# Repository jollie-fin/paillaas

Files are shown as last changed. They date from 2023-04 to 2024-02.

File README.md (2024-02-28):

# paillaas

## Context

I had decided in 2021 to leave my job and start a business, Kaukolab, to develop tools for better remote learning :

I have fond memories of session of lab work during my studies. Unfortunately, they are hard to do with remote learning. The only offers I saw on the market during my research were either based on simulations, with lots of simplification compared to the real world, or based on a few video of real experiments, but with almost no user input. Part of the experience of lab work is to experiment, break things, discover what is true and not simply check what you know is true is true.

My idea was to have real physical experiments users could connect to through Internet

## Lego prototype

A fun demonstration, where a user could control a pendulum hidden under my bed through a web interface.

The stack was the following :

- A pendulum in LEGO was hanged under my bed
- An EV3 brick with a flywheel was running a micro python kernel was communicating through an SSH connection.
  Its main tasks were : - receiving commands : - shorten/lenghten the pendulum - change how the the flywheel was controlled - retrieving and transmitting measurements from sensors - angle to the vertical - executing a simple kernel to control the flywheel
- An RPI was :
  - connected through ssh to the EV3
  - running a nodejs server that would exchange with EV3 and with a puppeteer instance
  - running a puppeteer instance that would transmit through WebRTC telemetry to a peer user, transmit a videofeed, and receive commands for the EV3
  - running a Discord bot that allowed remote management from my phone
- A remote server was :
  - serving an HTML page to the puppeteer instance on the RPI
  - serving an HTML page to end-users.
    The page was : - establishing a WebRTC connection with the RPI - displaying the telemetry to the user - allowing the user to define their own data to display through a DSL

This made for a weird stack, but it was reliable enough for me to make real demo of the concept I had.

I'm sadden that I wasn't able to push this prototype beyond it's MVP status. I had big projects like a Michelson interferometer totally controlled through internet

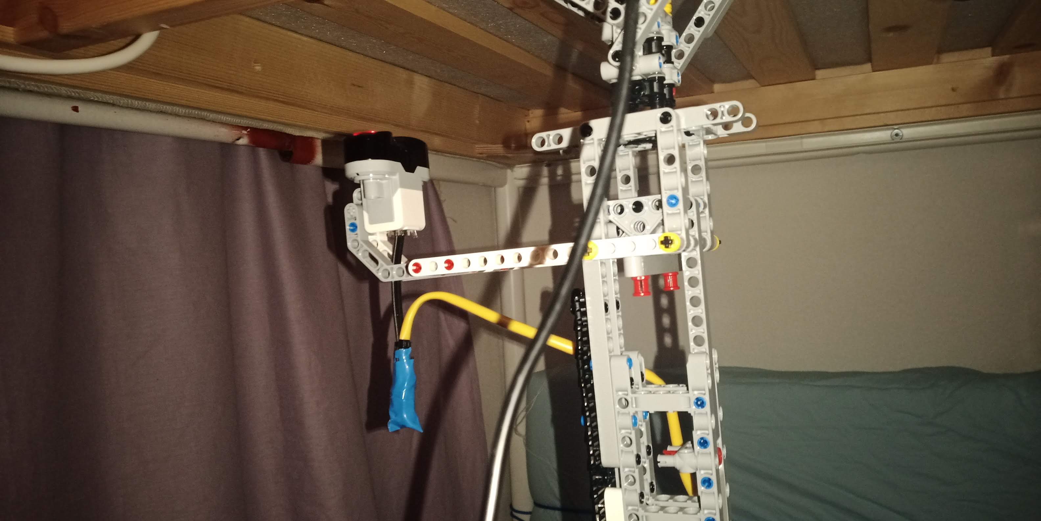
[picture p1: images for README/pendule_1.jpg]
Pendulum Angle measurement

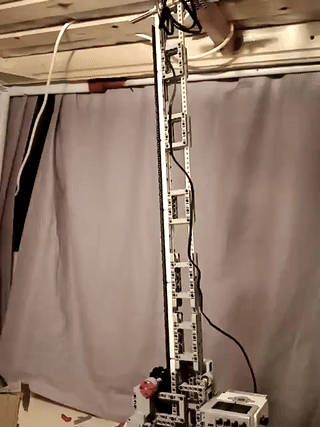
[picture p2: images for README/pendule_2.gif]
Pendulum video

Pendulum video

Some files were unfortunately lost, so I don't have a good showcase of it

## PCB design

A few pcb were designed during this adventure. Since it was in the middle of component crisis, I had to change quite a few the design, depending on component availabilities.

In hindsight, just buying a Duet Board would have been the best, but prices at that time were prohibitive

### Ethernet2serial

This is a simple serial converter, based on an atmega and an ENC28J60

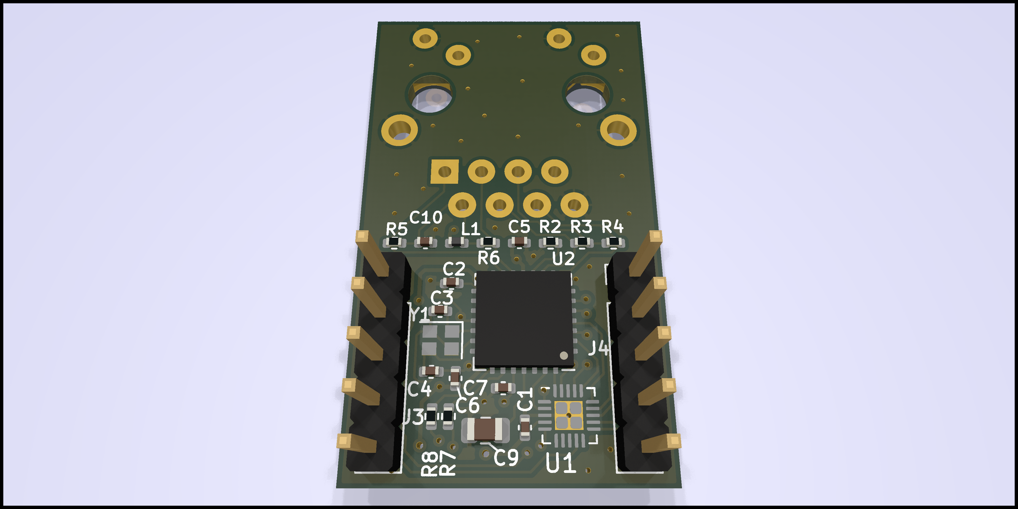
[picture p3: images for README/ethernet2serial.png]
main view Ethernet2Serial


### Motherboard

This aimed at connecting a Compute Module 4 to stepper motor drivers.

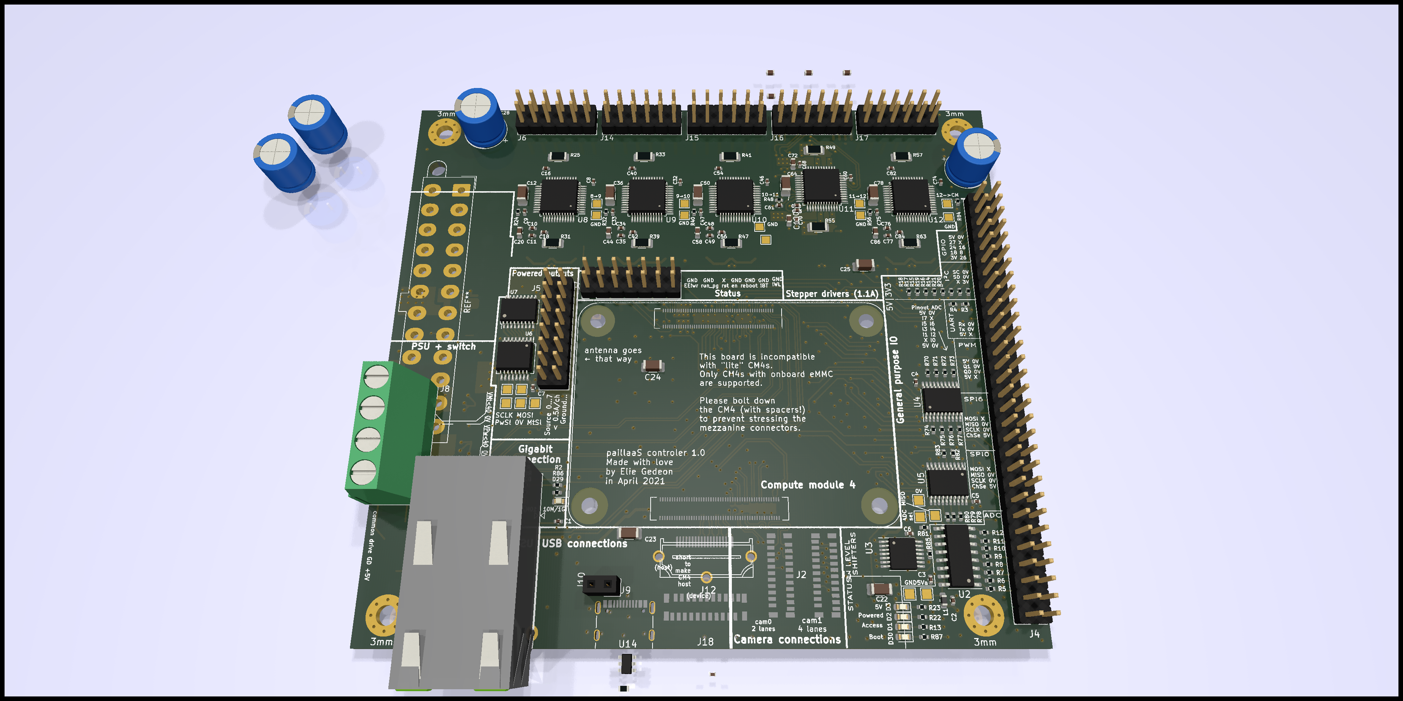
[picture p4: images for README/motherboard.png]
main view Motherboard


### Motherboard ITX-form-factor

This aimed at connecting a Compute Module 4 to stepper motor drivers. It also provides HDMI, DSI and CSI connections.

It also means I had to take care of high speed routing, with controlled impedance and differential pairs

It uses ITX screw holes, the idea being of using ITX cases

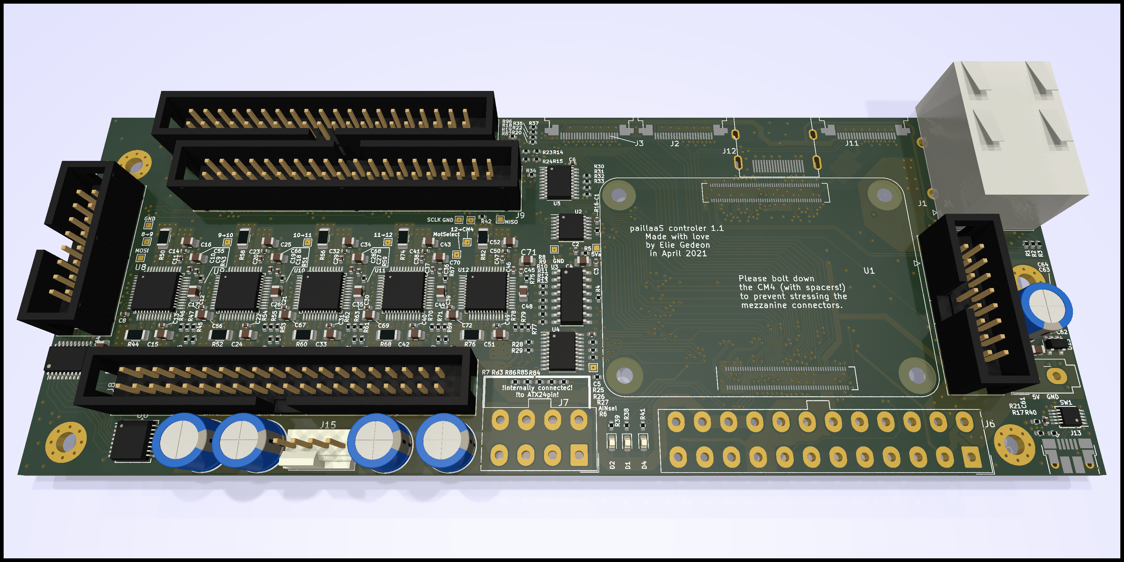
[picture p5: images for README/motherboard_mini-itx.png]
main view Motherboard


### USB2stepper

This was the final board. It is a 4 steppers board controlled by a RPI Pico, using TMC2208

A few interesting facts :

- TMC2208 were used at the limit of what they can handle
  - It means quite a bit of heat dissipation
  - Thermal vias were used to connect to the bottom side
  - A heatsink was bolted to the underside
  - To prevent short-circuit, no via (beside GND) could be used, forcing the design to be fully single layer under the heatsink
- The layer stackup was somewhat none conventional :
  - Top: signal
  - In1: GND
  - In2: GND/Power
  - Bottom: GND/Signal
  - The traces on the bottom layer were routed only over the ground plane part of In2

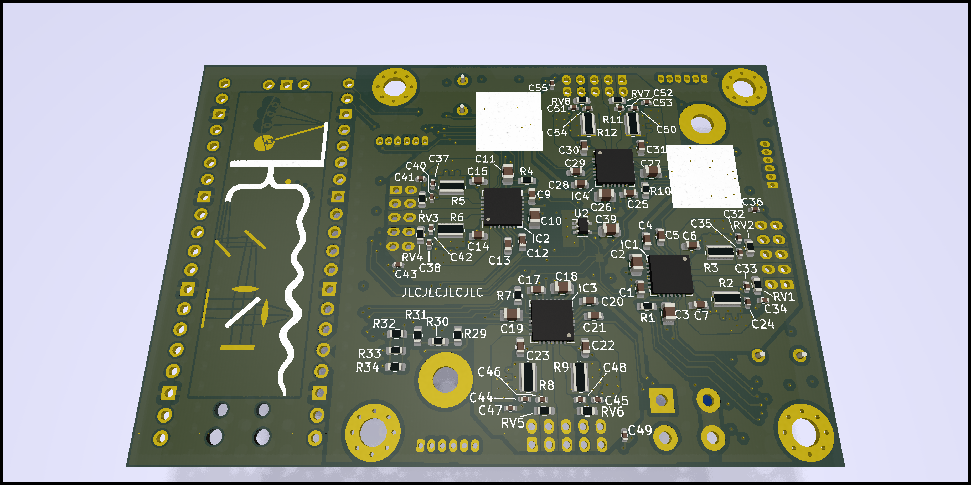
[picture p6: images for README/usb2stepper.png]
main view USB2stepper

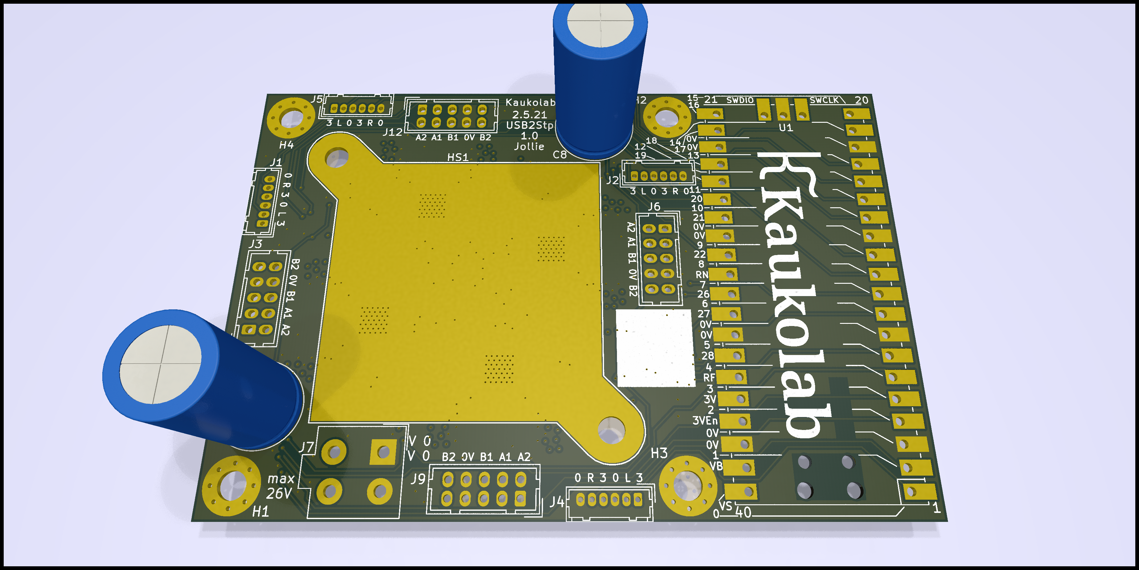
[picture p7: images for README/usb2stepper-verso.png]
underside view USB2stepper

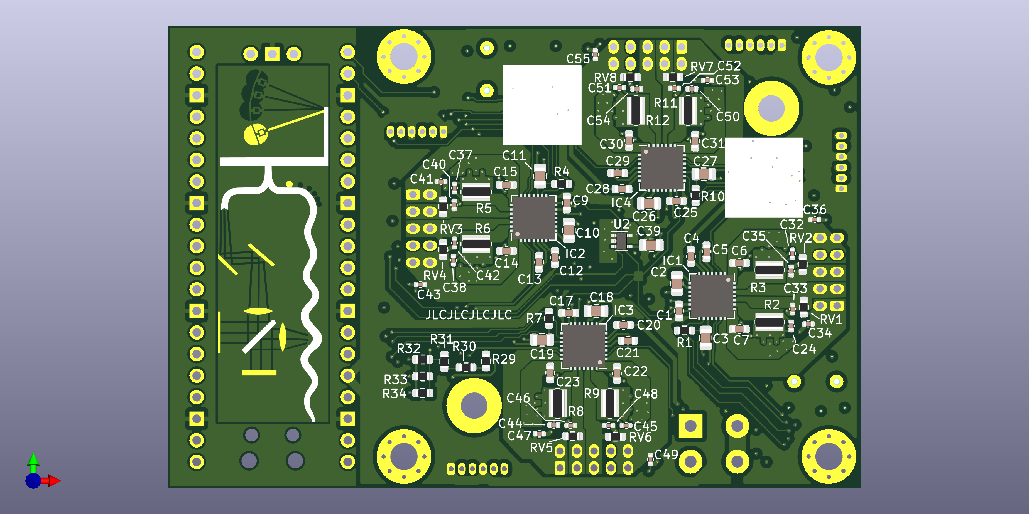
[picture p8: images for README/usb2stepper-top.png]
top view USB2stepper

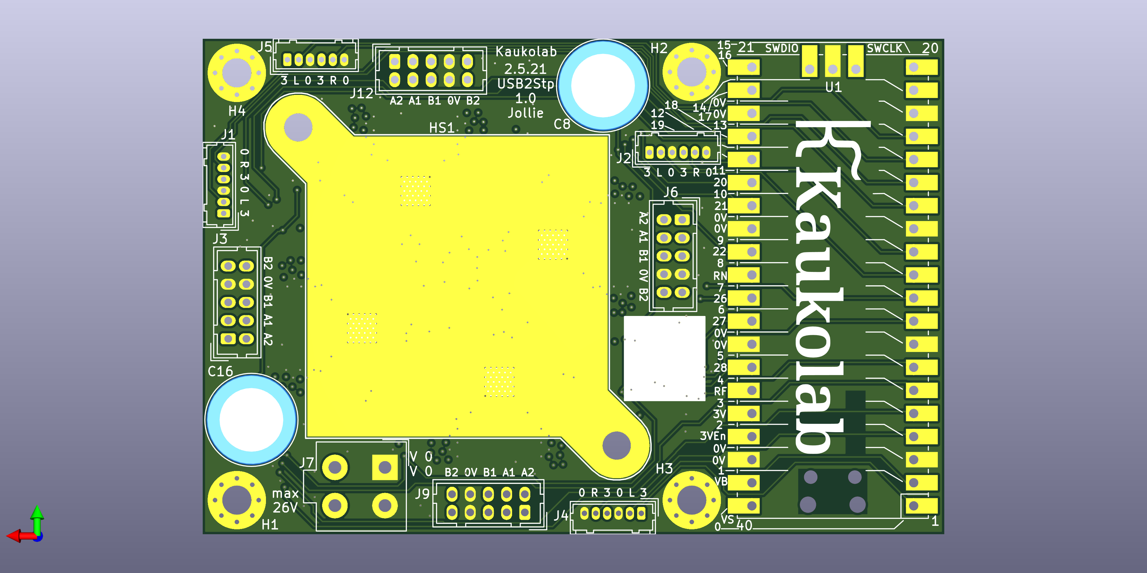
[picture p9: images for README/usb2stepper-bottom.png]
bottom view USB2stepper


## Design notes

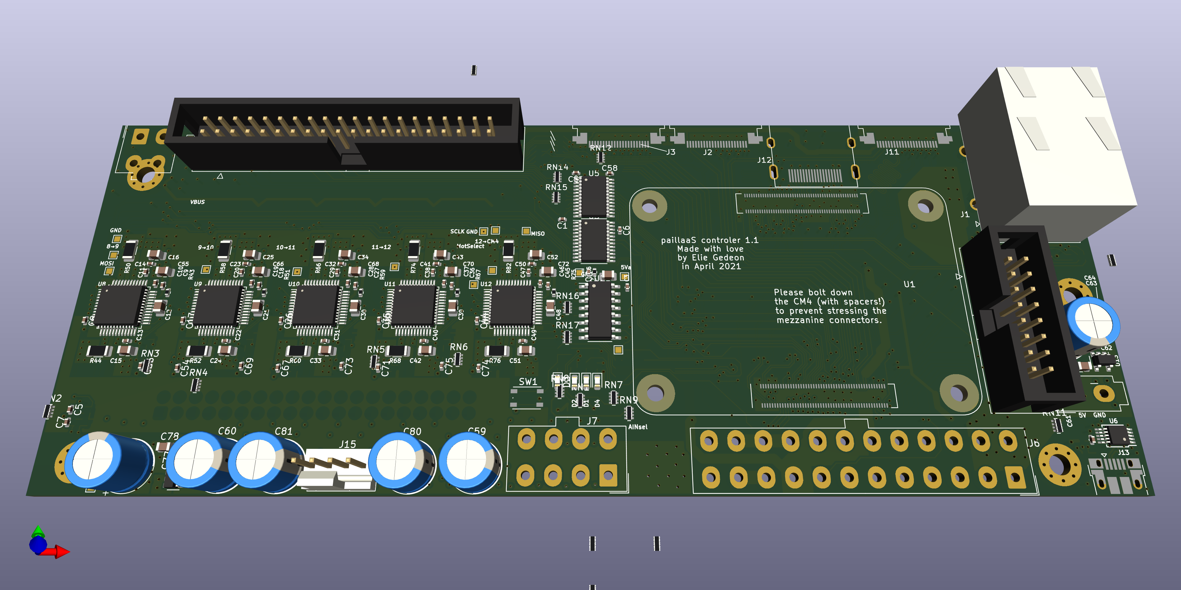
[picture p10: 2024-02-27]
images for README/motherboard_mini-itx_2209.png

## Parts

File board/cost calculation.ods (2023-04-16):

Nb | 100
PCB
width | height | area | Job fee | Price per area | Subtotal | Price per board
10 | 10 | 100 | 12.30 € | 0.19 € | 12.30 € | 0.12 €
Parts
Price mouser per board | Job fee | Handling fee | Subtotal | Price per board
60.00 € | 3.00 € | 20.00% | 7,203.00 € | 72.03 €
Stencil
Job fee | Price per area | Subtotal | Price per board
10.00 € | 0.095 € | 10.00 € | 0.10 €
Assembly
Job fee | Nb parts | Hand solder | Price per parts | Price of parts | Handling fee | Price handling | Nb components | Placement fee | Price placement | Subtotal | Price per board
75.00 € | 56 | 14 | 4.50 € | 189.00 € | 0.01 € | 100.00 € | 239 | 0.05 € | 1,195.00 € | 1,559.00 € | 15.59 €
 |  |  | 42
 | Total | Price per board
 | 8,784.30 € | 87.84 €

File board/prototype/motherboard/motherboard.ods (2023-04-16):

Source: | /home/phi/dev/paillaaS/board/prototype/motherboard/motherboard.sch
Date: | dim. 11 avril 2021 21:16:52
Tool: | Eeschema 5.1.9-73d0e3b20d~88~ubuntu20.04.1
Generator: | /usr/share/kicad/plugins/bom_csv_grouped_by_value.py
Component Count: | 239
Individual Components:
Item | Qty | Reference(s) |  |  |  |  | Value | LibPart | Footprint | Datasheet
 |  | C1 |  |  |  |  | 100n | Device:C | Capacitor_SMD:C_0402_1005Metric | ~
 |  | C2 |  |  |  |  | 100n | Device:C | Capacitor_SMD:C_0402_1005Metric | ~
 |  | C3 |  |  |  |  | 100n | Device:C | Capacitor_SMD:C_0402_1005Metric | ~
 |  | C4 |  |  |  |  | 100n | Device:C | Capacitor_SMD:C_0402_1005Metric | ~
 |  | C5 |  |  |  |  | 100n | Device:C | Capacitor_SMD:C_0402_1005Metric | ~
 |  | C6 |  |  |  |  | 100n | Device:C | Capacitor_SMD:C_0402_1005Metric | ~
 |  | C7 |  |  |  |  | 100n | Device:C | Capacitor_SMD:C_0402_1005Metric | ~
 |  | C8 |  |  |  |  | 100n | Device:C | Capacitor_SMD:C_0402_1005Metric | ~
 |  | C9 |  |  |  |  | 1u | Device:C | Capacitor_SMD:C_0402_1005Metric | ~
 |  | C10 |  |  |  |  | 22n | Device:C | Capacitor_SMD:C_0402_1005Metric | ~
 |  | C11 |  |  |  |  | 100n | Device:C | Capacitor_SMD:C_0402_1005Metric | ~
 |  | C12 |  |  |  |  | 10u | Device:C | Capacitor_SMD:C_1206_3216Metric | ~
 |  | C13 |  |  |  |  | 100n | Device:C | Capacitor_SMD:C_0402_1005Metric | ~
 |  | C14 |  |  |  |  | 470p | Device:C | Capacitor_SMD:C_0402_1005Metric | ~
 |  | C15 |  |  |  |  | 470p | Device:C | Capacitor_SMD:C_0402_1005Metric | ~
 |  | C16 |  |  |  |  | 100n | Device:C | Capacitor_SMD:C_0402_1005Metric | ~
 |  | C17 |  |  |  |  | 470p | Device:C | Capacitor_SMD:C_0402_1005Metric | ~
 |  | C18 |  |  |  |  | 100n | Device:C | Capacitor_SMD:C_0402_1005Metric | ~
 |  | C19 |  |  |  |  | 470p | Device:C | Capacitor_SMD:C_0402_1005Metric | ~
 |  | C20 |  |  |  |  | 1u | Device:C | Capacitor_SMD:C_0603_1608Metric | ~
 |  | C21 |  |  |  |  | 100n | Device:C | Capacitor_SMD:C_0402_1005Metric | ~
 |  | C22 |  |  |  |  | 10u | Device:C | Capacitor_SMD:C_1206_3216Metric | ~
 |  | C23 |  |  |  |  | 10u | Device:C | Capacitor_SMD:C_1206_3216Metric | ~
 |  | C24 |  |  |  |  | 10u | Device:C | Capacitor_SMD:C_1206_3216Metric | ~
 |  | C25 |  |  |  |  | 10u | Device:C | Capacitor_SMD:C_1206_3216Metric | ~
 |  | C26 |  |  |  |  | 10u | Device:C | Capacitor_SMD:C_1206_3216Metric | ~
 |  | C27 |  |  |  |  | 10u | Device:C | Capacitor_SMD:C_1206_3216Metric | ~
 |  | C28 |  |  |  |  | 100u | Device:CP | Capacitor_THT:CP_Radial_D8.0mm_P3.50mm | ~
 |  | C29 |  |  |  |  | 100u | Device:CP | Capacitor_THT:CP_Radial_D8.0mm_P3.50mm | ~
 |  | C30 |  |  |  |  | 10n | Device:C | Capacitor_SMD:C_0402_1005Metric | ~
 |  | C31 |  |  |  |  | 100u | Device:CP | Capacitor_THT:CP_Radial_D8.0mm_P3.50mm | ~
 |  | C32 |  |  |  |  | 100n | Device:C | Capacitor_SMD:C_0402_1005Metric | ~
 |  | C33 |  |  |  |  | 1u | Device:C | Capacitor_SMD:C_0402_1005Metric | ~
 |  | C34 |  |  |  |  | 22n | Device:C | Capacitor_SMD:C_0402_1005Metric | ~
 |  | C35 |  |  |  |  | 100n | Device:C | Capacitor_SMD:C_0402_1005Metric | ~
 |  | C36 |  |  |  |  | 10u | Device:C | Capacitor_SMD:C_1206_3216Metric | ~
 |  | C37 |  |  |  |  | 100n | Device:C | Capacitor_SMD:C_0402_1005Metric | ~
 |  | C38 |  |  |  |  | 470p | Device:C | Capacitor_SMD:C_0402_1005Metric | ~
 |  | C39 |  |  |  |  | 470p | Device:C | Capacitor_SMD:C_0402_1005Metric | ~
 |  | C40 |  |  |  |  | 100n | Device:C | Capacitor_SMD:C_0402_1005Metric | ~
 |  | C41 |  |  |  |  | 470p | Device:C | Capacitor_SMD:C_0402_1005Metric | ~
 |  | C42 |  |  |  |  | 100n | Device:C | Capacitor_SMD:C_0402_1005Metric | ~
 |  | C43 |  |  |  |  | 470p | Device:C | Capacitor_SMD:C_0402_1005Metric | ~
 |  | C44 |  |  |  |  | 1u | Device:C | Capacitor_SMD:C_0603_1608Metric | ~
 |  | C45 |  |  |  |  | 100n | Device:C | Capacitor_SMD:C_0402_1005Metric | ~
 |  | C46 |  |  |  |  | 100n | Device:C | Capacitor_SMD:C_0402_1005Metric | ~
 |  | C47 |  |  |  |  | 1u | Device:C | Capacitor_SMD:C_0402_1005Metric | ~
 |  | C48 |  |  |  |  | 22n | Device:C | Capacitor_SMD:C_0402_1005Metric | ~
 |  | C49 |  |  |  |  | 100n | Device:C | Capacitor_SMD:C_0402_1005Metric | ~
 |  | C50 |  |  |  |  | 10u | Device:C | Capacitor_SMD:C_1206_3216Metric | ~
 |  | C51 |  |  |  |  | 100n | Device:C | Capacitor_SMD:C_0402_1005Metric | ~
 |  | C52 |  |  |  |  | 470p | Device:C | Capacitor_SMD:C_0402_1005Metric | ~
 |  | C53 |  |  |  |  | 470p | Device:C | Capacitor_SMD:C_0402_1005Metric | ~
 |  | C54 |  |  |  |  | 100n | Device:C | Capacitor_SMD:C_0402_1005Metric | ~
 |  | C55 |  |  |  |  | 470p | Device:C | Capacitor_SMD:C_0402_1005Metric | ~
 |  | C56 |  |  |  |  | 100n | Device:C | Capacitor_SMD:C_0402_1005Metric | ~
 |  | C57 |  |  |  |  | 470p | Device:C | Capacitor_SMD:C_0402_1005Metric | ~
 |  | C58 |  |  |  |  | 1u | Device:C | Capacitor_SMD:C_0603_1608Metric | ~
 |  | C59 |  |  |  |  | 100n | Device:C | Capacitor_SMD:C_0402_1005Metric | ~
 |  | C60 |  |  |  |  | 100n | Device:C | Capacitor_SMD:C_0402_1005Metric | ~
 |  | C61 |  |  |  |  | 1u | Device:C | Capacitor_SMD:C_0402_1005Metric | ~
 |  | C62 |  |  |  |  | 22n | Device:C | Capacitor_SMD:C_0402_1005Metric | ~
 |  | C63 |  |  |  |  | 100n | Device:C | Capacitor_SMD:C_0402_1005Metric | ~
 |  | C64 |  |  |  |  | 10u | Device:C | Capacitor_SMD:C_1206_3216Metric | ~
 |  | C65 |  |  |  |  | 100n | Device:C | Capacitor_SMD:C_0402_1005Metric | ~
 |  | C66 |  |  |  |  | 470p | Device:C | Capacitor_SMD:C_0402_1005Metric | ~
 |  | C67 |  |  |  |  | 470p | Device:C | Capacitor_SMD:C_0402_1005Metric | ~
 |  | C68 |  |  |  |  | 100n | Device:C | Capacitor_SMD:C_0402_1005Metric | ~
 |  | C69 |  |  |  |  | 470p | Device:C | Capacitor_SMD:C_0402_1005Metric | ~
 |  | C70 |  |  |  |  | 100n | Device:C | Capacitor_SMD:C_0402_1005Metric | ~
 |  | C71 |  |  |  |  | 470p | Device:C | Capacitor_SMD:C_0402_1005Metric | ~
 |  | C72 |  |  |  |  | 1u | Device:C | Capacitor_SMD:C_0603_1608Metric | ~
 |  | C73 |  |  |  |  | 100n | Device:C | Capacitor_SMD:C_0402_1005Metric | ~
 |  | C74 |  |  |  |  | 100n | Device:C | Capacitor_SMD:C_0402_1005Metric | ~
 |  | C75 |  |  |  |  | 1u | Device:C | Capacitor_SMD:C_0402_1005Metric | ~
 |  | C76 |  |  |  |  | 22n | Device:C | Capacitor_SMD:C_0402_1005Metric | ~
 |  | C77 |  |  |  |  | 100n | Device:C | Capacitor_SMD:C_0402_1005Metric | ~
 |  | C78 |  |  |  |  | 10u | Device:C | Capacitor_SMD:C_1206_3216Metric | ~
 |  | C79 |  |  |  |  | 100n | Device:C | Capacitor_SMD:C_0402_1005Metric | ~
 |  | C80 |  |  |  |  | 470p | Device:C | Capacitor_SMD:C_0402_1005Metric | ~
 |  | C81 |  |  |  |  | 470p | Device:C | Capacitor_SMD:C_0402_1005Metric | ~
 |  | C82 |  |  |  |  | 100n | Device:C | Capacitor_SMD:C_0402_1005Metric | ~
 |  | C83 |  |  |  |  | 470p | Device:C | Capacitor_SMD:C_0402_1005Metric | ~
 |  | C84 |  |  |  |  | 100n | Device:C | Capacitor_SMD:C_0402_1005Metric | ~
 |  | C85 |  |  |  |  | 470p | Device:C | Capacitor_SMD:C_0402_1005Metric | ~
 |  | C86 |  |  |  |  | 1u | Device:C | Capacitor_SMD:C_0603_1608Metric | ~
 |  | C87 |  |  |  |  | 100n | Device:C | Capacitor_SMD:C_0402_1005Metric | ~
 |  | C88 |  |  |  |  | 2n7 | Device:C | Capacitor_SMD:C_0402_1005Metric | ~
 |  | C89 |  |  |  |  | 100n | Device:C | Capacitor_SMD:C_0402_1005Metric | ~
 |  | C90 |  |  |  |  | 33p | Device:C | Capacitor_SMD:C_0402_1005Metric | ~
 |  | C91 |  |  |  |  | 100u | Device:CP | Capacitor_THT:CP_Radial_D8.0mm_P3.50mm | ~
 |  | C92 |  |  |  |  | 10n | Device:C | Capacitor_SMD:C_0402_1005Metric | ~
 |  | C93 |  |  |  |  | 47p | Device:C | Capacitor_SMD:C_0402_1005Metric | ~
 |  | C94 |  |  |  |  | 22u | Device:C | Capacitor_SMD:C_1206_3216Metric | ~
 |  | C95 |  |  |  |  | 22u | Device:C | Capacitor_SMD:C_1206_3216Metric | ~
 |  | C96 |  |  |  |  | 22u | Device:C | Capacitor_SMD:C_1206_3216Metric | ~
 |  | C97 |  |  |  |  | 1u | Device:C | Capacitor_SMD:C_0603_1608Metric | ~
 |  | C98 |  |  |  |  | 1u | Device:C | Capacitor_SMD:C_0603_1608Metric | ~
 |  | C99 |  |  |  |  | 1u | Device:C | Capacitor_SMD:C_0603_1608Metric | ~
 |  | C100 |  |  |  |  | 1u | Device:C | Capacitor_SMD:C_0603_1608Metric | ~
 |  | C101 |  |  |  |  | 1u | Device:C | Capacitor_SMD:C_0603_1608Metric | ~
 |  | D1 |  |  |  |  | GREEN | Device:LED | LED_SMD:LED_0603_1608Metric | ~
 |  | D2 |  |  |  |  | RED | Device:LED | LED_SMD:LED_0603_1608Metric | ~
 |  | D3 |  |  |  |  | BLUE | Device:LED | LED_SMD:LED_0603_1608Metric | ~
 |  | D4 |  |  |  |  | SP0505BAHT | Power_Protection:SP0505BAHT | Package_TO_SOT_SMD:SOT-23-6 | http://www.littelfuse.com/~/media/files/littelfuse/technical%20resources/documents/data%20sheets/sp05xxba.pdf
 |  | D5 |  |  |  |  | SP0505BAHT | Power_Protection:SP0505BAHT | Package_TO_SOT_SMD:SOT-23-6 | http://www.littelfuse.com/~/media/files/littelfuse/technical%20resources/documents/data%20sheets/sp05xxba.pdf
 |  | D6 |  |  |  |  | SP0505BAHT | Power_Protection:SP0505BAHT | Package_TO_SOT_SMD:SOT-23-6 | http://www.littelfuse.com/~/media/files/littelfuse/technical%20resources/documents/data%20sheets/sp05xxba.pdf
 |  | D7 |  |  |  |  | SP0505BAHT | Power_Protection:SP0505BAHT | Package_TO_SOT_SMD:SOT-23-6 | http://www.littelfuse.com/~/media/files/littelfuse/technical%20resources/documents/data%20sheets/sp05xxba.pdf
 |  | D8 |  |  |  |  | SMBJ43A | Diode:SM6T22A | Diode_SMD:D_SMB | https://www.st.com/resource/en/datasheet/sm6t.pdf
 |  | D9 |  |  |  |  | SMBJ43A | Diode:SM6T22A | Diode_SMD:D_SMB | https://www.st.com/resource/en/datasheet/sm6t.pdf
 |  | D10 |  |  |  |  | SP0505BAHT | Power_Protection:SP0505BAHT | Package_TO_SOT_SMD:SOT-23-6 | http://www.littelfuse.com/~/media/files/littelfuse/technical%20resources/documents/data%20sheets/sp05xxba.pdf
 |  | D26 |  |  |  |  | SDT8A60VP5 | Device:D_Schottky | Diode_SMD:D_PowerDI-5 | ~
 |  | D27 |  |  |  |  | SDT8A60VP5 | Device:D_Schottky | Diode_SMD:D_PowerDI-5 | ~
 |  | D29 |  |  |  |  | LED | Device:LED | LED_SMD:LED_0603_1608Metric | ~
 |  | D30 |  |  |  |  | YELLOW | Device:LED | LED_SMD:LED_0603_1608Metric | ~
 |  | H1 |  |  |  |  | MountingHole_Pad | Mechanical:MountingHole_Pad | MountingHole:MountingHole_3.2mm_M3_Pad_Via | ~
 |  | H2 |  |  |  |  | MountingHole_Pad | Mechanical:MountingHole_Pad | MountingHole:MountingHole_3.2mm_M3_Pad_Via | ~
 |  | H3 |  |  |  |  | MountingHole_Pad | Mechanical:MountingHole_Pad | MountingHole:MountingHole_3.2mm_M3_Pad_Via | ~
 |  | H4 |  |  |  |  | MountingHole_Pad | Mechanical:MountingHole_Pad | MountingHole:MountingHole_3.2mm_M3_Pad_Via | ~
 |  | J1 |  |  |  |  | JK0654218Z | Connector:JK0654219 | Connector_RJ:RJ45_Pulse_JK0654219NL_Horizontal | https://media.digikey.com/pdf/Data%20Sheets/Pulse%20PDFs/JK%20Series.pdf
 |  | J2 |  |  |  |  | Conn_01x22_MountingPin | Connector_Generic_MountingPin:Conn_01x22_MountingPin | library:5019512230_1x22-1MP_P0.5mm_Vertical | ~
 |  | J3 |  |  |  |  | Conn_01x22_MountingPin | Connector_Generic_MountingPin:Conn_01x22_MountingPin | library:5019512230_1x22-1MP_P0.5mm_Vertical | ~
 |  | J4 |  |  |  |  | Conn_02x30_Odd_Even | Connector_Generic:Conn_02x30_Odd_Even | Connector_PinHeader_2.54mm:PinHeader_2x30_P2.54mm_Vertical | ~
 |  | J5 |  |  |  |  | Conn_02x08_Odd_Even | Connector_Generic:Conn_02x08_Odd_Even | Connector_PinHeader_2.54mm:PinHeader_2x08_P2.54mm_Vertical | ~
 |  | J6 |  |  |  |  | pin_header_02x06 | Connector_Generic:Conn_02x06_Odd_Even | Connector_PinHeader_2.54mm:PinHeader_2x06_P2.54mm_Vertical | ~
 |  | J7 |  |  |  |  | Conn_02x07_Odd_Even | Connector_Generic:Conn_02x07_Odd_Even | Connector_PinHeader_2.54mm:PinHeader_2x07_P2.54mm_Vertical | ~
 |  | J8 |  |  |  |  | Conn_01x04 | Connector_Generic:Conn_01x04 | TerminalBlock_Phoenix:TerminalBlock_Phoenix_MKDS-1,5-4-5.08_1x04_P5.08mm_Horizontal | ~
 |  | J9 |  |  |  |  | USB_C_Receptacle_USB2.0 | Connector:USB_C_Receptacle_USB2.0 | Connector_USB:USB_C_Receptacle_Palconn_UTC16-G | https://www.usb.org/sites/default/files/documents/usb_type-c.zip
 |  | J10 |  |  |  |  | Conn_01x02 | Connector_Generic:Conn_01x02 | Connector_PinSocket_2.54mm:PinSocket_1x02_P2.54mm_Vertical | ~
 |  | J11 |  |  |  |  | Conn_01x02 | Connector_Generic:Conn_01x02 | Connector_PinSocket_2.54mm:PinSocket_1x02_P2.54mm_Vertical | ~
 |  | J12 |  |  |  |  | HDMI_A | Connector:HDMI_A | library:HDMI_vertical_476591102 | https://en.wikipedia.org/wiki/HDMI
 |  | J13 |  |  |  |  | Conn_02x04_Odd_Even | Connector_Generic:Conn_02x04_Odd_Even | Connector_PinSocket_2.54mm:PinSocket_2x04_P2.54mm_Vertical | ~
 |  | J14 |  |  |  |  | pin_header_02x06 | Connector_Generic:Conn_02x06_Odd_Even | Connector_PinHeader_2.54mm:PinHeader_2x06_P2.54mm_Vertical | ~
 |  | J15 |  |  |  |  | pin_header_02x06 | Connector_Generic:Conn_02x06_Odd_Even | Connector_PinHeader_2.54mm:PinHeader_2x06_P2.54mm_Vertical | ~
 |  | J16 |  |  |  |  | pin_header_02x06 | Connector_Generic:Conn_02x06_Odd_Even | Connector_PinHeader_2.54mm:PinHeader_2x06_P2.54mm_Vertical | ~
 |  | J17 |  |  |  |  | pin_header_02x06 | Connector_Generic:Conn_02x06_Odd_Even | Connector_PinHeader_2.54mm:PinHeader_2x06_P2.54mm_Vertical | ~
 |  | J18 |  |  |  |  | Conn_01x22_MountingPin | Connector_Generic_MountingPin:Conn_01x22_MountingPin | library:5019512230_1x22-1MP_P0.5mm_Vertical | ~
 |  | L1 |  |  |  |  | 15uH | Device:L | Inductor_SMD:L_0603_1608Metric | ~
 |  | L2 |  |  |  |  | 3.6uH | Device:L | Inductor_SMD:L_1210_3225Metric | ~
 |  | R1 |  |  |  |  | 470 | Device:R | Resistor_SMD:R_0402_1005Metric | ~
 |  | R2 |  |  |  |  | 470 | Device:R | Resistor_SMD:R_0402_1005Metric | ~
 |  | R3 |  |  |  |  | 1K8 | Device:R | Resistor_SMD:R_0402_1005Metric | ~
 |  | R4 |  |  |  |  | 1K8 | Device:R | Resistor_SMD:R_0402_1005Metric | ~
 |  | R5 |  |  |  |  | 100 | Device:R | Resistor_SMD:R_0402_1005Metric | ~
 |  | R6 |  |  |  |  | 100 | Device:R | Resistor_SMD:R_0402_1005Metric | ~
 |  | R7 |  |  |  |  | 100 | Device:R | Resistor_SMD:R_0402_1005Metric | ~
 |  | R8 |  |  |  |  | 100 | Device:R | Resistor_SMD:R_0402_1005Metric | ~
 |  | R9 |  |  |  |  | 100 | Device:R | Resistor_SMD:R_0402_1005Metric | ~
 |  | R10 |  |  |  |  | 100 | Device:R | Resistor_SMD:R_0402_1005Metric | ~
 |  | R11 |  |  |  |  | 100 | Device:R | Resistor_SMD:R_0402_1005Metric | ~
 |  | R12 |  |  |  |  | 100 | Device:R | Resistor_SMD:R_0402_1005Metric | ~
 |  | R13 |  |  |  |  | 4K7 | Device:R | Resistor_SMD:R_0402_1005Metric | ~
 |  | R14 |  |  |  |  | 100 | Device:R | Resistor_SMD:R_0402_1005Metric | ~
 |  | R15 |  |  |  |  | 100 | Device:R | Resistor_SMD:R_0402_1005Metric | ~
 |  | R16 |  |  |  |  | 100 | Device:R | Resistor_SMD:R_0402_1005Metric | ~
 |  | R17 |  |  |  |  | 100 | Device:R | Resistor_SMD:R_0402_1005Metric | ~
 |  | R18 |  |  |  |  | 100 | Device:R | Resistor_SMD:R_0402_1005Metric | ~
 |  | R19 |  |  |  |  | 100 | Device:R | Resistor_SMD:R_0402_1005Metric | ~
 |  | R20 |  |  |  |  | 100 | Device:R | Resistor_SMD:R_0402_1005Metric | ~
 |  | R21 |  |  |  |  | 100 | Device:R | Resistor_SMD:R_0402_1005Metric | ~
 |  | R22 |  |  |  |  | 4K7 | Device:R | Resistor_SMD:R_0402_1005Metric | ~
 |  | R23 |  |  |  |  | 4K7 | Device:R | Resistor_SMD:R_0402_1005Metric | ~
 |  | R24 |  |  |  |  | 10 | Device:R | Resistor_SMD:R_0402_1005Metric | ~
 |  | R25 |  |  |  |  | 0.21 | Device:R | Resistor_SMD:R_1206_3216Metric | ~
 |  | R26 |  |  |  |  | 4K7 | Device:R | Resistor_SMD:R_0402_1005Metric | ~
 |  | R27 |  |  |  |  | 4K7 | Device:R | Resistor_SMD:R_0402_1005Metric | ~
 |  | R28 |  |  |  |  | 4K7 | Device:R | Resistor_SMD:R_0402_1005Metric | ~
 |  | R29 |  |  |  |  | 4K7 | Device:R | Resistor_SMD:R_0402_1005Metric | ~
 |  | R30 |  |  |  |  | 4K7 | Device:R | Resistor_SMD:R_0402_1005Metric | ~
 |  | R31 |  |  |  |  | 0.21 | Device:R | Resistor_SMD:R_1206_3216Metric | ~
 |  | R32 |  |  |  |  | 10 | Device:R | Resistor_SMD:R_0402_1005Metric | ~
 |  | R33 |  |  |  |  | 0.21 | Device:R | Resistor_SMD:R_1206_3216Metric | ~
 |  | R34 |  |  |  |  | 4K7 | Device:R | Resistor_SMD:R_0402_1005Metric | ~
 |  | R35 |  |  |  |  | 4K7 | Device:R | Resistor_SMD:R_0402_1005Metric | ~
 |  | R36 |  |  |  |  | 4K7 | Device:R | Resistor_SMD:R_0402_1005Metric | ~
 |  | R37 |  |  |  |  | 4K7 | Device:R | Resistor_SMD:R_0402_1005Metric | ~
 |  | R38 |  |  |  |  | 4K7 | Device:R | Resistor_SMD:R_0402_1005Metric | ~
 |  | R39 |  |  |  |  | 0.21 | Device:R | Resistor_SMD:R_1206_3216Metric | ~
 |  | R40 |  |  |  |  | 10 | Device:R | Resistor_SMD:R_0402_1005Metric | ~
 |  | R41 |  |  |  |  | 0.21 | Device:R | Resistor_SMD:R_1206_3216Metric | ~
 |  | R42 |  |  |  |  | 4K7 | Device:R | Resistor_SMD:R_0402_1005Metric | ~
 |  | R43 |  |  |  |  | 4K7 | Device:R | Resistor_SMD:R_0402_1005Metric | ~
 |  | R44 |  |  |  |  | 4K7 | Device:R | Resistor_SMD:R_0402_1005Metric | ~
 |  | R45 |  |  |  |  | 4K7 | Device:R | Resistor_SMD:R_0402_1005Metric | ~
 |  | R46 |  |  |  |  | 4K7 | Device:R | Resistor_SMD:R_0402_1005Metric | ~
 |  | R47 |  |  |  |  | 0.21 | Device:R | Resistor_SMD:R_1206_3216Metric | ~
 |  | R48 |  |  |  |  | 10 | Device:R | Resistor_SMD:R_0402_1005Metric | ~
 |  | R49 |  |  |  |  | 0.21 | Device:R | Resistor_SMD:R_1206_3216Metric | ~
 |  | R50 |  |  |  |  | 4K7 | Device:R | Resistor_SMD:R_0402_1005Metric | ~
 |  | R51 |  |  |  |  | 4K7 | Device:R | Resistor_SMD:R_0402_1005Metric | ~
 |  | R52 |  |  |  |  | 4K7 | Device:R | Resistor_SMD:R_0402_1005Metric | ~
 |  | R53 |  |  |  |  | 4K7 | Device:R | Resistor_SMD:R_0402_1005Metric | ~
 |  | R54 |  |  |  |  | 4K7 | Device:R | Resistor_SMD:R_0402_1005Metric | ~
 |  | R55 |  |  |  |  | 0.21 | Device:R | Resistor_SMD:R_1206_3216Metric | ~
 |  | R56 |  |  |  |  | 10 | Device:R | Resistor_SMD:R_0402_1005Metric | ~
 |  | R57 |  |  |  |  | 0.21 | Device:R | Resistor_SMD:R_1206_3216Metric | ~
 |  | R58 |  |  |  |  | 4K7 | Device:R | Resistor_SMD:R_0402_1005Metric | ~
 |  | R59 |  |  |  |  | 4K7 | Device:R | Resistor_SMD:R_0402_1005Metric | ~
 |  | R60 |  |  |  |  | 4K7 | Device:R | Resistor_SMD:R_0402_1005Metric | ~
 |  | R61 |  |  |  |  | 4K7 | Device:R | Resistor_SMD:R_0402_1005Metric | ~
 |  | R62 |  |  |  |  | 4K7 | Device:R | Resistor_SMD:R_0402_1005Metric | ~
 |  | R63 |  |  |  |  | 0.21 | Device:R | Resistor_SMD:R_1206_3216Metric | ~
 |  | R64 |  |  |  |  | 15k8 | Device:R | Resistor_SMD:R_0402_1005Metric | ~
 |  | R65 |  |  |  |  | 115k 1% | Device:R | Resistor_SMD:R_0402_1005Metric | ~
 |  | R66 |  |  |  |  | 22k1 1% | Device:R | Resistor_SMD:R_0402_1005Metric | ~
 |  | R70 |  |  |  |  | 100 | Device:R | Resistor_SMD:R_0402_1005Metric | ~
 |  | R71 |  |  |  |  | 100 | Device:R | Resistor_SMD:R_0402_1005Metric | ~
 |  | R72 |  |  |  |  | 100 | Device:R | Resistor_SMD:R_0402_1005Metric | ~
 |  | R73 |  |  |  |  | 100 | Device:R | Resistor_SMD:R_0402_1005Metric | ~
 |  | R74 |  |  |  |  | 100 | Device:R | Resistor_SMD:R_0402_1005Metric | ~
 |  | R75 |  |  |  |  | 100 | Device:R | Resistor_SMD:R_0402_1005Metric | ~
 |  | R76 |  |  |  |  | 100 | Device:R | Resistor_SMD:R_0402_1005Metric | ~
 |  | R77 |  |  |  |  | 100 | Device:R | Resistor_SMD:R_0402_1005Metric | ~
 |  | R78 |  |  |  |  | 100 | Device:R | Resistor_SMD:R_0402_1005Metric | ~
 |  | R79 |  |  |  |  | 30 | Device:R | Resistor_SMD:R_0402_1005Metric | ~
 |  | R80 |  |  |  |  | 30 | Device:R | Resistor_SMD:R_0402_1005Metric | ~
 |  | R81 |  |  |  |  | 30 | Device:R | Resistor_SMD:R_0402_1005Metric | ~
 |  | R82 |  |  |  |  | 30 | Device:R | Resistor_SMD:R_0402_1005Metric | ~
 |  | R83 |  |  |  |  | 30 | Device:R | Resistor_SMD:R_0402_1005Metric | ~
 |  | R84 |  |  |  |  | 30 | Device:R | Resistor_SMD:R_0402_1005Metric | ~
 |  | R85 |  |  |  |  | 10k | Device:R | Resistor_SMD:R_0402_1005Metric | ~
 |  | R86 |  |  |  |  | 470 | Device:R | Resistor_SMD:R_0402_1005Metric | ~
 |  | R87 |  |  |  |  | 4K7 | Device:R | Resistor_SMD:R_0402_1005Metric | ~
 |  | R89 |  |  |  |  | R | Device:R | Resistor_SMD:R_1218_3246Metric | ~
 |  | TH1 |  |  |  |  | Thermistor_PTC | Device:Thermistor_PTC | Resistor_SMD:R_0603_1608Metric | ~
 |  | U1 |  |  |  |  | Compute_Module_4_Functional | Raspberry_Pi_Compute_Module_4:Compute_Module_4_Functional | RPi_Compute_Module_4:Raspberry-Pi-4-Compute-Module
 |  | U2 |  |  |  |  | MCP3008 | Analog_ADC:MCP3008 | Package_SO:SOIC-16_3.9x9.9mm_P1.27mm | http://ww1.microchip.com/downloads/en/DeviceDoc/21295d.pdf
 |  | U3 |  |  |  |  | 74LVC125 | 74xx:74LVC125 | Package_SO:TSSOP-14_4.4x5mm_P0.65mm | http://www.ti.com/lit/gpn/sn74LVC125
 |  | U4 |  |  |  |  | 74HCT244 | 74xx:74HC244 | Package_SO:TSSOP-20_4.4x6.5mm_P0.65mm | http://www.ti.com/lit/gpn/sn74LVC125
 |  | U5 |  |  |  |  | 74HCT244 | 74xx:74HC244 | Package_SO:TSSOP-20_4.4x6.5mm_P0.65mm | http://www.ti.com/lit/gpn/sn74LVC125
 |  | U6 |  |  |  |  | 74HC595 | 74xx:74HC595 | Package_SO:SSOP-16_5.3x6.2mm_P0.65mm | http://www.ti.com/lit/ds/symlink/sn74hc595.pdf
 |  | U7 |  |  |  |  | TBD62783A | Transistor_Array:TBD62783A | Package_SO:SSOP-18_4.4x6.5mm_P0.65mm | http://toshiba.semicon-storage.com/info/docget.jsp?did=30523&prodName=TBD62783APG
 |  | U8 |  |  |  |  | TMC5130A-TA | TMC5130:TMC5130A-TA | Package_QFP:TQFP-48-1EP_7x7mm_P0.5mm_EP5x5mm_ThermalVias
 |  | U9 |  |  |  |  | TMC5130A-TA | TMC5130:TMC5130A-TA | Package_QFP:TQFP-48-1EP_7x7mm_P0.5mm_EP5x5mm_ThermalVias
 |  | U10 |  |  |  |  | TMC5130A-TA | TMC5130:TMC5130A-TA | Package_QFP:TQFP-48-1EP_7x7mm_P0.5mm_EP5x5mm_ThermalVias
 |  | U11 |  |  |  |  | TMC5130A-TA | TMC5130:TMC5130A-TA | Package_QFP:TQFP-48-1EP_7x7mm_P0.5mm_EP5x5mm_ThermalVias
 |  | U12 |  |  |  |  | TMC5130A-TA | TMC5130:TMC5130A-TA | Package_QFP:TQFP-48-1EP_7x7mm_P0.5mm_EP5x5mm_ThermalVias
 |  | U13 |  |  |  |  | AP64501 | library:AP64501 | Package_SO:Diodes_SO-8EP | https://www.diodes.com/assets/Datasheets/AP64501.pdf
 |  | U14 |  |  |  |  | SN65220 | Power_Protection:SN65220 | Package_TO_SOT_SMD:SOT-23-6 | http://www.ti.com/lit/ds/symlink/sn65220.pdf
Collated Components:
Item | Qty | Reference(s) | Ppu | Sub |  | Mouser | Value | LibPart | Footprint | Datasheet
 |  |  |  | 52.09 € | 0.00 €
1 | 29 | C1, C2, C3, C4, C5, C6, C7, C8, C11, C13, C16, C18, C21, C32, C35, C37, C40, C42, C45, C46, C49, C51, C54, C56, C59, C60, C63, C65, C68, C70, C73, C74, C77, C79, C82, C84, C87, C89 | 0.026 € | 0.75 € | 0.75 € | 81-GCM155R71H104KE2J | 100n | Device:C | Capacitor_SMD:C_0402_1005Metric | ~
2 | 5 | C9, C33, C47, C61, C75 | 0.042 € | 0.21 € | 0.96 € | 187-CL21B105KBFNNNG | 1u | Device:C | Capacitor_SMD:C_0402_1005Metric | ~
3 | 7 | C10, C34, C48, C62, C76 | 0.030 € | 0.21 € | 1.17 € | 80-C0603C223K5R | 22n | Device:C | Capacitor_SMD:C_0402_1005Metric | ~
4 | 11 | C12, C22, C23, C24, C25, C26, C27, C36, C50, C64, C78 | 0.191 € | 2.10 € | 3.28 € | 187-CL31A106MBHNNNE | 10u | Device:C | Capacitor_SMD:C_1206_3216Metric | ~
5 | 0 | C14, C15, C17, C19, C38, C39, C41, C43, C52, C53, C55, C57, C66, C67, C69, C71, C80, C81, C83, C85 | 0.036 € | 0.00 € | 3.28 € |  | 470p | Device:C | Capacitor_SMD:C_0402_1005Metric | ~
6 | 10 | C20, C44, C58, C72, C86, C97, C98, C99, C100, C101 | 0.042 € | 0.42 € | 3.70 € | 187-CL21B105KBFNNNG | 1u | Device:C | Capacitor_SMD:C_0603_1608Metric | ~
7 | 4 | C28, C29, C31, C91 | 0.119 € | 0.48 € | 4.17 € | 140-REA101M1HBK0811P | 100u | Device:CP | Capacitor_THT:CP_Radial_D8.0mm_P3.50mm | ~
8 | 0 | C30, C92 | 0.036 € | 0.00 € | 4.17 € |  | 10n | Device:C | Capacitor_SMD:C_0402_1005Metric | ~
9 | 1 | C88 | 0.085 € | 0.09 € | 4.26 € | 77-VJ0402Y272KXAPBC | 2n7 | Device:C | Capacitor_SMD:C_0402_1005Metric | ~
10 | 1 | C90 | 0.026 € | 0.03 € | 4.28 € | 581-06035A330K | 33p | Device:C | Capacitor_SMD:C_0402_1005Metric | ~
11 | 1 | C93 | 0.035 € | 0.04 € | 4.32 € | 581-04025A470JAT4A | 47p | Device:C | Capacitor_SMD:C_0402_1005Metric | ~
12 | 3 | C94, C95, C96 | 0.063 € | 0.19 € | 4.51 € | 791-0805X226M6R3CT | 22u | Device:C | Capacitor_SMD:C_1206_3216Metric | ~
13 | 5 | D1 | 0.117 € | 0.59 € | 5.09 € | 710-150060GS75000 | GREEN | Device:LED | LED_SMD:LED_0603_1608Metric | ~
14 | 0 | D2 | 0.117 € | 0.00 € | 5.09 € |  | RED | Device:LED | LED_SMD:LED_0603_1608Metric | ~
15 | 0 | D3 | 0.117 € | 0.00 € | 5.09 € |  | BLUE | Device:LED | LED_SMD:LED_0603_1608Metric | ~
16 | 6 | D4, D5, D6, D7, D10 | 0.687 € | 4.12 € | 9.21 € |  | SP0505BAHT | Power_Protection:SP0505BAHT | Package_TO_SOT_SMD:SOT-23-6 | http://www.littelfuse.com/~/media/files/littelfuse/technical%20resources/documents/data%20sheets/sp05xxba.pdf
17 | 2 | D8, D9 | 0.241 € | 0.48 € | 9.70 € |  | SMBJ43A | Diode:SM6T22A | Diode_SMD:D_SMB | https://www.st.com/resource/en/datasheet/sm6t.pdf
18 | 2 | D26, D27 | 0.373 € | 0.75 € | 10.44 € | /!\ no stock | SDT8A60VP5 | Device:D_Schottky | Diode_SMD:D_PowerDI-5 | ~
19 | 0 | D29 | 0.117 € | 0.00 € | 10.44 € |  | LED | Device:LED | LED_SMD:LED_0603_1608Metric | ~
20 | 0 | D30 | 0.117 € | 0.00 € | 10.44 € |  | YELLOW | Device:LED | LED_SMD:LED_0603_1608Metric | ~
21 | 4 | H1, H2, H3, H4 | 0.000 € | 0.00 € | 10.44 € |  | MountingHole_Pad | Mechanical:MountingHole_Pad | MountingHole:MountingHole_3.2mm_M3_Pad_Via | ~
22 | 1 | J1 | 3.450 € | 3.45 € | 13.89 € |  | 523-RJMG2310228A0ER | Connector:JK0654219 | Connector_RJ:RJ45_Pulse_JK0654219NL_Horizontal | https://media.digikey.com/pdf/Data%20Sheets/Pulse%20PDFs/JK%20Series.pdf
23 | 3 | J2, J3, J18 | 0.504 € | 1.51 € | 15.40 € | 538-501951-2230 | Conn_01x22_MountingPin | Connector_Generic_MountingPin:Conn_01x22_MountingPin | library:5019512230_1x22-1MP_P0.5mm_Vertical | ~
24 | 1 | J4 | 0.000 € | 0.00 € | 15.40 € |  | Conn_02x30_Odd_Even | Connector_Generic:Conn_02x30_Odd_Even | Connector_PinHeader_2.54mm:PinHeader_2x30_P2.54mm_Vertical | ~
25 | 1 | J5 | 0.000 € | 0.00 € | 15.40 € |  | Conn_02x08_Odd_Even | Connector_Generic:Conn_02x08_Odd_Even | Connector_PinHeader_2.54mm:PinHeader_2x08_P2.54mm_Vertical | ~
26 | 5 | J6, J14, J15, J16, J17 | 0.000 € | 0.00 € | 15.40 € |  | pin_header_02x06 | Connector_Generic:Conn_02x06_Odd_Even | Connector_PinHeader_2.54mm:PinHeader_2x06_P2.54mm_Vertical | ~
27 | 1 | J7 | 0.000 € | 0.00 € | 15.40 € |  | Conn_02x07_Odd_Even | Connector_Generic:Conn_02x07_Odd_Even | Connector_PinHeader_2.54mm:PinHeader_2x07_P2.54mm_Vertical | ~
28 | 1 | J8 | 0.000 € | 0.00 € | 15.40 € |  | Conn_01x04 | Connector_Generic:Conn_01x04 | TerminalBlock_Phoenix:TerminalBlock_Phoenix_MKDS-1,5-4-5.08_1x04_P5.08mm_Horizontal | ~
29 | 1 | J9 | 0.343 € | 0.34 € | 15.75 € | 490-UJ2-BH-W1-TH | USB_C_Receptacle_USB2.0 | Connector:USB_C_Receptacle_USB2.0 | Connector_USB:USB_C_Receptacle_Palconn_UTC16-G | https://www.usb.org/sites/default/files/documents/usb_type-c.zip
30 | 2 | J10, J11 | 0.000 € | 0.00 € | 15.75 € |  | Conn_01x02 | Connector_Generic:Conn_01x02 | Connector_PinSocket_2.54mm:PinSocket_1x02_P2.54mm_Vertical | ~
31 | 1 | J12 | 1.580 € | 1.58 € | 17.33 € | 538-47659-1102 | HDMI_A | Connector:HDMI_A | library:HDMI_vertical_476591102 | https://en.wikipedia.org/wiki/HDMI
32 | 1 | J13 | 0.000 € | 0.00 € | 17.33 € |  | Conn_02x04_Odd_Even | Connector_Generic:Conn_02x04_Odd_Even | Connector_PinSocket_2.54mm:PinSocket_2x04_P2.54mm_Vertical | ~
33 | 1 | L1 | 0.085 € | 0.09 € | 17.41 € | 815-AIML-0603-150KT | 15uH | Device:L | Inductor_SMD:L_0603_1608Metric | ~
34 | 1 | L2 | 0.351 € | 0.35 € | 17.76 € | 963-NRS8040T3R6NJGJ | 3.6uH | Device:L | Inductor_SMD:L_1210_3225Metric | ~
35 | 0 | R1, R2, R86 | 0.030 € | 0.00 € | 17.76 € |  | 470 | Device:R | Resistor_SMD:R_0402_1005Metric | ~
36 | 5 | R3, R4 | 0.019 € | 0.10 € | 17.86 € | 652-CR0805JW-182ELF | 1K8 | Device:R | Resistor_SMD:R_0402_1005Metric | ~
37 | 0 | R5, R6, R7, R8, R9, R10, R11, R12, R14, R15, R16, R17, R18, R19, R20, R21, R70, R71, R72, R73, R74, R75, R76, R77, R78 | 0.019 € | 0.00 € | 17.86 € |  | 100 | Device:R | Resistor_SMD:R_0402_1005Metric | ~
38 | 29 | R13, R22, R23, R26, R27, R28, R29, R30, R34, R35, R36, R37, R38, R42, R43, R44, R45, R46, R50, R51, R52, R53, R54, R58, R59, R60, R61, R62, R87 | 0.030 € | 0.87 € | 18.73 € |  | 4K7 | Device:R | Resistor_SMD:R_0402_1005Metric | ~
39 | 5 | R24, R32, R40, R48, R56 | 0.030 € | 0.15 € | 18.88 € |  | 10 | Device:R | Resistor_SMD:R_0402_1005Metric | ~
40 | 10 | R25, R31, R33, R39, R41, R47, R49, R55, R57, R63 | 0.084 € | 0.84 € | 19.72 € |  | 0.21 | Device:R | Resistor_SMD:R_1206_3216Metric | ~
41 | 1 | R64 | 0.030 € | 0.03 € | 19.75 € |  | 15k8 | Device:R | Resistor_SMD:R_0402_1005Metric | ~
42 | 1 | R65 | 0.030 € | 0.03 € | 19.78 € |  | 115k 1% | Device:R | Resistor_SMD:R_0402_1005Metric | ~
43 | 1 | R66 | 0.030 € | 0.03 € | 19.81 € |  | 22k1 1% | Device:R | Resistor_SMD:R_0402_1005Metric | ~
44 | 6 | R79, R80, R81, R82, R83, R84 | 0.030 € | 0.18 € | 19.99 € |  | 30 | Device:R | Resistor_SMD:R_0402_1005Metric | ~
45 | 1 | R85 | 0.030 € | 0.03 € | 20.02 € |  | 10k | Device:R | Resistor_SMD:R_0402_1005Metric | ~
46 | 1 | R89 | 0.030 € | 0.03 € | 20.05 € |  | R | Device:R | Resistor_SMD:R_1218_3246Metric | ~
47 | 1 | TH1 | 0.100 € | 0.10 € | 20.15 € |  | Thermistor_PTC | Device:Thermistor_PTC | Resistor_SMD:R_0603_1608Metric | ~
48 | 2 | U1 | 1.820 € | 3.64 € | 23.79 € | DF40HC(3.0)-100DS-0.4V | Compute_Module_4_Functional | Raspberry_Pi_Compute_Module_4:Compute_Module_4_Functional | RPi_Compute_Module_4:Raspberry-Pi-4-Compute-Module
49 | 1 | U2 | 1.950 € | 1.95 € | 25.74 € |  | MCP3008 | Analog_ADC:MCP3008 | Package_SO:SOIC-16_3.9x9.9mm_P1.27mm | http://ww1.microchip.com/downloads/en/DeviceDoc/21295d.pdf
50 | 1 | U3 | 0.296 € | 0.30 € | 26.03 € |  | 74LVC125 | 74xx:74LVC125 | Package_SO:TSSOP-14_4.4x5mm_P0.65mm | http://www.ti.com/lit/gpn/sn74LVC125
51 | 2 | U4, U5 | 0.480 € | 0.96 € | 26.99 € |  | 74HCT244 | 74xx:74HC244 | Package_SO:TSSOP-20_4.4x6.5mm_P0.65mm | http://www.ti.com/lit/gpn/sn74LVC125
52 | 1 | U6 | 0.500 € | 0.50 € | 27.49 € |  | 74HC595 | 74xx:74HC595 | Package_SO:SSOP-16_5.3x6.2mm_P0.65mm | http://www.ti.com/lit/ds/symlink/sn74hc595.pdf
53 | 1 | U7 | 1.400 € | 1.40 € | 28.89 € |  | TBD62783A | Transistor_Array:TBD62783A | Package_SO:SSOP-18_4.4x6.5mm_P0.65mm | http://toshiba.semicon-storage.com/info/docget.jsp?did=30523&prodName=TBD62783APG
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

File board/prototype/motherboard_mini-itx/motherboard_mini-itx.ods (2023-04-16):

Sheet: motherboard_mini-itx
Source: |  | /home/phi/dev/paillaaS/board/prototype/motherboard_mini-itx/motherboard_mini-itx.sch
Date: |  | lun. 19 avril 2021 18:44:23
Tool: |  | Eeschema 5.1.9-73d0e3b20d~88~ubuntu20.04.1
Generator: |  | /usr/share/kicad/plugins/bom_csv_grouped_by_value.py
Component Count: |  | 213
Individual Components:
Item |  | Qty |  |  |  |  |  | Reference(s) | Value | LibPart | Footprint | Datasheet
 |  |  |  |  |  |  |  | C1 | 100n | Device:C | Capacitor_SMD:C_0402_1005Metric | ~
 |  |  |  |  |  |  |  | C2 | 100n | Device:C | Capacitor_SMD:C_0402_1005Metric | ~
 |  |  |  |  |  |  |  | C3 | 100n | Device:C | Capacitor_SMD:C_0402_1005Metric | ~
 |  |  |  |  |  |  |  | C4 | 10u | Device:C | Capacitor_SMD:C_0805_2012Metric | ~
 |  |  |  |  |  |  |  | C5 | 1n | Device:C | Capacitor_SMD:C_0402_1005Metric | ~
 |  |  |  |  |  |  |  | C6 | 100n | Device:C | Capacitor_SMD:C_0402_1005Metric | ~
 |  |  |  |  |  |  |  | C7 | 1n | Device:C | Capacitor_SMD:C_0402_1005Metric | ~
 |  |  |  |  |  |  |  | C8 | 100n | Device:C | Capacitor_SMD:C_0402_1005Metric | ~
 |  |  |  |  |  |  |  | C9 | 100n | Device:C | Capacitor_SMD:C_0402_1005Metric | ~
 |  |  |  |  |  |  |  | C10 | 22n | Device:C | Capacitor_SMD:C_0402_1005Metric | ~
 |  |  |  |  |  |  |  | C11 | 100n | Device:C | Capacitor_SMD:C_0402_1005Metric | ~
 |  |  |  |  |  |  |  | C12 | 10u | Device:C | Capacitor_SMD:C_0805_2012Metric | ~
 |  |  |  |  |  |  |  | C13 | 100n | Device:C | Capacitor_SMD:C_0402_1005Metric | ~
 |  |  |  |  |  |  |  | C14 | 100n | Device:C | Capacitor_SMD:C_0402_1005Metric | ~
 |  |  |  |  |  |  |  | C15 | 10u | Device:C | Capacitor_SMD:C_0805_2012Metric | ~
 |  |  |  |  |  |  |  | C16 | 10u | Device:C | Capacitor_SMD:C_0805_2012Metric | ~
 |  |  |  |  |  |  |  | C17 | 100n | Device:C | Capacitor_SMD:C_0402_1005Metric | ~
 |  |  |  |  |  |  |  | C18 | 100n | Device:C | Capacitor_SMD:C_0402_1005Metric | ~
 |  |  |  |  |  |  |  | C19 | 22n | Device:C | Capacitor_SMD:C_0402_1005Metric | ~
 |  |  |  |  |  |  |  | C20 | 100n | Device:C | Capacitor_SMD:C_0402_1005Metric | ~
 |  |  |  |  |  |  |  | C21 | 10u | Device:C | Capacitor_SMD:C_0805_2012Metric | ~
 |  |  |  |  |  |  |  | C22 | 100n | Device:C | Capacitor_SMD:C_0402_1005Metric | ~
 |  |  |  |  |  |  |  | C23 | 100n | Device:C | Capacitor_SMD:C_0402_1005Metric | ~
 |  |  |  |  |  |  |  | C24 | 10u | Device:C | Capacitor_SMD:C_0805_2012Metric | ~
 |  |  |  |  |  |  |  | C25 | 10u | Device:C | Capacitor_SMD:C_0805_2012Metric | ~
 |  |  |  |  |  |  |  | C26 | 100n | Device:C | Capacitor_SMD:C_0402_1005Metric | ~
 |  |  |  |  |  |  |  | C27 | 100n | Device:C | Capacitor_SMD:C_0402_1005Metric | ~
 |  |  |  |  |  |  |  | C28 | 22n | Device:C | Capacitor_SMD:C_0402_1005Metric | ~
 |  |  |  |  |  |  |  | C29 | 100n | Device:C | Capacitor_SMD:C_0402_1005Metric | ~
 |  |  |  |  |  |  |  | C30 | 10u | Device:C | Capacitor_SMD:C_0805_2012Metric | ~
 |  |  |  |  |  |  |  | C31 | 100n | Device:C | Capacitor_SMD:C_0402_1005Metric | ~
 |  |  |  |  |  |  |  | C32 | 100n | Device:C | Capacitor_SMD:C_0402_1005Metric | ~
 |  |  |  |  |  |  |  | C33 | 10u | Device:C | Capacitor_SMD:C_0805_2012Metric | ~
 |  |  |  |  |  |  |  | C34 | 10u | Device:C | Capacitor_SMD:C_0805_2012Metric | ~
 |  |  |  |  |  |  |  | C35 | 100n | Device:C | Capacitor_SMD:C_0402_1005Metric | ~
 |  |  |  |  |  |  |  | C36 | 100n | Device:C | Capacitor_SMD:C_0402_1005Metric | ~
 |  |  |  |  |  |  |  | C37 | 22n | Device:C | Capacitor_SMD:C_0402_1005Metric | ~
 |  |  |  |  |  |  |  | C38 | 100n | Device:C | Capacitor_SMD:C_0402_1005Metric | ~
 |  |  |  |  |  |  |  | C39 | 10u | Device:C | Capacitor_SMD:C_0805_2012Metric | ~
 |  |  |  |  |  |  |  | C40 | 100n | Device:C | Capacitor_SMD:C_0402_1005Metric | ~
 |  |  |  |  |  |  |  | C41 | 100n | Device:C | Capacitor_SMD:C_0402_1005Metric | ~
 |  |  |  |  |  |  |  | C42 | 10u | Device:C | Capacitor_SMD:C_0805_2012Metric | ~
 |  |  |  |  |  |  |  | C43 | 10u | Device:C | Capacitor_SMD:C_0805_2012Metric | ~
 |  |  |  |  |  |  |  | C44 | 100n | Device:C | Capacitor_SMD:C_0402_1005Metric | ~
 |  |  |  |  |  |  |  | C45 | 100n | Device:C | Capacitor_SMD:C_0402_1005Metric | ~
 |  |  |  |  |  |  |  | C46 | 22n | Device:C | Capacitor_SMD:C_0402_1005Metric | ~
 |  |  |  |  |  |  |  | C47 | 100n | Device:C | Capacitor_SMD:C_0402_1005Metric | ~
 |  |  |  |  |  |  |  | C48 | 10u | Device:C | Capacitor_SMD:C_0805_2012Metric | ~
 |  |  |  |  |  |  |  | C49 | 100n | Device:C | Capacitor_SMD:C_0402_1005Metric | ~
 |  |  |  |  |  |  |  | C50 | 100n | Device:C | Capacitor_SMD:C_0402_1005Metric | ~
 |  |  |  |  |  |  |  | C51 | 10u | Device:C | Capacitor_SMD:C_0805_2012Metric | ~
 |  |  |  |  |  |  |  | C52 | 10u | Device:C | Capacitor_SMD:C_0805_2012Metric | ~
 |  |  |  |  |  |  |  | C53 | 10u | Device:C | Capacitor_SMD:C_0805_2012Metric | ~
 |  |  |  |  |  |  |  | C54 | 1n | Device:C | Capacitor_SMD:C_0402_1005Metric | ~
 |  |  |  |  |  |  |  | C55 | 10u | Device:C | Capacitor_SMD:C_0805_2012Metric | ~
 |  |  |  |  |  |  |  | C56 | 1n | Device:C | Capacitor_SMD:C_0402_1005Metric | ~
 |  |  |  |  |  |  |  | C57 | 100n | Device:C | Capacitor_SMD:C_0402_1005Metric | ~
 |  |  |  |  |  |  |  | C58 | 100n | Device:C | Capacitor_SMD:C_0402_1005Metric | ~
 |  |  |  |  |  |  |  | C59 | 100u | Device:CP | Capacitor_THT:CP_Radial_D8.0mm_P3.50mm | ~
 |  |  |  |  |  |  |  | C60 | 100u | Device:CP | Capacitor_THT:CP_Radial_D8.0mm_P3.50mm | ~
 |  |  |  |  |  |  |  | C61 | 100n | Device:C | Capacitor_SMD:C_0402_1005Metric | ~
 |  |  |  |  |  |  |  | C62 | 100n | Device:C | Capacitor_SMD:C_0402_1005Metric | ~
 |  |  |  |  |  |  |  | C63 | 10u | Device:C | Capacitor_SMD:C_0805_2012Metric | ~
 |  |  |  |  |  |  |  | C64 | 10u | Device:C | Capacitor_SMD:C_0805_2012Metric | ~
 |  |  |  |  |  |  |  | C65 | 100u | Device:CP | Capacitor_THT:CP_Radial_D8.0mm_P3.50mm | ~
 |  |  |  |  |  |  |  | C66 | 10u | Device:C | Capacitor_SMD:C_0805_2012Metric | ~
 |  |  |  |  |  |  |  | C67 | 1n | Device:C | Capacitor_SMD:C_0402_1005Metric | ~
 |  |  |  |  |  |  |  | C68 | 10u | Device:C | Capacitor_SMD:C_0805_2012Metric | ~
 |  |  |  |  |  |  |  | C69 | 1n | Device:C | Capacitor_SMD:C_0402_1005Metric | ~
 |  |  |  |  |  |  |  | C70 | 10u | Device:C | Capacitor_SMD:C_0805_2012Metric | ~
 |  |  |  |  |  |  |  | C71 | 1n | Device:C | Capacitor_SMD:C_0402_1005Metric | ~
 |  |  |  |  |  |  |  | C72 | 10u | Device:C | Capacitor_SMD:C_0805_2012Metric | ~
 |  |  |  |  |  |  |  | C73 | 1n | Device:C | Capacitor_SMD:C_0402_1005Metric | ~
 |  |  |  |  |  |  |  | C74 | 1n | Device:C | Capacitor_SMD:C_0402_1005Metric | ~
 |  |  |  |  |  |  |  | C75 | 1n | Device:C | Capacitor_SMD:C_0402_1005Metric | ~
 |  |  |  |  |  |  |  | C76 | 10u | Device:C | Capacitor_SMD:C_0805_2012Metric | ~
 |  |  |  |  |  |  |  | C77 | 100n | Device:C | Capacitor_SMD:C_0402_1005Metric | ~
 |  |  |  |  |  |  |  | C78 | 10u | Device:C | Capacitor_SMD:C_0805_2012Metric | ~
 |  |  |  |  |  |  |  | C79 | 100u | Device:CP | Capacitor_THT:CP_Radial_D8.0mm_P3.50mm | ~
 |  |  |  |  |  |  |  | C80 | 100u | Device:CP | Capacitor_THT:CP_Radial_D8.0mm_P3.50mm | ~
 |  |  |  |  |  |  |  | C81 | 100u | Device:CP | Capacitor_THT:CP_Radial_D8.0mm_P3.50mm | ~
 |  |  |  |  |  |  |  | D1 | RED | Device:LED | LED_SMD:LED_0603_1608Metric | ~
 |  |  |  |  |  |  |  | D2 | RED | Device:LED | LED_SMD:LED_0603_1608Metric | ~
 |  |  |  |  |  |  |  | D3 | RED | Device:LED | LED_SMD:LED_0603_1608Metric | ~
 |  |  |  |  |  |  |  | D4 | RED | Device:LED | LED_SMD:LED_0603_1608Metric | ~
 |  |  |  |  |  |  |  | H1 | 4mm | Mechanical:MountingHole_Pad | MountingHole:MountingHole_3.2mm_M3_Pad_Via | ~
 |  |  |  |  |  |  |  | H2 | 4mm | Mechanical:MountingHole_Pad | MountingHole:MountingHole_3.2mm_M3_Pad_Via | ~
 |  |  |  |  |  |  |  | H3 | 4mm | Mechanical:MountingHole_Pad | MountingHole:MountingHole_3.2mm_M3_Pad_Via | ~
 |  |  |  |  |  |  |  | H4 | 4mm | Mechanical:MountingHole_Pad | MountingHole:MountingHole_3.2mm_M3_Pad_Via | ~
 |  |  |  |  |  |  |  | J1 | RJMG2310228A0ER | library:RJMG2310228A0ER | library:RJMG2310228A0ER | https://cdn.amphenol-icc.com/media/wysiwyg/files/documentation/datasheet/inputoutput/io_rjmag_stacked.pdf
 |  |  |  |  |  |  |  | J2 | Conn_01x22_MountingPin | Connector_Generic_MountingPin:Conn_01x22_MountingPin | library:SFV22R-1STBE1HLF | ~
 |  |  |  |  |  |  |  | J3 | Conn_01x22_MountingPin | Connector_Generic_MountingPin:Conn_01x22_MountingPin | library:SFV22R-1STBE1HLF | ~
 |  |  |  |  |  |  |  | J4 | Conn_02x20_Odd_Even | Connector_Generic:Conn_02x20_Odd_Even | Connector_IDC:IDC-Header_2x20_P2.54mm_Vertical | ~
 |  |  |  |  |  |  |  | J5 | Conn_01x04_Female | Connector:Conn_01x04_Female | Connector_Molex:Molex_Mini-Fit_Jr_5566-04A_2x02_P4.20mm_Vertical | ~
 |  |  |  |  |  |  |  | J6 | ATX24pin | Connector_Generic:Conn_02x12_Top_Bottom | Connector_Molex:Molex_Mini-Fit_Jr_5566-24A_2x12_P4.20mm_Vertical | ~
 |  |  |  |  |  |  |  | J7 | ATXP8 | Connector_Generic:Conn_02x04_Top_Bottom | Connector_Molex:Molex_Mini-Fit_Jr_5566-08A_2x04_P4.20mm_Vertical | ~
 |  |  |  |  |  |  |  | J8 | Conn_02x20_Odd_Even | Connector_Generic:Conn_02x20_Odd_Even | Connector_IDC:IDC-Header_2x20_P2.54mm_Vertical | ~
 |  |  |  |  |  |  |  | J9 | Conn_02x20_Odd_Even | Connector_Generic:Conn_02x20_Odd_Even | Connector_IDC:IDC-Header_2x20_P2.54mm_Vertical | ~
 |  |  |  |  |  |  |  | J10 | Conn_02x08_Odd_Even | Connector_Generic:Conn_02x08_Odd_Even | Connector_IDC:IDC-Header_2x08_P2.54mm_Vertical | ~
 |  |  |  |  |  |  |  | J11 | Conn_01x22_MountingPin | Connector_Generic_MountingPin:Conn_01x22_MountingPin | library:SFV22R-1STBE1HLF | ~
 |  |  |  |  |  |  |  | J12 | HDMI_A | Connector:HDMI_A | library:HDMI_RAHHD19TR | https://en.wikipedia.org/wiki/HDMI
 |  |  |  |  |  |  |  | J13 | USB_B_Micro | Connector:USB_B_Micro | Connector_USB:USB_Micro-B_Amphenol_10103594-0001LF_Horizontal | ~
 |  |  |  |  |  |  |  | J14 | Conn_02x01 | Connector_Generic:Conn_02x01 | Connector_Molex:Molex_Mini-Fit_Jr_5566-02A_2x01_P4.20mm_Vertical | ~
 |  |  |  |  |  |  |  | J15 | Fan connector | Connector:Conn_01x04_Male | Connector:FanPinHeader_1x04_P2.54mm_Vertical | ~
 |  |  |  |  |  |  |  | R1 | 1k8 | Device:R | Resistor_SMD:R_0402_1005Metric | ~
 |  |  |  |  |  |  |  | R2 | 1k8 | Device:R | Resistor_SMD:R_0402_1005Metric | ~
 |  |  |  |  |  |  |  | R3 | 1k8 | Device:R | Resistor_SMD:R_0402_1005Metric | ~
 |  |  |  |  |  |  |  | R4 | 30 | Device:R | Resistor_SMD:R_0402_1005Metric | ~
 |  |  |  |  |  |  |  | R5 | 10 | Device:R | Resistor_SMD:R_0402_1005Metric | ~
 |  |  |  |  |  |  |  | R6 | 1k8 | Device:R | Resistor_SMD:R_0402_1005Metric | ~
 |  |  |  |  |  |  |  | R7 | 10k | Device:R | Resistor_SMD:R_0402_1005Metric | ~
 |  |  |  |  |  |  |  | R8 | 150 | Device:R | Resistor_SMD:R_0402_1005Metric | ~
 |  |  |  |  |  |  |  | R9 | 150 | Device:R | Resistor_SMD:R_0402_1005Metric | ~
 |  |  |  |  |  |  |  | R10 | 150 | Device:R | Resistor_SMD:R_0402_1005Metric | ~
 |  |  |  |  |  |  |  | R11 | 150 | Device:R | Resistor_SMD:R_0402_1005Metric | ~
 |  |  |  |  |  |  |  | R12 | 150 | Device:R | Resistor_SMD:R_0402_1005Metric | ~
 |  |  |  |  |  |  |  | R13 | 150 | Device:R | Resistor_SMD:R_0402_1005Metric | ~
 |  |  |  |  |  |  |  | R14 | 1K8 | Device:R | Resistor_SMD:R_0402_1005Metric | ~
 |  |  |  |  |  |  |  | R15 | 1K8 | Device:R | Resistor_SMD:R_0402_1005Metric | ~
 |  |  |  |  |  |  |  | R16 | 1k8 | Device:R | Resistor_SMD:R_0402_1005Metric | ~
 |  |  |  |  |  |  |  | R17 | 1K8 | Device:R | Resistor_SMD:R_0402_1005Metric | ~
 |  |  |  |  |  |  |  | R18 | 150 | Device:R | Resistor_SMD:R_0402_1005Metric | ~
 |  |  |  |  |  |  |  | R19 | 150 | Device:R | Resistor_SMD:R_0402_1005Metric | ~
 |  |  |  |  |  |  |  | R20 | 150 | Device:R | Resistor_SMD:R_0402_1005Metric | ~
 |  |  |  |  |  |  |  | R21 | 150 | Device:R | Resistor_SMD:R_0402_1005Metric | ~
 |  |  |  |  |  |  |  | R22 | 150 | Device:R | Resistor_SMD:R_0402_1005Metric | ~
 |  |  |  |  |  |  |  | R23 | 150 | Device:R | Resistor_SMD:R_0402_1005Metric | ~
 |  |  |  |  |  |  |  | R24 | 150 | Device:R | Resistor_SMD:R_0402_1005Metric | ~
 |  |  |  |  |  |  |  | R25 | 150 | Device:R | Resistor_SMD:R_0402_1005Metric | ~
 |  |  |  |  |  |  |  | R26 | 39 | Device:R | Resistor_SMD:R_0402_1005Metric | ~
 |  |  |  |  |  |  |  | R27 | 39 | Device:R | Resistor_SMD:R_0402_1005Metric | ~
 |  |  |  |  |  |  |  | R28 | 1k8 | Device:R | Resistor_SMD:R_0402_1005Metric | ~
 |  |  |  |  |  |  |  | R29 | 39 | Device:R | Resistor_SMD:R_0402_1005Metric | ~
 |  |  |  |  |  |  |  | R30 | 150 | Device:R | Resistor_SMD:R_0402_1005Metric | ~
 |  |  |  |  |  |  |  | R31 | 150 | Device:R | Resistor_SMD:R_0402_1005Metric | ~
 |  |  |  |  |  |  |  | R32 | 150 | Device:R | Resistor_SMD:R_0402_1005Metric | ~
 |  |  |  |  |  |  |  | R33 | 150 | Device:R | Resistor_SMD:R_0402_1005Metric | ~
 |  |  |  |  |  |  |  | R34 | 150 | Device:R | Resistor_SMD:R_0402_1005Metric | ~
 |  |  |  |  |  |  |  | R35 | 150 | Device:R | Resistor_SMD:R_0402_1005Metric | ~
 |  |  |  |  |  |  |  | R36 | 10k | Device:R | Resistor_SMD:R_0402_1005Metric | ~
 |  |  |  |  |  |  |  | R37 | 150 | Device:R | Resistor_SMD:R_0402_1005Metric | ~
 |  |  |  |  |  |  |  | R38 | 1k8 | Device:R | Resistor_SMD:R_0402_1005Metric | ~
 |  |  |  |  |  |  |  | R39 | 1k8 | Device:R | Resistor_SMD:R_0402_1005Metric | ~
 |  |  |  |  |  |  |  | R40 | 1K8 | Device:R | Resistor_SMD:R_0402_1005Metric | ~
 |  |  |  |  |  |  |  | R41 | 1k8 | Device:R | Resistor_SMD:R_0402_1005Metric | ~
 |  |  |  |  |  |  |  | R42 | 39 | Device:R | Resistor_SMD:R_0402_1005Metric | ~
 |  |  |  |  |  |  |  | R43 | 10 | Device:R | Resistor_SMD:R_0402_1005Metric | ~
 |  |  |  |  |  |  |  | R44 | 0R15 | Device:R | Resistor_SMD:R_1206_3216Metric | ~
 |  |  |  |  |  |  |  | R45 | 1k8 | Device:R | Resistor_SMD:R_0402_1005Metric | ~
 |  |  |  |  |  |  |  | R46 | 10k | Device:R | Resistor_SMD:R_0402_1005Metric | ~
 |  |  |  |  |  |  |  | R47 | 10k | Device:R | Resistor_SMD:R_0402_1005Metric | ~
 |  |  |  |  |  |  |  | R48 | 150 | Device:R | Resistor_SMD:R_0402_1005Metric | ~
 |  |  |  |  |  |  |  | R49 | 150 | Device:R | Resistor_SMD:R_0402_1005Metric | ~
 |  |  |  |  |  |  |  | R50 | 0R15 | Device:R | Resistor_SMD:R_1206_3216Metric | ~
 |  |  |  |  |  |  |  | R51 | 10 | Device:R | Resistor_SMD:R_0402_1005Metric | ~
 |  |  |  |  |  |  |  | R52 | 0R15 | Device:R | Resistor_SMD:R_1206_3216Metric | ~
 |  |  |  |  |  |  |  | R54 | 10k | Device:R | Resistor_SMD:R_0402_1005Metric | ~
 |  |  |  |  |  |  |  | R55 | 10k | Device:R | Resistor_SMD:R_0402_1005Metric | ~
 |  |  |  |  |  |  |  | R56 | 10k | Device:R | Resistor_SMD:R_0402_1005Metric | ~
 |  |  |  |  |  |  |  | R57 | 10k | Device:R | Resistor_SMD:R_0402_1005Metric | ~
 |  |  |  |  |  |  |  | R58 | 0R15 | Device:R | Resistor_SMD:R_1206_3216Metric | ~
 |  |  |  |  |  |  |  | R59 | 10 | Device:R | Resistor_SMD:R_0402_1005Metric | ~
 |  |  |  |  |  |  |  | R60 | 0R15 | Device:R | Resistor_SMD:R_1206_3216Metric | ~
 |  |  |  |  |  |  |  | R62 | 10k | Device:R | Resistor_SMD:R_0402_1005Metric | ~
 |  |  |  |  |  |  |  | R63 | 10k | Device:R | Resistor_SMD:R_0402_1005Metric | ~
 |  |  |  |  |  |  |  | R66 | 0R15 | Device:R | Resistor_SMD:R_1206_3216Metric | ~
 |  |  |  |  |  |  |  | R67 | 10 | Device:R | Resistor_SMD:R_0402_1005Metric | ~
 |  |  |  |  |  |  |  | R68 | 0R15 | Device:R | Resistor_SMD:R_1206_3216Metric | ~
 |  |  |  |  |  |  |  | R70 | 10k | Device:R | Resistor_SMD:R_0402_1005Metric | ~
 |  |  |  |  |  |  |  | R71 | 10k | Device:R | Resistor_SMD:R_0402_1005Metric | ~
 |  |  |  |  |  |  |  | R72 | 10k | Device:R | Resistor_SMD:R_0402_1005Metric | ~
 |  |  |  |  |  |  |  | R73 | 10k | Device:R | Resistor_SMD:R_0402_1005Metric | ~
 |  |  |  |  |  |  |  | R74 | 0R15 | Device:R | Resistor_SMD:R_1206_3216Metric | ~
 |  |  |  |  |  |  |  | R75 | 10 | Device:R | Resistor_SMD:R_0402_1005Metric | ~
 |  |  |  |  |  |  |  | R76 | 0R15 | Device:R | Resistor_SMD:R_1206_3216Metric | ~
 |  |  |  |  |  |  |  | R78 | 10k | Device:R | Resistor_SMD:R_0402_1005Metric | ~
 |  |  |  |  |  |  |  | R79 | 10k | Device:R | Resistor_SMD:R_0402_1005Metric | ~
 |  |  |  |  |  |  |  | R82 | 0R15 | Device:R | Resistor_SMD:R_1206_3216Metric | ~
 |  |  |  |  |  |  |  | R83 | 10k | Device:R | Resistor_SMD:R_0402_1005Metric | ~
 |  |  |  |  |  |  |  | R84 | 10k | Device:R | Resistor_SMD:R_0402_1005Metric | ~
 |  |  |  |  |  |  |  | R85 | 10k | Device:R | Resistor_SMD:R_0402_1005Metric | ~
 |  |  |  |  |  |  |  | R86 | 1k8 | Device:R | Resistor_SMD:R_0402_1005Metric | ~
 |  |  |  |  |  |  |  | R87 | 150 | Device:R | Resistor_SMD:R_0402_1005Metric | ~
 |  |  |  |  |  |  |  | R88 | 10k | Device:R | Resistor_SMD:R_0402_1005Metric | ~
 |  |  |  |  |  |  |  | R89 | 10k | Device:R | Resistor_SMD:R_0402_1005Metric | ~
 |  |  |  |  |  |  |  | R90 | 10k | Device:R | Resistor_SMD:R_0402_1005Metric | ~
 |  |  |  |  |  |  |  | R91 | 10k | Device:R | Resistor_SMD:R_0402_1005Metric | ~
 |  |  |  |  |  |  |  | R92 | 10k | Device:R | Resistor_SMD:R_0402_1005Metric | ~
 |  |  |  |  |  |  |  | R93 | 10k | Device:R | Resistor_SMD:R_0402_1005Metric | ~
 |  |  |  |  |  |  |  | R96 | 150 | Device:R | Resistor_SMD:R_0402_1005Metric | ~
 |  |  |  |  |  |  |  | R97 | 10k | Device:R | Resistor_SMD:R_0402_1005Metric | ~
 |  |  |  |  |  |  |  | R98 | 10k | Device:R | Resistor_SMD:R_0402_1005Metric | ~
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

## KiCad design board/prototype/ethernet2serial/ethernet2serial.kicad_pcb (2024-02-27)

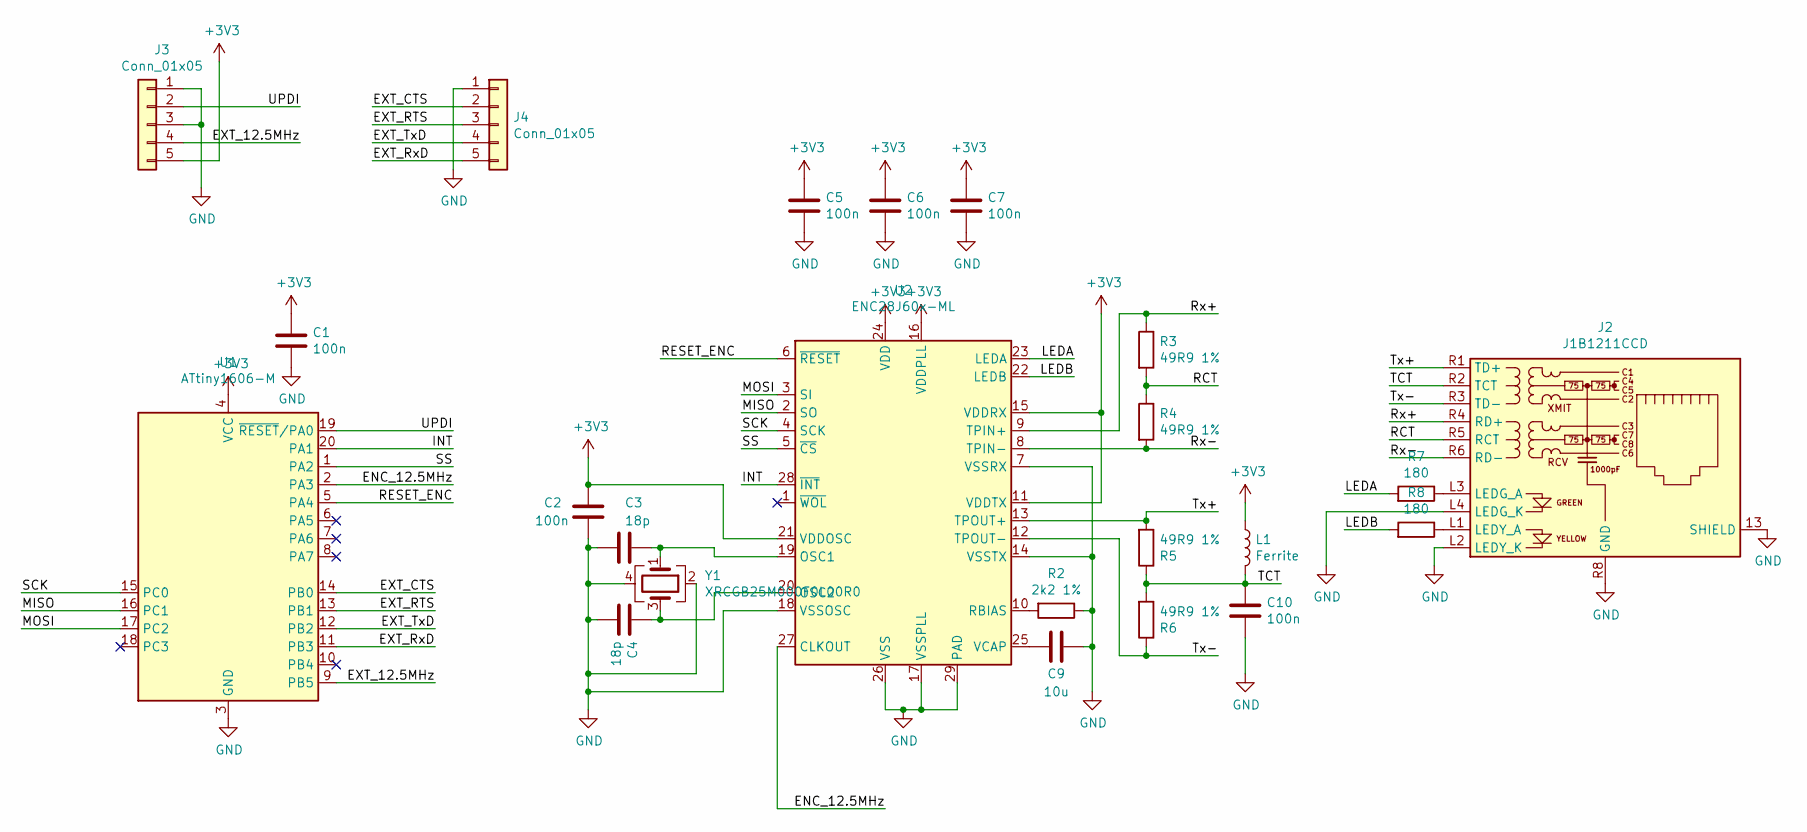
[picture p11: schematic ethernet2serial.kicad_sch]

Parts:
C1, C2, C5, C6, C7, C10: 100n; C_0402_1005Metric
C3, C4: 18p; C_0402_1005Metric
C9: 10u; C_0805_2012Metric
J2: J1B1211CCD; RJ45_Amphenol_RJMG1BD3B8K1ANR
J3, J4: Conn_01x05; PinHeader_1x05_P2.54mm_Vertical
L1: Ferrite; L_0402_1005Metric
R2: 2k2 1%; R_0402_1005Metric
R3, R4, R5, R6: 49R9 1%; R_0402_1005Metric
R7, R8: 180; R_0402_1005Metric
U1: ATtiny1606-M; VQFN-20-1EP_3x3mm_P0.4mm_EP1.7x1.7mm
U2: ENC28J60x-ML; QFN-28-1EP_6x6mm_P0.65mm_EP4.25x4.25mm
Y1: XRCGB25M000F0L00R0; Crystal_SMD_2016-4Pin_2.0x1.6mm

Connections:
+3V3: C1.1, C2.1, C5.1, C6.1, C7.1, J3.5, L1.1, U1.4 (VCC), U2.11 (VDDTX), U2.15 (VDDRX), U2.16 (VDDPLL), U2.21 (VDDOSC), U2.24 (VDD)
/ENC_12.5MHz: U1.2 (PA3), U2.27 (CLKOUT)
/EXT_12.5MHz: J3.4, U1.9 (PB5)
/EXT_CTS: J4.2, U1.14 (PB0)
/EXT_RTS: J4.3, U1.13 (PB1)
/EXT_RxD: J4.5, U1.11 (PB3)
/EXT_TxD: J4.4, U1.12 (PB2)
/INT: U1.20 (PA1), U2.28 (~INT)
/LEDA: R7.2, U2.23 (LEDA)
/LEDB: R8.2, U2.22 (LEDB)
/MISO: U1.16 (PC1), U2.2 (SO)
/MOSI: U1.17 (PC2), U2.3 (SI)
/RCT: J2.R5 (RCT), R3.2, R4.1
/RESET_ENC: U1.5 (PA4), U2.6 (~RESET)
/Rx+: J2.R4 (RD+), R3.1, U2.9 (TPIN+)
/Rx-: J2.R6 (RD-), R4.2, U2.8 (TPIN-)
/SCK: U1.15 (PC0), U2.4 (SCK)
/SS: U1.1 (PA2), U2.5 (~CS)
/TCT: C10.1, J2.R2 (TCT), L1.2, R5.1, R6.2
/Tx+: J2.R1 (TD+), R5.2, U2.13 (TPOUT+)
/Tx-: J2.R3 (TD-), R6.1, U2.12 (TPOUT-)
/UPDI: J3.2, U1.19 (~RESET/PA0)
GND: C1.2, C2.2, C3.1, C4.1, C5.2, C6.2, C7.2, C9.1, C10.2, J2.13 (SHIELD), J2.L2 (LEDY_K), J2.L4 (LEDG_K), J2.R8 (GND), J3.1, J3.3, J4.1, R2.1, U1.3 (GND), U1.21 (GND), U2.7 (VSSRX), U2.14 (VSSTX), U2.17 (VSSPLL), U2.18 (VSSOSC), U2.26 (VSS), U2.29 (PAD), Y1.2, Y1.4
unnamed: C3.2, U2.19 (OSC1), Y1.1
unnamed: C4.2, U2.20 (OSC2), Y1.3
unnamed: C9.2, U2.25 (VCAP)
unnamed: J2.L1 (LEDY_A), R8.1
unnamed: J2.L3 (LEDG_A), R7.1
unnamed: R2.2, U2.10 (RBIAS)

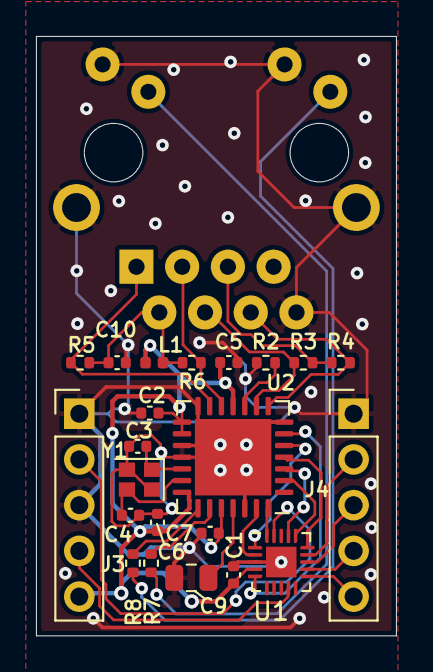
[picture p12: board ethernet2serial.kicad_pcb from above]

Board: 2 copper layers, 20.0 x 33.3 mm, 23 parts (1 on the bottom side), 29 nets.

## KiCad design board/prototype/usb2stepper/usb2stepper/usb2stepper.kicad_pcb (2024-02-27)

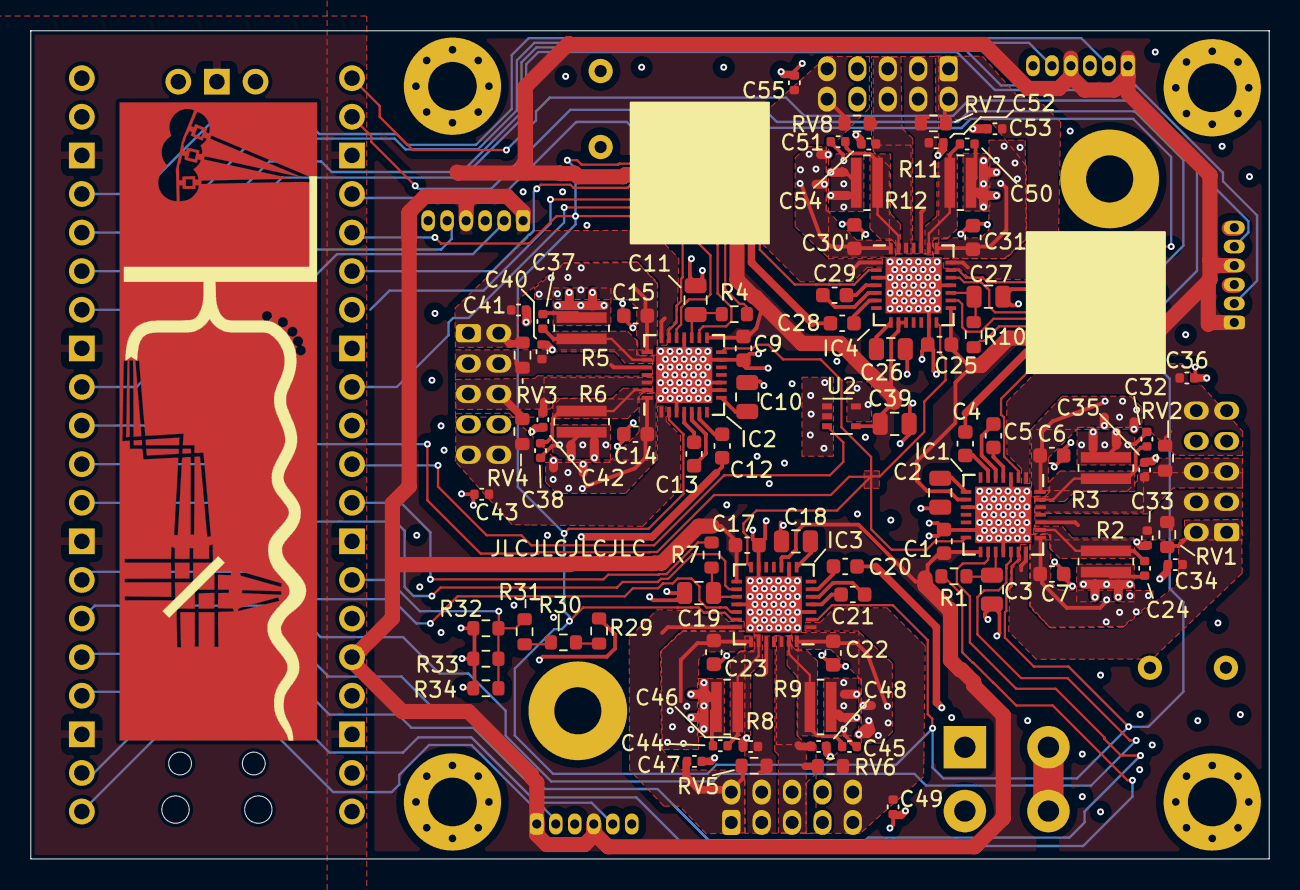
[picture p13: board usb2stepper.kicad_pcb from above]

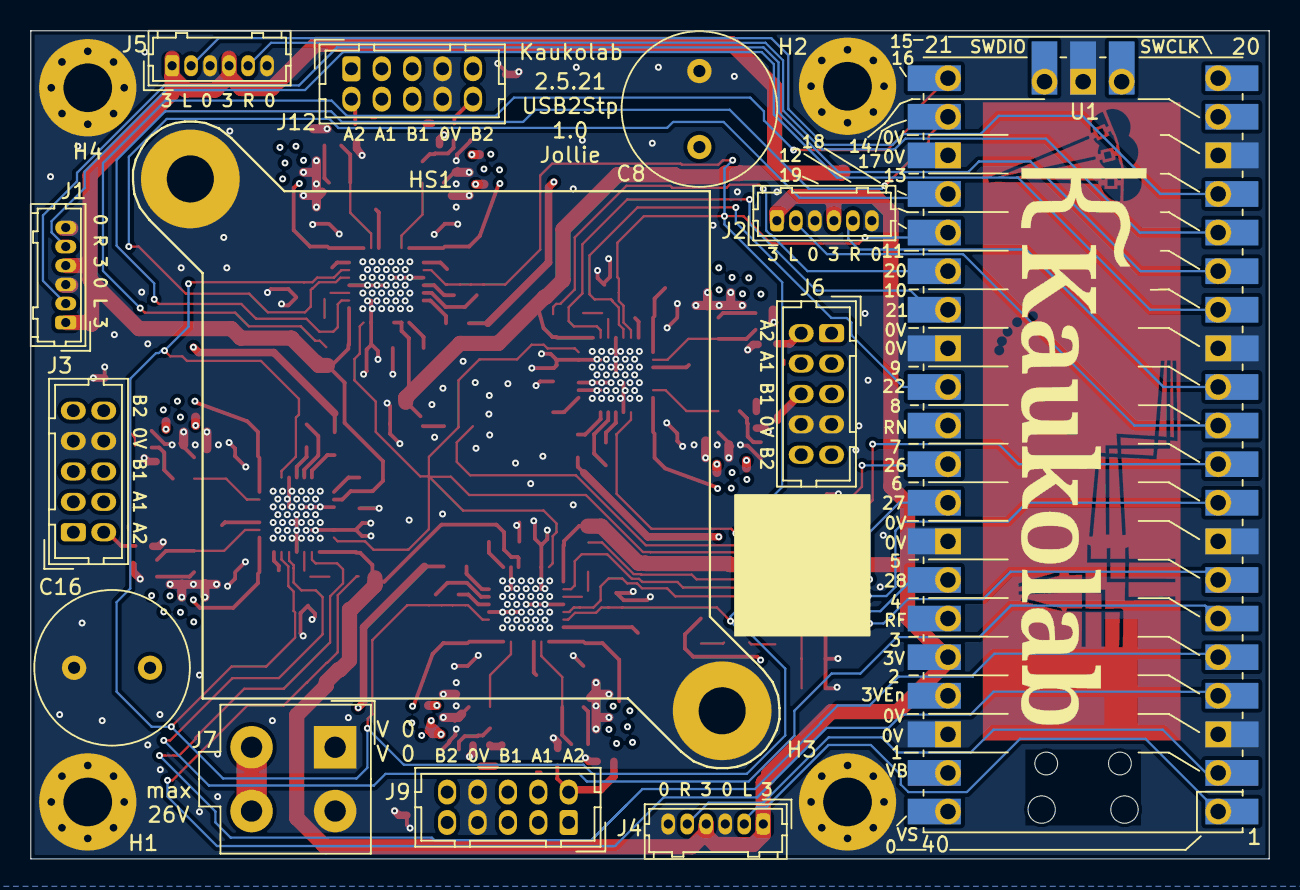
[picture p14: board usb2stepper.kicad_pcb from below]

Board: 4 copper layers, 81.5 x 54.5 mm, 103 parts (18 on the bottom side), 73 nets.

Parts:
C1, C4, C6, C7, C9, C12, C14, C15, C17, C20, C22, C23, C25, C28, C30, C31: 100n; C_0603_1608Metric
C2, C3, C10, C11, C18, C19, C26, C27, C39: 2u2 16V; C_0805_2012Metric
C5, C13, C21, C29: 22n; C_0603_1608Metric
C8, C16: 470uF; C_Radial_D10.0mm_H20.0mm_P5.00mm
C24, C32, C37, C38, C44, C45, C50, C51: 100nF NF; C_0402_1005Metric
C33, C34, C35, C36, C40, C41, C42, C43, C46, C47, C48, C49, C52, C53, C54, C55: 470pF 100V NF; C_0402_1005Metric
H1, H2, H3, H4: 3mm; MountingHole_3.2mm_M3_Pad_Via
HS1: 30x30mm; PCB_Heatsink_30x30mm_2xFixation3mm
IC1, IC2, IC3, IC4: TMC2209-LA; QFN-28-1EP_5x5mm_Pitch0.5mm_EP3.7x3.7
J1, J2, J4, J5: Conn_01x06; Hirose_DF13-06P-1.25DSA_1x06_P1.25mm_Vertical
J3, J6, J9, J12: Conn_02x05_Odd_Even; Hirose_DF11-10DP-2DSA_2x05_P2.00mm_Vertical
J7: Minifit_jr_2x2; Molex_MiniFit-JR-5556-04A_2x02x4.20mm_Straight
Logo1: Logo; Logo Silkscreen 40x9
Logo2: Logo; Logo All Layers 42x13
R1, R4, R7, R10, R29, R30, R31, R32, R33, R34: 10k; R_0603_1608Metric
R2, R3, R5, R6, R8, R9, R11, R12: 0.1; R_1206_Wide
RV1, RV2, RV3, RV4, RV5, RV6, RV7, RV8: Varistor; R_0603_1608Metric
U1: Pico; RPi_Pico_SMD_TH
U2: MCP9700AT-ELT; SOT-353_SC-70-5

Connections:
+3V3: C1.1, C9.1, C17.1, C25.1, C39.1, IC1.9 (MS1), IC1.15 (VCC_IO), IC2.15 (VCC_IO), IC3.10 (MS2), IC3.15 (VCC_IO), IC4.9 (MS1), IC4.10 (MS2), IC4.15 (VCC_IO), J1.1, J1.4, J2.1, J2.4, J4.1, J4.4, J5.1, J5.4, U1.36 (3V3), U2.4 (Vdd)
/24V_measure: R31.1, R32.2, R33.2, R34.2, U1.34 (GPIO28_ADC2)
/DIR0: IC1.19 (DIR), U1.6 (GPIO4)
/DIR1: IC2.19 (DIR), U1.29 (GPIO22)
/DIR2: IC3.19 (DIR), U1.7 (GPIO5)
/DIR3: IC4.19 (DIR), U1.24 (GPIO18)
/DISABLE_MOT: IC1.2 (ENN), IC1.20 (STDBY), IC2.2 (ENN), IC2.20 (STDBY), IC3.2 (ENN), IC3.20 (STDBY), IC4.2 (ENN), IC4.20 (STDBY), U1.25 (GPIO19)
/REFL0: J1.2, U1.15 (GPIO11)
/REFL1: J2.2, U1.11 (GPIO8)
/REFL2: J4.2, U1.1 (GPIO0)
/REFL3: J5.2, U1.17 (GPIO13)
/REFR0: J1.5, U1.14 (GPIO10)
/REFR1: J2.5, U1.12 (GPIO9)
/REFR2: J4.5, U1.2 (GPIO1)
/REFR3: J5.5, U1.16 (GPIO12)
/STEP0: IC1.16 (STEP), U1.5 (GPIO3)
/STEP1: IC2.16 (STEP), U1.27 (GPIO21)
/STEP2: IC3.16 (STEP), U1.9 (GPIO6)
/STEP3: IC4.16 (STEP), U1.22 (GPIO17)
/Sheet608F6F9E/BRA: C24.1, IC1.23 (BRA), R2.2
/Sheet608F6F9E/BRB: C32.1, IC1.27 (BRB), R3.2
/Sheet608F6F9E/OA1: C33.1, IC1.24 (OA1), J3.3, J3.4, RV1.1
/Sheet608F6F9E/OA2: C34.1, IC1.21 (OA2), J3.1, J3.2, RV1.2
/Sheet608F6F9E/OB1: C35.1, IC1.26 (OB1), J3.5, J3.6, RV2.1
/Sheet608F6F9E/OB2: C36.1, IC1.1 (OB2), J3.9, J3.10, RV2.2
/Sheet608F6F9E/Vref: C3.1, IC1.17 (VREF), R1.1
/TEMP: U1.31 (GPIO26_ADC0), U2.3 (Vout)
/UART: IC1.14 (PDN_UART), IC2.14 (PDN_UART), IC3.14 (PDN_UART), IC4.14 (PDN_UART), U1.10 (GPIO7)
/VREF_PWM0: R1.2, U1.4 (GPIO2)
/VREF_PWM1: R4.2, U1.26 (GPIO20)
/VREF_PWM2: R7.2, U1.32 (GPIO27_ADC1)
/VREF_PWM3: R10.2, U1.21 (GPIO16)
/sheet6092AD70/BRA: C50.1, IC4.23 (BRA), R11.2
/sheet6092AD70/BRB: C51.1, IC4.27 (BRB), R12.2
/sheet6092AD70/OA1: C52.1, IC4.24 (OA1), J12.3, J12.4, RV7.1
/sheet6092AD70/OA2: C53.1, IC4.21 (OA2), J12.1, J12.2, RV7.2
/sheet6092AD70/OB1: C54.1, IC4.26 (OB1), J12.5, J12.6, RV8.1
/sheet6092AD70/OB2: C55.1, IC4.1 (OB2), J12.9, J12.10, RV8.2
/sheet6092AD70/Vref: C27.1, IC4.17 (VREF), R10.1
/sheet609275BA/BRA: C37.1, IC2.23 (BRA), R5.2
/sheet609275BA/BRB: C38.1, IC2.27 (BRB), R6.2
/sheet609275BA/OA1: C40.1, IC2.24 (OA1), J6.3, J6.4, RV3.1
/sheet609275BA/OA2: C41.1, IC2.21 (OA2), J6.1, J6.2, RV3.2
/sheet609275BA/OB1: C42.1, IC2.26 (OB1), J6.5, J6.6, RV4.1
/sheet609275BA/OB2: C43.1, IC2.1 (OB2), J6.9, J6.10, RV4.2
/sheet609275BA/Vref: C11.1, IC2.17 (VREF), R4.1
/sheet60929021/BRA: C44.1, IC3.23 (BRA), R8.2
/sheet60929021/BRB: C45.1, IC3.27 (BRB), R9.2
/sheet60929021/OA1: C46.1, IC3.24 (OA1), J9.3, J9.4, RV5.1
/sheet60929021/OA2: C47.1, IC3.21 (OA2), J9.1, J9.2, RV5.2
/sheet60929021/OB1: C48.1, IC3.26 (OB1), J9.5, J9.6, RV6.1
/sheet60929021/OB2: C49.1, IC3.1 (OB2), J9.9, J9.10, RV6.2
/sheet60929021/Vref: C19.1, IC3.17 (VREF), R7.1
GND: C1.2, C2.2, C3.2, C6.2, C7.2, C8.2, C9.2, C10.2, C11.2, C14.2, C15.2, C16.2, C17.2, C18.2, C19.2, C22.2, C23.2, C24.2, C25.2, C26.2, C27.2, C30.2, C31.2, C32.2, C33.2, C34.2, C35.2, C36.2, C37.2, C38.2, C39.2, C40.2, C41.2, C42.2, C43.2, C44.2, C45.2, C46.2, C47.2, C48.2, C49.2, C50.2, C51.2, C52.2, C53.2, C54.2, C55.2, H1.1, H2.1, H3.1, H4.1, HS1.2, HS1.3, IC1.3 (GND), IC1.10 (MS2), IC1.13 (CLK), IC1.18 (GND), IC1.29 (GND), IC2.3 (GND), IC2.9 (MS1), IC2.10 (MS2), IC2.13 (CLK), IC2.18 (GND), IC2.29 (GND), IC3.3 (GND), IC3.9 (MS1), IC3.13 (CLK), IC3.18 (GND), IC3.29 (GND), IC4.3 (GND), IC4.13 (CLK), IC4.18 (GND), IC4.29 (GND), J1.3, J1.6, J2.3, J2.6, J3.7, J3.8, J4.3, J4.6, J5.3, J5.6, J6.7, J6.8, J7.1, J7.2, J9.7, J9.8, J12.7, J12.8, R2.1, R3.1, R5.1, R6.1, R8.1, R9.1, R11.1, R12.1, R32.1, R33.1, R34.1, U1.3 (GND), U1.8 (GND), U1.13 (GND), U1.18 (GND), U1.23 (GND), U1.28 (GND), U1.33 (AGND), U1.38 (GND), U1.42 (GND), U2.1 (NC), U2.2 (GND), U2.5 (NC)
unnamed: C2.1, IC1.8 (5VOUT)
unnamed: C4.2, IC1.6 (VCP)
unnamed: C5.1, IC1.5 (CPI)
unnamed: C5.2, IC1.4 (CPO)
unnamed: C10.1, IC2.8 (5VOUT)
unnamed: C12.2, IC2.6 (VCP)
unnamed: C13.1, IC2.5 (CPI)
unnamed: C13.2, IC2.4 (CPO)
unnamed: C18.1, IC3.8 (5VOUT)
unnamed: C20.2, IC3.6 (VCP)
unnamed: C21.1, IC3.5 (CPI)
unnamed: C21.2, IC3.4 (CPO)
unnamed: C26.1, IC4.8 (5VOUT)
unnamed: C28.2, IC4.6 (VCP)
unnamed: C29.1, IC4.5 (CPI)
unnamed: C29.2, IC4.4 (CPO)
unnamed: R29.1, R30.2
unnamed: R30.1, R31.2
Vdrive: C4.1, C6.1, C7.1, C8.1, C12.1, C14.1, C15.1, C16.1, C20.1, C22.1, C23.1, C28.1, C30.1, C31.1, IC1.22 (VS), IC1.28 (VS), IC2.22 (VS), IC2.28 (VS), IC3.22 (VS), IC3.28 (VS), IC4.22 (VS), IC4.28 (VS), J7.3, J7.4, R29.2

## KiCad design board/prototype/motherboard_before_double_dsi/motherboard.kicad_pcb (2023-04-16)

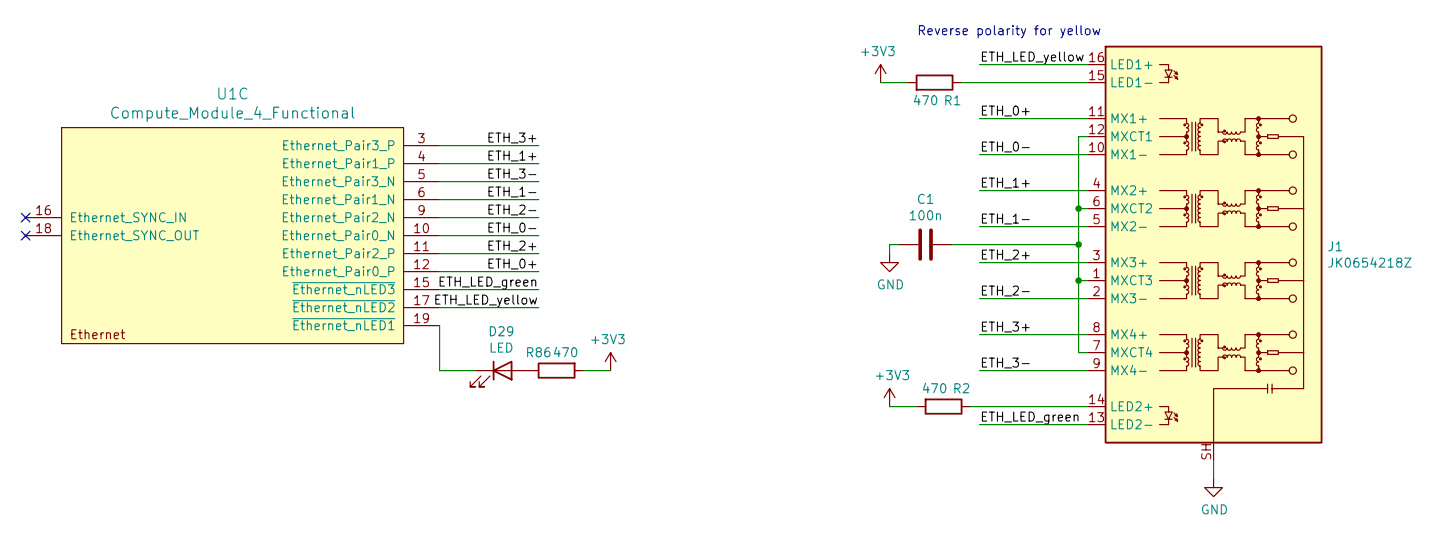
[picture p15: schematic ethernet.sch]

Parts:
C1: 100n; C_0402_1005Metric
D29: LED; LED_0603_1608Metric
J1: JK0654218Z; RJ45_Pulse_JK0654219NL_Horizontal
R1, R2, R86: 470; R_0402_1005Metric
U1: Compute_Module_4_Functional; Raspberry-Pi-4-Compute-Module

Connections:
/ethernet/ETH_0+: J1.11 (MX1+), U1.12 (Ethernet_Pair0_P)
/ethernet/ETH_0-: J1.10 (MX1-), U1.10 (Ethernet_Pair0_N)
/ethernet/ETH_1+: J1.4 (MX2+), U1.4 (Ethernet_Pair1_P)
/ethernet/ETH_1-: J1.5 (MX2-), U1.6 (Ethernet_Pair1_N)
/ethernet/ETH_2+: J1.3 (MX3+), U1.11 (Ethernet_Pair2_P)
/ethernet/ETH_2-: J1.2 (MX3-), U1.9 (Ethernet_Pair2_N)
/ethernet/ETH_3+: J1.8 (MX4+), U1.3 (Ethernet_Pair3_P)
/ethernet/ETH_3-: J1.9 (MX4-), U1.5 (Ethernet_Pair3_N)
/ethernet/ETH_LED_green: J1.13 (LED2-), U1.15 (~Ethernet_nLED3)
/ethernet/ETH_LED_yellow: J1.16 (LED1+), U1.17 (~Ethernet_nLED2)
unnamed: C1.1, J1.1 (MXCT3), J1.6 (MXCT2), J1.7 (MXCT4), J1.12 (MXCT1)
unnamed: D29.1 (K), U1.19 (~Ethernet_nLED1)
unnamed: D29.2 (A), R86.1
unnamed: J1.14 (LED2+), R2.1
unnamed: J1.15 (LED1-), R1.1

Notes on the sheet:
Reverse polarity for yellow

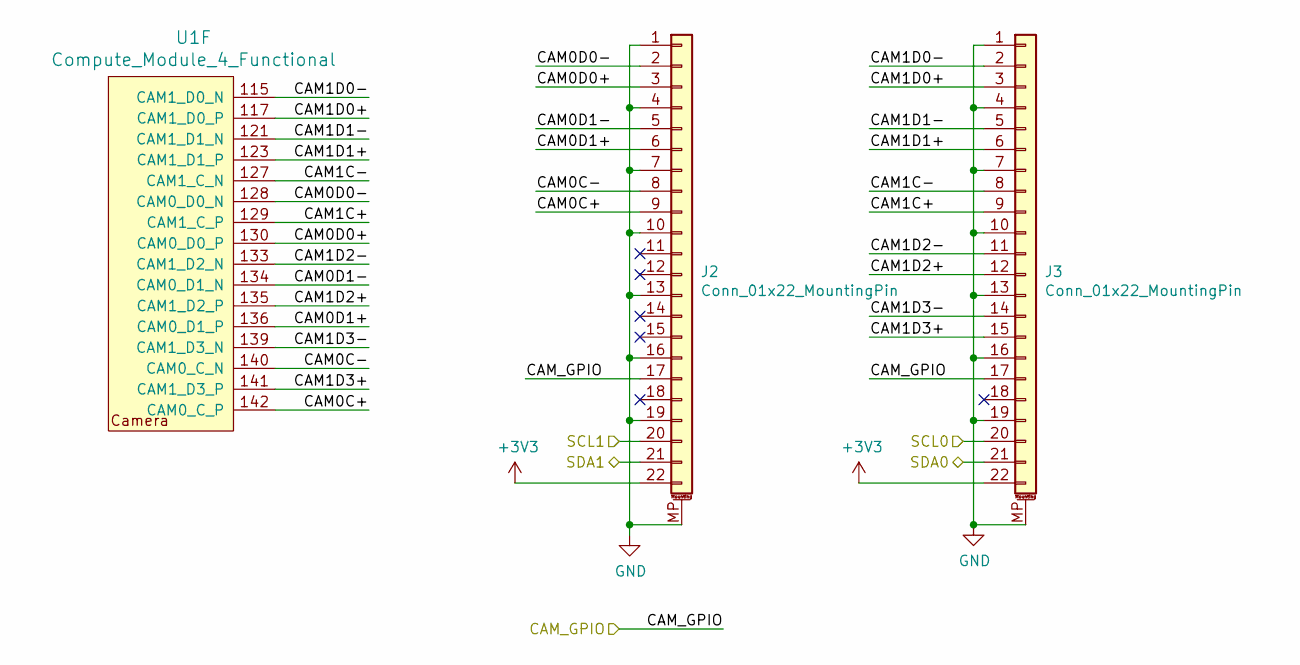
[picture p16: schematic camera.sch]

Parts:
J2, J3: Conn_01x22_MountingPin; 5019512230_1x22-1MP_P0.5mm_Vertical
U1: Compute_Module_4_Functional; Raspberry-Pi-4-Compute-Module

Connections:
/CAM_GPIO: J2.17, J3.17; also elsewhere on the board
/SCL0: J3.20; also elsewhere on the board
/SCL1: J2.20; also elsewhere on the board
/SDA0: J3.21; also elsewhere on the board
/SDA1: J2.21; also elsewhere on the board
/camera/CAM0C+: J2.9, U1.142 (CAM0_C_P)
/camera/CAM0C-: J2.8, U1.140 (CAM0_C_N)
/camera/CAM0D0+: J2.3, U1.130 (CAM0_D0_P)
/camera/CAM0D0-: J2.2, U1.128 (CAM0_D0_N)
/camera/CAM0D1+: J2.6, U1.136 (CAM0_D1_P)
/camera/CAM0D1-: J2.5, U1.134 (CAM0_D1_N)
/camera/CAM1C+: J3.9, U1.129 (CAM1_C_P)
/camera/CAM1C-: J3.8, U1.127 (CAM1_C_N)
/camera/CAM1D0+: J3.3, U1.117 (CAM1_D0_P)
/camera/CAM1D0-: J3.2, U1.115 (CAM1_D0_N)
/camera/CAM1D1+: J3.6, U1.123 (CAM1_D1_P)
/camera/CAM1D1-: J3.5, U1.121 (CAM1_D1_N)
/camera/CAM1D2+: J3.12, U1.135 (CAM1_D2_P)
/camera/CAM1D2-: J3.11, U1.133 (CAM1_D2_N)
/camera/CAM1D3+: J3.15, U1.141 (CAM1_D3_P)
/camera/CAM1D3-: J3.14, U1.139 (CAM1_D3_N)

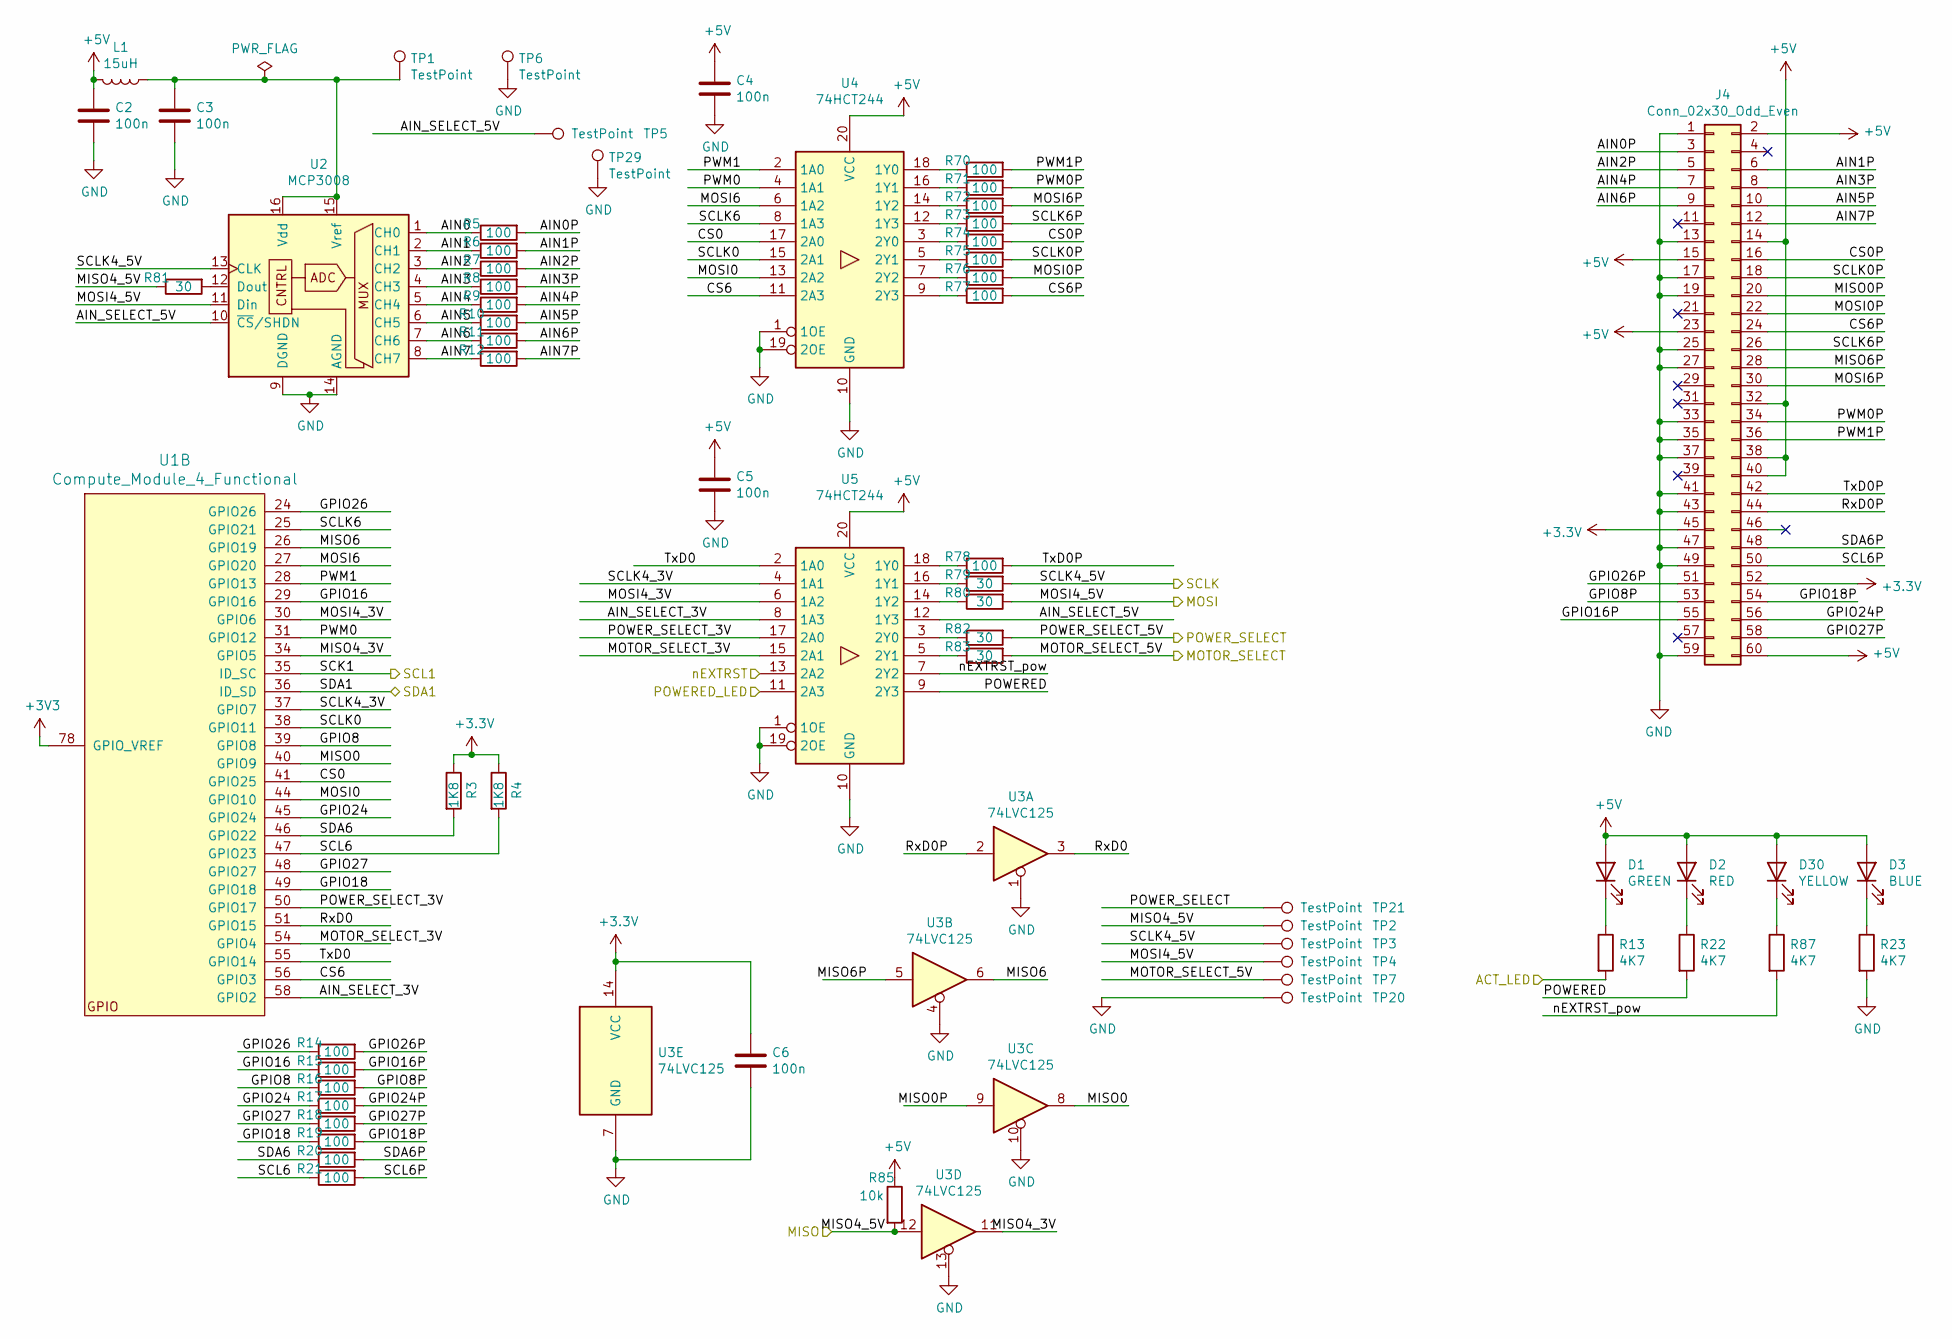
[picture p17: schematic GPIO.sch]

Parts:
C2, C3, C4, C5, C6: 100n; C_0402_1005Metric
D1: GREEN; LED_0603_1608Metric
D2: RED; LED_0603_1608Metric
D3: BLUE; LED_0603_1608Metric
D30: YELLOW; LED_0603_1608Metric
J4: Conn_02x30_Odd_Even; PinHeader_2x30_P2.54mm_Vertical
L1: 15uH; L_0603_1608Metric
R3, R4: 1K8; R_0402_1005Metric
R5, R6, R7, R8, R9, R10, R11, R12, R14, R15, R16, R17, R18, R19, R20, R21, R70, R71, R72, R73, R74, R75, R76, R77, R78: 100; R_0402_1005Metric
R13, R22, R23, R87: 4K7; R_0402_1005Metric
R79, R80, R81, R82, R83: 30; R_0402_1005Metric
R85: 10k; R_0402_1005Metric
TP1, TP2, TP3, TP4, TP5, TP6, TP7, TP20, TP21, TP29: TestPoint; TestPoint_Pad_1.5x1.5mm
U1: Compute_Module_4_Functional; Raspberry-Pi-4-Compute-Module
U2: MCP3008; SOIC-16_3.9x9.9mm_P1.27mm
U3: 74LVC125; TSSOP-14_4.4x5mm_P0.65mm
U4, U5: 74HCT244; TSSOP-20_4.4x6.5mm_P0.65mm

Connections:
+5V: C2.1, C4.1, C5.1, D1.2 (A), D2.2 (A), D3.2 (A), D30.2 (A), J4.2, J4.14, J4.15, J4.23, J4.32, J4.38, J4.40, J4.60, L1.2, R85.1, U4.20 (VCC), U5.20 (VCC); also elsewhere on the board
/GPIO/ACT_LED: R13.2; also elsewhere on the board
/GPIO/AIN0: R5.1, U2.1 (CH0)
/GPIO/AIN0P: J4.3, R5.2
/GPIO/AIN1: R6.1, U2.2 (CH1)
/GPIO/AIN1P: J4.6, R6.2
/GPIO/AIN2: R7.1, U2.3 (CH2)
/GPIO/AIN2P: J4.5, R7.2
/GPIO/AIN3: R8.1, U2.4 (CH3)
/GPIO/AIN3P: J4.8, R8.2
/GPIO/AIN4: R9.1, U2.5 (CH4)
/GPIO/AIN4P: J4.7, R9.2
/GPIO/AIN5: R10.1, U2.6 (CH5)
/GPIO/AIN5P: J4.10, R10.2
/GPIO/AIN6: R11.1, U2.7 (CH6)
/GPIO/AIN6P: J4.9, R11.2
/GPIO/AIN7: R12.1, U2.8 (CH7)
/GPIO/AIN7P: J4.12, R12.2
/GPIO/AIN_SELECT_3V: U1.58 (GPIO2), U5.8 (1A3)
/GPIO/AIN_SELECT_5V: TP5.1, U2.10 (~CS~/SHDN), U5.12 (1Y3)
/GPIO/CS0: U1.41 (GPIO25), U4.17 (2A0)
/GPIO/CS0P: J4.16, R74.2
/GPIO/CS6: U1.56 (GPIO3), U4.11 (2A3)
/GPIO/CS6P: J4.24, R77.2
/GPIO/GPIO8: R16.1, U1.39 (GPIO8)
/GPIO/GPIO8P: J4.53, R16.2
/GPIO/GPIO16: R15.1, U1.29 (GPIO16)
/GPIO/GPIO16P: J4.55, R15.2
/GPIO/GPIO18: R19.1, U1.49 (GPIO18)
/GPIO/GPIO18P: J4.54, R19.2
/GPIO/GPIO24: R17.1, U1.45 (GPIO24)
/GPIO/GPIO24P: J4.56, R17.2
/GPIO/GPIO26: R14.1, U1.24 (GPIO26)
/GPIO/GPIO26P: J4.51, R14.2
/GPIO/GPIO27: R18.1, U1.48 (GPIO27)
/GPIO/GPIO27P: J4.58, R18.2
/GPIO/MISO: R81.1, R85.2, TP2.1, U3.12; also elsewhere on the board
/GPIO/MISO0: U1.40 (GPIO9), U3.8
/GPIO/MISO0P: J4.20, U3.9
/GPIO/MISO4_3V: U1.34 (GPIO5), U3.11
/GPIO/MISO6: U1.26 (GPIO19), U3.6
/GPIO/MISO6P: J4.28, U3.5
/GPIO/MOSI: R80.2, TP4.1, U2.11 (Din); also elsewhere on the board
/GPIO/MOSI0: U1.44 (GPIO10), U4.13 (2A2)
/GPIO/MOSI0P: J4.22, R76.2
/GPIO/MOSI4_3V: U1.30 (GPIO6), U5.6 (1A2)
/GPIO/MOSI6: U1.27 (GPIO20), U4.6 (1A2)
/GPIO/MOSI6P: J4.30, R72.2
/GPIO/MOTOR_SELECT: R83.2, TP7.1; also elsewhere on the board
/GPIO/MOTOR_SELECT_3V: U1.54 (GPIO4), U5.15 (2A1)
/GPIO/POWERED: R22.2, U5.9 (2Y3)
/GPIO/POWER_SELECT: R82.2, TP21.1; also elsewhere on the board
/GPIO/POWER_SELECT_3V: U1.50 (GPIO17), U5.17 (2A0)
/GPIO/PWM0: U1.31 (GPIO12), U4.4 (1A1)
/GPIO/PWM0P: J4.34, R71.2
/GPIO/PWM1: U1.28 (GPIO13), U4.2 (1A0)
/GPIO/PWM1P: J4.36, R70.2
/GPIO/RxD0: U1.51 (GPIO15), U3.3
/GPIO/RxD0P: J4.44, U3.2
/GPIO/SCL6: R4.2, R21.1, U1.47 (GPIO23)
/GPIO/SCL6P: J4.50, R21.2
/GPIO/SCLK: R79.2, TP3.1, U2.13 (CLK); also elsewhere on the board
/GPIO/SCLK0: U1.38 (GPIO11), U4.15 (2A1)
/GPIO/SCLK0P: J4.18, R75.2
/GPIO/SCLK4_3V: U1.37 (GPIO7), U5.4 (1A1)
/GPIO/SCLK6: U1.25 (GPIO21), U4.8 (1A3)
/GPIO/SCLK6P: J4.26, R73.2
/GPIO/SDA6: R3.2, R20.1, U1.46 (GPIO22)
/GPIO/SDA6P: J4.48, R20.2
/GPIO/TxD0: U1.55 (GPIO14), U5.2 (1A0)
/GPIO/TxD0P: J4.42, R78.2
/GPIO/nEXTRST: U5.13 (2A2); also elsewhere on the board
/GPIO/nEXTRST_pow: R87.2, U5.7 (2Y2)
/SCL1: U1.35 (ID_SC); also elsewhere on the board
/SDA1: U1.36 (ID_SD); also elsewhere on the board
/cm4/LED_Pwr: U5.11 (2A3); also elsewhere on the board
unnamed: C3.1, L1.1, TP1.1, U2.15 (Vref), U2.16 (Vdd)
unnamed: D1.1 (K), R13.1
unnamed: D2.1 (K), R22.1
unnamed: D3.1 (K), R23.1
unnamed: D30.1 (K), R87.1
unnamed: R70.1, U4.18 (1Y0)
unnamed: R71.1, U4.16 (1Y1)
unnamed: R72.1, U4.14 (1Y2)
unnamed: R73.1, U4.12 (1Y3)
unnamed: R74.1, U4.3 (2Y0)
unnamed: R75.1, U4.5 (2Y1)
unnamed: R76.1, U4.7 (2Y2)
unnamed: R77.1, U4.9 (2Y3)
unnamed: R78.1, U5.18 (1Y0)
unnamed: R79.1, U5.16 (1Y1)
unnamed: R80.1, U5.14 (1Y2)
unnamed: R81.2, U2.12 (Dout)
unnamed: R82.1, U5.3 (2Y0)
unnamed: R83.1, U5.5 (2Y1)

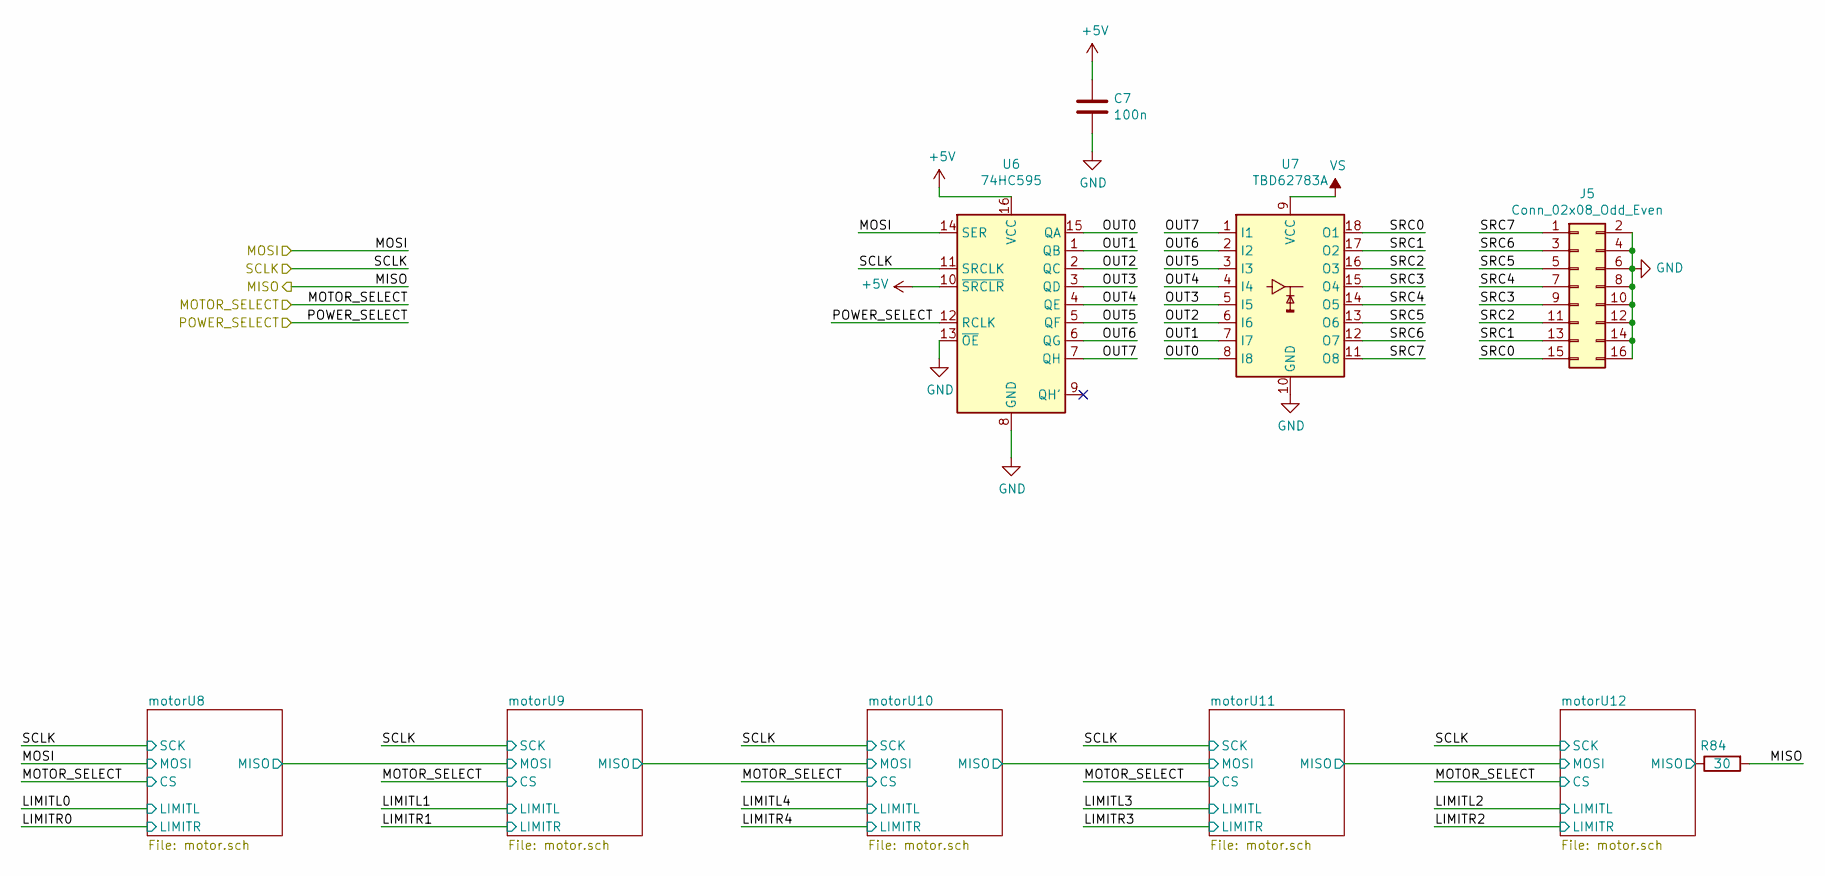
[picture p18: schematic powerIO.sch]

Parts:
C7: 100n; C_0402_1005Metric
J5: Conn_02x08_Odd_Even; PinHeader_2x08_P2.54mm_Vertical
R84: 30; R_0402_1005Metric
U6: 74HC595; SSOP-16_5.3x6.2mm_P0.65mm
U7: TBD62783A; SSOP-18_4.4x6.5mm_P0.65mm

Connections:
+5V: C7.1, U6.10 (~SRCLR), U6.16 (VCC); also elsewhere on the board
/GPIO/MISO: R84.2; also elsewhere on the board
/GPIO/MOSI: U6.14 (SER); also elsewhere on the board
/GPIO/POWER_SELECT: U6.12 (RCLK); also elsewhere on the board
/GPIO/SCLK: U6.11 (SRCLK); also elsewhere on the board
/powerIO/OUT0: U6.15 (QA), U7.8 (I8)
/powerIO/OUT1: U6.1 (QB), U7.7 (I7)
/powerIO/OUT2: U6.2 (QC), U7.6 (I6)
/powerIO/OUT3: U6.3 (QD), U7.5 (I5)
/powerIO/OUT4: U6.4 (QE), U7.4 (I4)
/powerIO/OUT5: U6.5 (QF), U7.3 (I3)
/powerIO/OUT6: U6.6 (QG), U7.2 (I2)
/powerIO/OUT7: U6.7 (QH), U7.1 (I1)
/powerIO/SRC0: J5.15, U7.18 (O1)
/powerIO/SRC1: J5.13, U7.17 (O2)
/powerIO/SRC2: J5.11, U7.16 (O3)
/powerIO/SRC3: J5.9, U7.15 (O4)
/powerIO/SRC4: J5.7, U7.14 (O5)
/powerIO/SRC5: J5.5, U7.13 (O6)
/powerIO/SRC6: J5.3, U7.12 (O7)
/powerIO/SRC7: J5.1, U7.11 (O8)
/powerIO/motorU12/MISO: R84.1; also elsewhere on the board
VS: U7.9 (VCC); also elsewhere on the board

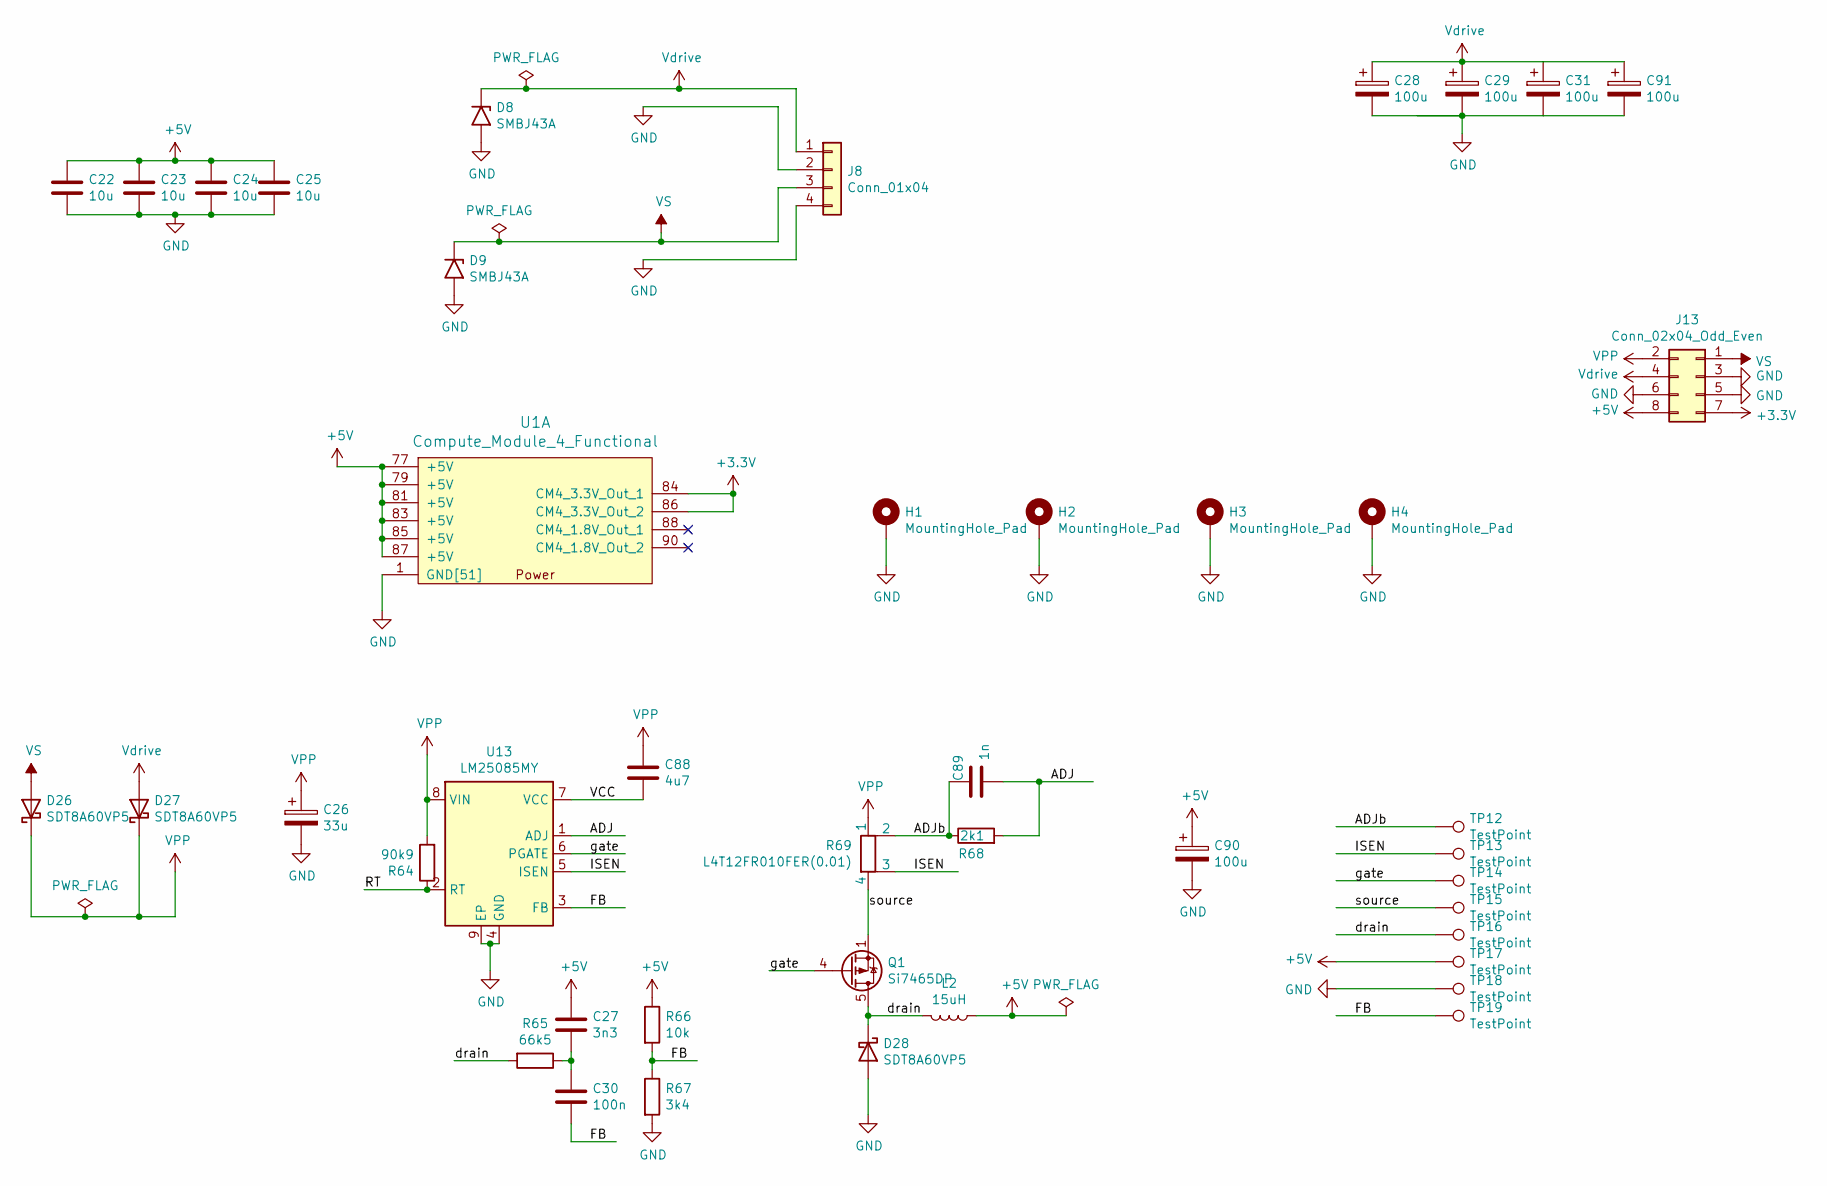
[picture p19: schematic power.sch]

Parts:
C22, C23, C24, C25: 10u; C_1206_3216Metric
C26: 33u; CP_Radial_D8.0mm_P3.50mm
C27: 3n3; C_0402_1005Metric
C28, C29, C31, C90, C91: 100u; CP_Radial_D8.0mm_P3.50mm
C30: 100n; C_0402_1005Metric
C88: 4u7; C_1206_3216Metric
C89: 1n; C_0402_1005Metric
D8, D9: SMBJ43A; D_SMB
D26, D27, D28: SDT8A60VP5; D_PowerDI-5
H1, H2, H3, H4: MountingHole_Pad; MountingHole_3.2mm_M3_Pad_Via
J8: Conn_01x04; TerminalBlock_Phoenix_MKDS-1,5-4-5.08_1x04_P5.08mm_Horizont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
J13: Conn_02x04_Odd_Even; PinSocket_2x04_P2.54mm_Vertical
L2: 15uH; L_0603_1608Metric
Q1: Si7465DP; PowerPAK_SO-8_Single
R64: 90k9; R_0402_1005Metric
R65: 66k5; R_0402_1005Metric
R66: 10k; R_0402_1005Metric
R67: 3k4; R_0402_1005Metric
R68: 2k1; R_0402_1005Metric
R69: L4T12FR010FER(0.01); R_Shunt_Ohmite_4LT12
TP12, TP13, TP14, TP15, TP16, TP17, TP18, TP19: TestPoint; TestPoint_Pad_1.5x1.5mm
U1: Compute_Module_4_Functional; Raspberry-Pi-4-Compute-Module
U13: LM25085MY; MSOP-8-1EP_3x3mm_P0.65mm_EP1.73x1.85mm_ThermalVias

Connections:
+5V: C22.1, C23.1, C24.1, C25.1, C27.1, C90.1, J13.8, L2.1, R66.1, TP17.1, U1.77 (+5V), U1.79 (+5V), U1.81 (+5V), U1.83 (+5V), U1.85 (+5V), U1.87 (+5V); also elsewhere on the board
/power/ADJ: C89.2, R68.2, U13.1 (ADJ)
/power/ADJb: C89.1, R68.1, R69.2, TP12.1
/power/FB: C30.2, R66.2, R67.1, TP19.1, U13.3 (FB)
/power/ISEN: R69.3, TP13.1, U13.5 (ISEN)
/power/RT: R64.1, U13.2 (RT)
/power/VCC: C88.2, U13.7 (VCC)
/power/drain: D28.1 (K), L2.2, Q1.5 (D), R65.2, TP16.1
/power/gate: Q1.4 (G), TP14.1, U13.6 (PGATE)
/power/source: Q1.1 (S), Q1.2 (S), Q1.3 (S), R69.4, TP15.1
unnamed: C27.2, C30.1, R65.1
VPP: C26.1, C88.1, D26.1 (K), D27.1 (K), J13.2, R64.2, R69.1, U13.8 (VIN)
VS: D9.1 (A1), D26.2 (A), J8.3, J13.1; also elsewhere on the board
Vdrive: C28.1, C29.1, C31.1, C91.1, D8.1 (A1), D27.2 (A), J8.1, J13.4; also elsewhere on the board

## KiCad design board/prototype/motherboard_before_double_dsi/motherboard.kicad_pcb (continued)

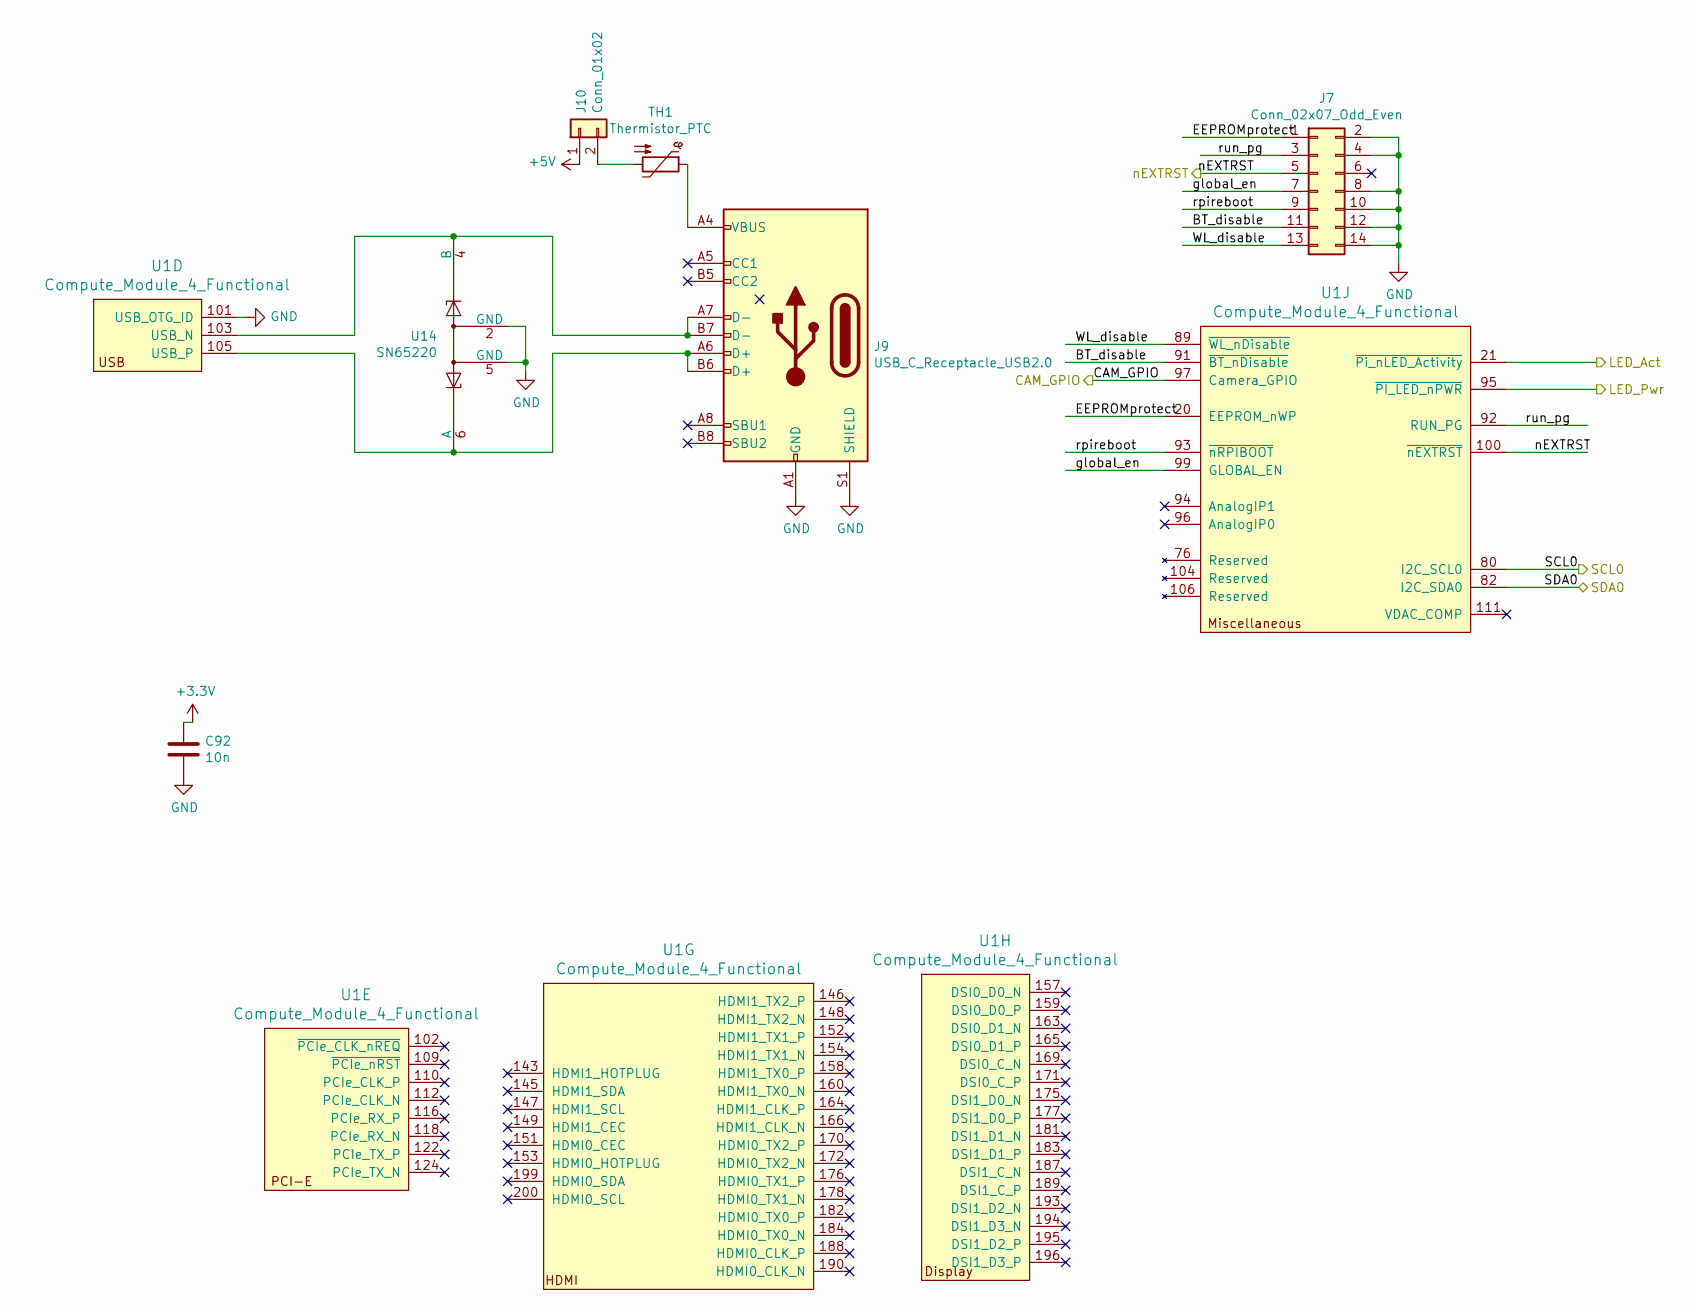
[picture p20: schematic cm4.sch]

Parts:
C92: 10n; C_0402_1005Metric
J7: Conn_02x07_Odd_Even; PinHeader_2x07_P2.54mm_Vertical
J9: USB_C_Receptacle_USB2.0; USB_C_Receptacle_Palconn_UTC16-G
J10: Conn_01x02; PinSocket_1x02_P2.54mm_Vertical
TH1: Thermistor_PTC
U1: Compute_Module_4_Functional; Raspberry-Pi-4-Compute-Module
U14: SN65220; SOT-23-6

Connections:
/CAM_GPIO: U1.97 (Camera_GPIO); also elsewhere on the board
/GPIO/ACT_LED: U1.21 (~Pi_nLED_Activity); also elsewhere on the board
/GPIO/nEXTRST: J7.5, U1.100 (~nEXTRST); also elsewhere on the board
/SCL0: U1.80 (I2C_SCL0); also elsewhere on the board
/SDA0: U1.82 (I2C_SDA0); also elsewhere on the board
/cm4/BT_disable: J7.11, U1.91 (~BT_nDisable)
/cm4/EEPROMprotect: J7.1, U1.20 (EEPROM_nWP)
/cm4/LED_Pwr: U1.95 (~PI_LED_nPWR); also elsewhere on the board
/cm4/USB+: J9.A6 (D+), J9.B6 (D+), U1.105 (USB_P), U14.6 (A); also elsewhere on the board
/cm4/USB-: J9.A7 (D-), J9.B7 (D-), U1.103 (USB_N), U14.4 (B); also elsewhere on the board
/cm4/WL_disable: J7.13, U1.89 (~WL_nDisable)
/cm4/global_en: J7.7, U1.99 (GLOBAL_EN)
/cm4/rpireboot: J7.9, U1.93 (~nRPIBOOT)
/cm4/run_pg: J7.3, U1.92 (RUN_PG)
unnamed: J9.A4 (VBUS), J9.A9 (VBUS), J9.B4 (VBUS), J9.B9 (VBUS), TH1.1

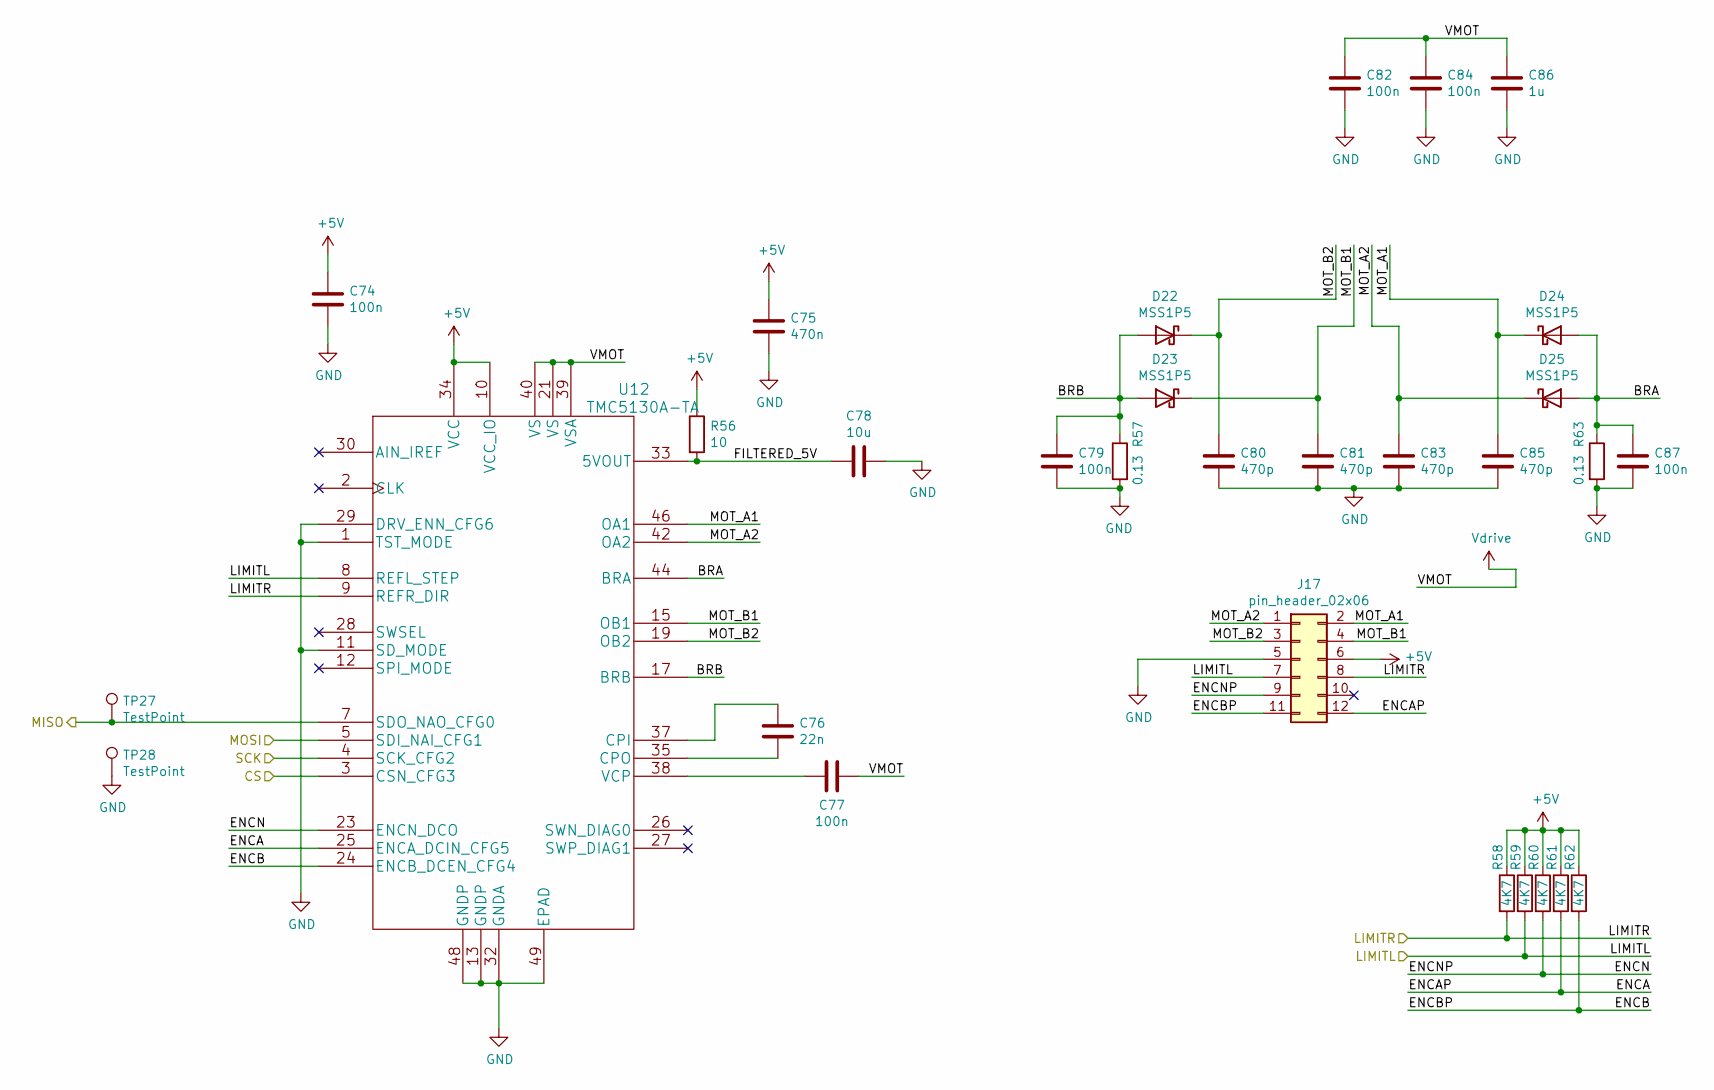
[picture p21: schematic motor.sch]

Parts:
C8, C11, C13, C16, C18, C21: 100n; C_0402_1005Metric
C9: 470n; C_0402_1005Metric
C10: 22n; C_0402_1005Metric
C14, C15, C17, C19: 470p; C_0402_1005Metric
C20: 1u; C_0603_1608Metric
C36: 10u; C_1206_3216Metric
D4, D5, D6, D7: MSS1P5; DO-219AD
J6: pin_header_02x06; PinHeader_2x06_P2.54mm_Vertical
R24: 10; R_0402_1005Metric
R25, R31: 0.13; R_1206_3216Metric
R26, R27, R28, R29, R30: 4K7; R_0402_1005Metric
TP8, TP9: TestPoint; TestPoint_Pad_1.5x1.5mm
U8: TMC5130A-TA; TQFP-48-1EP_7x7mm_P0.5mm_EP5x5mm_ThermalVias

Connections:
+5V: C8.1, C9.1, J6.6, R24.1, R26.1, R27.1, R28.1, R29.1, R30.1, U8.10 (VCC_IO), U8.34 (VCC); also elsewhere on the board
/GPIO/MOSI: U8.5 (SDI_NAI_CFG1); also elsewhere on the board
/GPIO/MOTOR_SELECT: U8.3 (CSN_CFG3); also elsewhere on the board
/GPIO/SCLK: U8.4 (SCK_CFG2); also elsewhere on the board
/powerIO/LIMITL0: J6.7, R27.2, U8.8 (REFL_STEP)
/powerIO/LIMITR0: J6.8, R26.2, U8.9 (REFR_DIR)
/powerIO/motorU8/BRA: C21.1, D6.2 (A), D7.2 (A), R31.1, U8.44 (BRA)
/powerIO/motorU8/BRB: C13.1, D4.2 (A), D5.2 (A), R25.1, U8.17 (BRB)
/powerIO/motorU8/ENCA: J6.12, R29.2, U8.25 (ENCA_DCIN_CFG5)
/powerIO/motorU8/ENCB: J6.11, R30.2, U8.24 (ENCB_DCEN_CFG4)
/powerIO/motorU8/ENCN: J6.9, R28.2, U8.23 (ENCN_DCO)
/powerIO/motorU8/MISO: TP8.1, U8.7 (SDO_NAO_CFG0); also elsewhere on the board
/powerIO/motorU8/MOT_A1: C19.1, D6.1 (K), J6.2, U8.46 (OA1)
/powerIO/motorU8/MOT_A2: C17.1, D7.1 (K), J6.1, U8.42 (OA2)
/powerIO/motorU8/MOT_B1: C15.1, D5.1 (K), J6.4, U8.15 (OB1)
/powerIO/motorU8/MOT_B2: C14.1, D4.1 (K), J6.3, U8.19 (OB2)
unnamed: C10.1, U8.37 (CPI)
unnamed: C10.2, U8.35 (CPO)
unnamed: C11.1, U8.38 (VCP)
Vdrive: C11.2, C16.1, C18.1, C20.1, U8.21 (VS), U8.39 (VSA), U8.40 (VS); also elsewhere on the board

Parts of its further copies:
C12, C50, C64, C78: 10u; C_1206_3216Metric
C32, C35, C37, C40, C42, C45, C46, C49, C51, C54, C56, C59, C60, C63, C65, C68, C70, C73, C74, C77, C79, C82, C84, C87: 100n; C_0402_1005Metric
C33, C47, C61, C75: 470n; C_0402_1005Metric
C34, C48, C62, C76: 22n; C_0402_1005Metric
C38, C39, C41, C43, C52, C53, C55, C57, C66, C67, C69, C71, C80, C81, C83, C85: 470p; C_0402_1005Metric
C44, C58, C72, C86: 1u; C_0603_1608Metric
D10, D11, D12, D13, D14, D15, D16, D17, D18, D19, D20, D21, D22, D23, D24, D25: MSS1P5; DO-219AD
J14, J15, J16, J17: pin_header_02x06; PinHeader_2x06_P2.54mm_Vertical
R32, R40, R48, R56: 10; R_0402_1005Metric
R33, R39, R41, R47, R49, R55, R57, R63: 0.13; R_1206_3216Metric
R34, R35, R36, R37, R38, R42, R43, R44, R45, R46, R50, R51, R52, R53, R54, R58, R59, R60, R61, R62: 4K7; R_0402_1005Metric
TP10, TP11, TP23, TP24, TP25, TP26, TP27, TP28: TestPoint; TestPoint_Pad_1.5x1.5mm
U9, U10, U11, U12: TMC5130A-TA; TQFP-48-1EP_7x7mm_P0.5mm_EP5x5mm_ThermalVias

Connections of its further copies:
+5V: C32.1, C33.1, C46.1, C47.1, C60.1, C61.1, C74.1, C75.1, J14.6, J15.6, J16.6, J17.6, R32.1, R34.1, R35.1, R36.1, R37.1, R38.1, R40.1, R42.1, R43.1, R44.1, R45.1, R46.1, R48.1, R50.1, R51.1, R52.1, R53.1, R54.1, R56.1, R58.1, R59.1, R60.1, R61.1, R62.1, U9.10 (VCC_IO), U9.34 (VCC), U10.10 (VCC_IO), U10.34 (VCC), U11.10 (VCC_IO), U11.34 (VCC), U12.10 (VCC_IO), U12.34 (VCC); also elsewhere on the board
/GPIO/MOTOR_SELECT: U9.3 (CSN_CFG3), U10.3 (CSN_CFG3), U11.3 (CSN_CFG3), U12.3 (CSN_CFG3); also elsewhere on the board
/GPIO/SCLK: U9.4 (SCK_CFG2), U10.4 (SCK_CFG2), U11.4 (SCK_CFG2), U12.4 (SCK_CFG2); also elsewhere on the board
/powerIO/LIMITL1: J14.7, R35.2, U9.8 (REFL_STEP)
/powerIO/LIMITL2: J17.7, R59.2, U12.8 (REFL_STEP)
/powerIO/LIMITL3: J16.7, R51.2, U11.8 (REFL_STEP)
/powerIO/LIMITL4: J15.7, R43.2, U10.8 (REFL_STEP)
/powerIO/LIMITR1: J14.8, R34.2, U9.9 (REFR_DIR)
/powerIO/LIMITR2: J17.8, R58.2, U12.9 (REFR_DIR)
/powerIO/LIMITR3: J16.8, R50.2, U11.9 (REFR_DIR)
/powerIO/LIMITR4: J15.8, R42.2, U10.9 (REFR_DIR)
/powerIO/motorU8/MISO: U9.5 (SDI_NAI_CFG1); also elsewhere on the board
/powerIO/motorU9/BRA: C45.1, D12.2 (A), D13.2 (A), R39.1, U9.44 (BRA)
/powerIO/motorU9/BRB: C37.1, D10.2 (A), D11.2 (A), R33.1, U9.17 (BRB)
/powerIO/motorU9/ENCA: J14.12, R37.2, U9.25 (ENCA_DCIN_CFG5)
/powerIO/motorU9/ENCB: J14.11, R38.2, U9.24 (ENCB_DCEN_CFG4)
/powerIO/motorU9/ENCN: J14.9, R36.2, U9.23 (ENCN_DCO)
/powerIO/motorU9/MISO: TP10.1, U9.7 (SDO_NAO_CFG0), U10.5 (SDI_NAI_CFG1)
/powerIO/motorU9/MOT_A1: C43.1, D12.1 (K), J14.2, U9.46 (OA1)
/powerIO/motorU9/MOT_A2: C41.1, D13.1 (K), J14.1, U9.42 (OA2)
/powerIO/motorU9/MOT_B1: C39.1, D11.1 (K), J14.4, U9.15 (OB1)
/powerIO/motorU9/MOT_B2: C38.1, D10.1 (K), J14.3, U9.19 (OB2)
/powerIO/motorU10/BRA: C59.1, D16.2 (A), D17.2 (A), R47.1, U10.44 (BRA)
/powerIO/motorU10/BRB: C51.1, D14.2 (A), D15.2 (A), R41.1, U10.17 (BRB)
/powerIO/motorU10/ENCA: J15.12, R45.2, U10.25 (ENCA_DCIN_CFG5)
/powerIO/motorU10/ENCB: J15.11, R46.2, U10.24 (ENCB_DCEN_CFG4)
/powerIO/motorU10/ENCN: J15.9, R44.2, U10.23 (ENCN_DCO)
/powerIO/motorU10/FILTERED_5V: C50.2, R40.2, U10.33 (5VOUT)
/powerIO/motorU10/MISO: TP23.1, U10.7 (SDO_NAO_CFG0), U11.5 (SDI_NAI_CFG1)
/powerIO/motorU10/MOT_A1: C57.1, D16.1 (K), J15.2, U10.46 (OA1)
/powerIO/motorU10/MOT_A2: C55.1, D17.1 (K), J15.1, U10.42 (OA2)
/powerIO/motorU10/MOT_B1: C53.1, D15.1 (K), J15.4, U10.15 (OB1)
/powerIO/motorU10/MOT_B2: C52.1, D14.1 (K), J15.3, U10.19 (OB2)
/powerIO/motorU11/BRA: C73.1, D20.2 (A), D21.2 (A), R55.1, U11.44 (BRA)
/powerIO/motorU11/BRB: C65.1, D18.2 (A), D19.2 (A), R49.1, U11.17 (BRB)
/powerIO/motorU11/ENCA: J16.12, R53.2, U11.25 (ENCA_DCIN_CFG5)
/powerIO/motorU11/ENCB: J16.11, R54.2, U11.24 (ENCB_DCEN_CFG4)
/powerIO/motorU11/ENCN: J16.9, R52.2, U11.23 (ENCN_DCO)
/powerIO/motorU11/FILTERED_5V: C64.2, R48.2, U11.33 (5VOUT)
/powerIO/motorU11/MISO: TP25.1, U11.7 (SDO_NAO_CFG0), U12.5 (SDI_NAI_CFG1)
/powerIO/motorU11/MOT_A1: C71.1, D20.1 (K), J16.2, U11.46 (OA1)
/powerIO/motorU11/MOT_A2: C69.1, D21.1 (K), J16.1, U11.42 (OA2)
/powerIO/motorU11/MOT_B1: C67.1, D19.1 (K), J16.4, U11.15 (OB1)
/powerIO/motorU11/MOT_B2: C66.1, D18.1 (K), J16.3, U11.19 (OB2)
/powerIO/motorU12/BRA: C87.1, D24.2 (A), D25.2 (A), R63.1, U12.44 (BRA)
/powerIO/motorU12/BRB: C79.1, D22.2 (A), D23.2 (A), R57.1, U12.17 (BRB)
/powerIO/motorU12/ENCA: J17.12, R61.2, U12.25 (ENCA_DCIN_CFG5)
/powerIO/motorU12/ENCB: J17.11, R62.2, U12.24 (ENCB_DCEN_CFG4)
/powerIO/motorU12/ENCN: J17.9, R60.2, U12.23 (ENCN_DCO)
/powerIO/motorU12/FILTERED_5V: C78.2, R56.2, U12.33 (5VOUT)
/powerIO/motorU12/MISO: TP27.1, U12.7 (SDO_NAO_CFG0); also elsewhere on the board
/powerIO/motorU12/MOT_A1: C85.1, D24.1 (K), J17.2, U12.46 (OA1)
/powerIO/motorU12/MOT_A2: C83.1, D25.1 (K), J17.1, U12.42 (OA2)
/powerIO/motorU12/MOT_B1: C81.1, D23.1 (K), J17.4, U12.15 (OB1)
/powerIO/motorU12/MOT_B2: C80.1, D22.1 (K), J17.3, U12.19 (OB2)
unnamed: C34.1, U9.37 (CPI)
unnamed: C34.2, U9.35 (CPO)
unnamed: C35.1, U9.38 (VCP)
unnamed: C48.1, U10.37 (CPI)
unnamed: C48.2, U10.35 (CPO)
unnamed: C49.1, U10.38 (VCP)
unnamed: C62.1, U11.37 (CPI)
unnamed: C62.2, U11.35 (CPO)
unnamed: C63.1, U11.38 (VCP)
unnamed: C76.1, U12.37 (CPI)
unnamed: C76.2, U12.35 (CPO)
unnamed: C77.1, U12.38 (VCP)
Vdrive: C35.2, C40.1, C42.1, C44.1, C49.2, C54.1, C56.1, C58.1, C63.2, C68.1, C70.1, C72.1, C77.2, C82.1, C84.1, C86.1, U9.21 (VS), U9.39 (VSA), U9.40 (VS), U10.21 (VS), U10.39 (VSA), U10.40 (VS), U11.21 (VS), U11.39 (VSA), U11.40 (VS), U12.21 (VS), U12.39 (VSA), U12.40 (VS); also elsewhere on the board

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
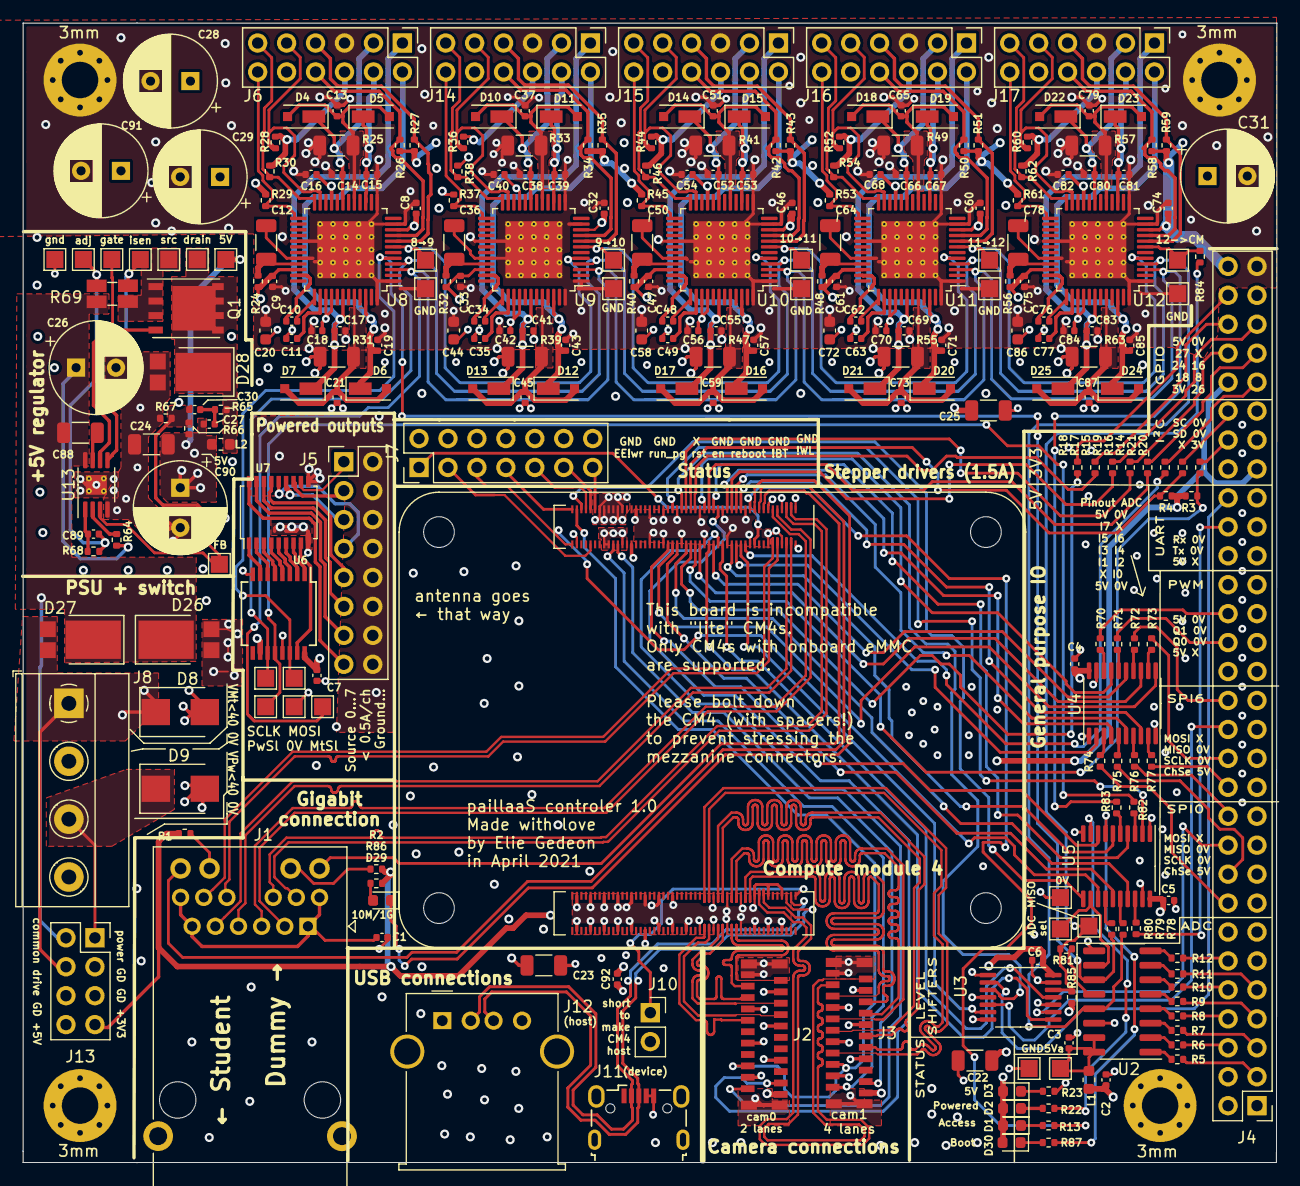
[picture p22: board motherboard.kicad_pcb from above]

Board: 4 copper layers, 110.0 x 100.0 mm, 273 parts (0 on the bottom side), 249 nets.

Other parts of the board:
J11: USB_B; USB_Micro-B_Wuerth_629105150521
J12: USB_A; USB_A_Molex_67643_Horizontal

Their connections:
+5V: J12.1; also elsewhere on the board
/cm4/USB+: J11.3, J12.3; also elsewhere on the board
/cm4/USB-: J11.2, J12.2; also elsewhere on the board

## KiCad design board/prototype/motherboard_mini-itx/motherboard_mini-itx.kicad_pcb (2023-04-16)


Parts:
J1: RJMG2310228A0ER
RN10: 4x1k8; R_Array_Concave_4x0402
U1: Compute_Module_4_Functional; Raspberry-Pi-4-Compute-Module

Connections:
/ethernet/ETH_0+: J1.2 (MX1+), U1.12 (Ethernet_Pair0_P)
/ethernet/ETH_0-: J1.3 (MX1-), U1.10 (Ethernet_Pair0_N)
/ethernet/ETH_1+: J1.4 (MX2+), U1.4 (Ethernet_Pair1_P)
/ethernet/ETH_1-: J1.5 (MX2-), U1.6 (Ethernet_Pair1_N)
/ethernet/ETH_2+: J1.7 (MX3+), U1.11 (Ethernet_Pair2_P)
/ethernet/ETH_2-: J1.8 (MX3-), U1.9 (Ethernet_Pair2_N)
/ethernet/ETH_3+: J1.9 (MX4+), U1.3 (Ethernet_Pair3_P)
/ethernet/ETH_3-: J1.10 (MX4-), U1.5 (Ethernet_Pair3_N)
/ethernet/ETH_LED_green: RN10.2 (R2.1), U1.17 (~Ethernet_nLED2)
/ethernet/ETH_LED_orange: RN10.3 (R3.1), U1.19 (~Ethernet_nLED1)
/ethernet/ETH_LED_yellow: RN10.1 (R1.1), U1.15 (~Ethernet_nLED3)
unnamed: J1.11 (CY), RN10.8 (R1.2)
unnamed: J1.13 (CG), RN10.7 (R2.2)
unnamed: J1.15 (CO), RN10.6 (R3.2)

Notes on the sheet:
Amber = 10M Green = 100M Yellow = 1G


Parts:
J2, J3: Conn_01x22_MountingPin; SFV22R-1STBE1HLF
U1: Compute_Module_4_Functional; Raspberry-Pi-4-Compute-Module

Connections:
3V3bus: J2.22, J3.22; also elsewhere on the board
/CAM_GPIO: J2.17, J3.17; also elsewhere on the board
/SCL0: J3.20; also elsewhere on the board
/SCL1: J2.20; also elsewhere on the board
/SDA0: J3.21; also elsewhere on the board
/SDA1: J2.21; also elsewhere on the board
/camera/CAM0C+: J2.9, U1.142 (CAM0_C_P)
/camera/CAM0C-: J2.8, U1.140 (CAM0_C_N)
/camera/CAM0D0+: J2.3, U1.130 (CAM0_D0_P)
/camera/CAM0D0-: J2.2, U1.128 (CAM0_D0_N)
/camera/CAM0D1+: J2.6, U1.136 (CAM0_D1_P)
/camera/CAM0D1-: J2.5, U1.134 (CAM0_D1_N)
/camera/CAM1C+: J3.9, U1.129 (CAM1_C_P)
/camera/CAM1C-: J3.8, U1.127 (CAM1_C_N)
/camera/CAM1D0+: J3.3, U1.117 (CAM1_D0_P)
/camera/CAM1D0-: J3.2, U1.115 (CAM1_D0_N)
/camera/CAM1D1+: J3.6, U1.123 (CAM1_D1_P)
/camera/CAM1D1-: J3.5, U1.121 (CAM1_D1_N)
/camera/CAM1D2+: J3.12, U1.135 (CAM1_D2_P)
/camera/CAM1D2-: J3.11, U1.133 (CAM1_D2_N)
/camera/CAM1D3+: J3.15, U1.141 (CAM1_D3_P)
/camera/CAM1D3-: J3.14, U1.139 (CAM1_D3_N)


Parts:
C1, C6, C57, C58: 100n; C_0402_1005Metric
D1, D2, D3, D4: RED; LED_0603_1608Metric
RN7: 4x10k; R_Array_Concave_4x0402
RN8, RN9: 4x1k8; R_Array_Concave_4x0402
RN18: 4x39; R_Array_Concave_4x0402
SW1: PTS526 SM15 SMTR2 LFS; SW_Push_1P1T_NO_Vertical_Wuerth_434133025816
TP1: 3V3a; TestPoint_Pad_1.0x1.0mm
TP3, TP4, TP10: GND; TestPoint_Pad_1.0x1.0mm
TP6: MISO; TestPoint_Pad_1.0x1.0mm
TP7: SCLK; TestPoint_Pad_1.0x1.0mm
TP8: MOSI; TestPoint_Pad_1.0x1.0mm
TP9: MotSel; TestPoint_Pad_1.0x1.0mm
U1: Compute_Module_4_Functional; Raspberry-Pi-4-Compute-Module
U3, U5: 74LVC4245A; TSSOP-24_4.4x7.8mm_P0.65mm

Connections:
3V3mcu: C6.1, C58.1, D3.2 (A), RN7.1 (R1.1), RN7.2 (R2.1), RN7.5 (R4.2), RN9.6 (R3.2), RN9.7 (R2.2), U1.78 (GPIO_VREF), U3.23 (VCCB), U3.24 (VCCB), U5.23 (VCCB), U5.24 (VCCB); also elsewhere on the board
5Vsb: C1.1, C57.1, D1.2 (A), D2.2 (A), D4.2 (A), U3.1 (VCCA), U3.2 (DIR), U3.3 (A0), U3.4 (A1), U5.1 (VCCA); also elsewhere on the board
/GPIO/+3V3a: TP1.1; also elsewhere on the board
/GPIO/ACT_LED: RN8.1 (R1.1); also elsewhere on the board
/GPIO/AIN0: RN9.8 (R1.2); also elsewhere on the board
/GPIO/CS6: U1.56 (GPIO3), U5.18 (B3)
/GPIO/CS6_5V: U5.6 (A3); also elsewhere on the board
/GPIO/GPIO8: U1.39 (GPIO8); also elsewhere on the board
/GPIO/GPIO9: U1.40 (GPIO9); also elsewhere on the board
/GPIO/GPIO10: U1.44 (GPIO10); also elsewhere on the board
/GPIO/GPIO11: U1.38 (GPIO11); also elsewhere on the board
/GPIO/GPIO16: U1.29 (GPIO16); also elsewhere on the board
/GPIO/GPIO18: U1.49 (GPIO18); also elsewhere on the board
/GPIO/GPIO24: U1.45 (GPIO24); also elsewhere on the board
/GPIO/GPIO25: U1.41 (GPIO25); also elsewhere on the board
/GPIO/LED_BTN: RN9.5 (R4.2), U1.50 (GPIO17)
/GPIO/MISO: RN7.7 (R2.2), RN18.8 (R1.2), TP6.1, U1.34 (GPIO5); also elsewhere on the board
/GPIO/MISO6: U1.26 (GPIO19), U3.19 (B2)
/GPIO/MISO6_5V: U3.5 (A2); also elsewhere on the board
/GPIO/MOSI: RN18.6 (R3.2), TP8.1; also elsewhere on the board
/GPIO/MOSI4_3V: RN18.3 (R3.1), U1.30 (GPIO6)
/GPIO/MOSI6: U1.27 (GPIO20), U5.19 (B2)
/GPIO/MOSI6_5V: U5.5 (A2); also elsewhere on the board
/GPIO/MOTOR_SELECT: RN18.5 (R4.2), TP9.1; also elsewhere on the board
/GPIO/MOTOR_SELECT_3V: RN18.4 (R4.1), U1.54 (GPIO4)
/GPIO/POWERED: RN8.2 (R2.1), U5.9 (A6)
/GPIO/PS_ON: U5.8 (A5); also elsewhere on the board
/GPIO/PWM0: U1.31 (GPIO12), U5.20 (B1)
/GPIO/PWM0_5V: U5.4 (A1); also elsewhere on the board
/GPIO/PWM1: U1.28 (GPIO13), U5.21 (B1)
/GPIO/PWM1_5V: U5.3 (A0); also elsewhere on the board
/GPIO/RxD0: U1.51 (GPIO15), U3.18 (B3)
/GPIO/RxD0_5V: U3.6 (A3); also elsewhere on the board
/GPIO/SCL6: RN9.3 (R3.1), U1.47 (GPIO23); also elsewhere on the board
/GPIO/SCLK: RN18.7 (R2.2), TP7.1; also elsewhere on the board
/GPIO/SCLK4_3V: RN18.2 (R2.1), U1.37 (GPIO7)
/GPIO/SCLK6: U1.25 (GPIO21), U5.17 (B4)
/GPIO/SCLK6_5V: U5.7 (A4); also elsewhere on the board
/GPIO/SDA6: RN9.2 (R2.1), U1.46 (GPIO22); also elsewhere on the board
/GPIO/TxD0: U1.55 (GPIO14), U5.14 (B7)
/GPIO/TxD0_5V: U5.10 (A7); also elsewhere on the board
/SCL1: U1.35 (ID_SC); also elsewhere on the board
/SDA1: U1.36 (ID_SD); also elsewhere on the board
/cm4/LED_Pwr: U5.15 (B6); also elsewhere on the board
unnamed: D1.1 (K), RN8.8 (R1.2)
unnamed: D2.1 (K), RN8.7 (R2.2)
unnamed: D3.1 (K), RN8.5 (R4.2)
unnamed: D4.1 (K), RN8.6 (R3.2)
unnamed: RN7.4 (R4.1), RN8.4 (R4.1), RN9.4 (R4.1), SW1.1
unnamed 264: RN18.1 (R1.1); also elsewhere on the board

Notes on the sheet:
Testpoints
GPIO connector
Protection
3.3V->5V shifter
5V->3.3V shifter
CM4 connector
Status Leds


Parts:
C59, C60, C80, C81: 100u; CP_Radial_D8.0mm_P3.50mm
RN20: 4x39; R_Array_Concave_4x0402

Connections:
+12V: C59.1, C60.1, C80.1, C81.1; also elsewhere on the board
/GPIO/MISO: RN20.5 (R4.2); also elsewhere on the board
/powerIO/motorU12/MISO: RN20.4 (R4.1); also elsewhere on the board

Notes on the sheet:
Stepper motor drivers
Global decoupling
Imported signals

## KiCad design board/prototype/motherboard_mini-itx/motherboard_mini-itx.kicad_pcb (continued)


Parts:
C53, C63, C64, C76, C78: 10u; C_0805_2012Metric
C62, C77: 100n; C_0402_1005Metric
C65, C79: 100u; CP_Radial_D8.0mm_P3.50mm
H1, H2, H3, H4: 4mm; MountingHole_3.2mm_M3_Pad_Via
J5: Conn_01x04_Female; Molex_Mini-Fit_Jr_5566-04A_2x02_P4.20mm_Vertical
J6: ATX24pin; Molex_Mini-Fit_Jr_5566-24A_2x12_P4.20mm_Vertical
J7: ATXP8; Molex_Mini-Fit_Jr_5566-08A_2x04_P4.20mm_Vertical
J14: Conn_02x01; Molex_Mini-Fit_Jr_5566-02A_2x01_P4.20mm_Vertical
J15: Fan connector; FanPinHeader_1x04_P2.54mm_Vertical
TP5: 3V3bus; TestPoint_Pad_1.0x1.0mm
TP12: 5Vbus; TestPoint_Pad_1.0x1.0mm
U1: Compute_Module_4_Functional; Raspberry-Pi-4-Compute-Module
U4, U13: AP22804AW5; SOT-23-5

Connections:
3V3bus: C77.1, C78.1, C79.1, J5.4, TP5.1, U4.1 (OUT); also elsewhere on the board
3V3mcu: U1.84 (CM4_3.3V_Out_1), U1.86 (CM4_3.3V_Out_2); also elsewhere on the board
5Vsb: J6.9, U1.77 (+5V), U1.79 (+5V), U1.81 (+5V), U1.83 (+5V), U1.85 (+5V), U1.87 (+5V); also elsewhere on the board
+5V: C53.1, J6.4, J6.6, J6.21, J6.22, J6.23, J14.1, U13.4 (EN), U13.5 (IN); also elsewhere on the board
+12V: J7.5, J7.6, J7.7, J7.8, J15.2; also elsewhere on the board
/GPIO/PS_ON: J6.16; also elsewhere on the board
/cm4/PG: J6.8; also elsewhere on the board
unnamed: J6.10, J6.11
VBUS: C62.1, C63.1, C64.1, C65.1, J5.1, TP12.1, U13.1 (OUT); also elsewhere on the board


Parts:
C61: 100n; C_0402_1005Metric
J1: RJMG2310228A0ER
J10: Conn_02x08_Odd_Even; IDC-Header_2x08_P2.54mm_Vertical
J13: USB_B_Micro; USB_Micro-B_Amphenol_10103594-0001LF_Horizontal
RN11: 4x1k8; R_Array_Concave_4x0402
RN19: 4x39; R_Array_Concave_4x0402
U1: Compute_Module_4_Functional; Raspberry-Pi-4-Compute-Module
U6: FSUSB30MUX; MSOP-10_3x3mm_P0.5mm

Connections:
/CAM_GPIO: U1.97 (Camera_GPIO); also elsewhere on the board
/GPIO/ACT_LED: U1.21 (~Pi_nLED_Activity); also elsewhere on the board
/SCL0: U1.80 (I2C_SCL0); also elsewhere on the board
/SDA0: U1.82 (I2C_SDA0); also elsewhere on the board
/cm4/BT_disable: J10.11, U1.91 (~BT_nDisable)
/cm4/EEPROMprotect: J10.1, U1.20 (EEPROM_nWP)
/cm4/Filtered_3V3: C61.1, RN19.5 (R4.2), RN19.6 (R3.2), U6.10 (VCC)
/cm4/HostDetection: RN11.1 (R1.1), RN11.2 (R2.1), U1.101 (USB_OTG_ID), U6.1 (SEL)
/cm4/LED_Pwr: U1.95 (~PI_LED_nPWR); also elsewhere on the board
/cm4/PG: J10.15; also elsewhere on the board
/cm4/USB_cm4+: U1.105 (USB_P), U6.4 (D+)
/cm4/USB_cm4-: U1.103 (USB_N), U6.6 (D-)
/cm4/USB_ext+: J1.U23 (D+), U6.2 (HSD1+)
/cm4/USB_ext-: J1.U22 (D-), U6.8 (HSD1-)
/cm4/USB_micro+: J13.3 (D+), U6.3 (HSD2+)
/cm4/USB_micro-: J13.2 (D-), U6.7 (HSD2-)
/cm4/WL_disable: J10.13, U1.89 (~WL_nDisable)
/cm4/global_en: J10.7, U1.99 (GLOBAL_EN)
/cm4/nEXTRST: J10.5, U1.100 (~nEXTRST)
/cm4/rpireboot: J10.9, U1.93 (~nRPIBOOT)
/cm4/run_pg: J10.3, U1.92 (RUN_PG)
unnamed: J13.1 (VBUS), RN11.8 (R1.2)
unnamed: RN19.2 (R2.1), RN19.3 (R3.1), RN19.4 (R4.1)
unnamed: RN19.7 (R2.2), RN19.8 (R1.2)
VBUS: J1.U11 (VBUS), J1.U21 (VBUS); also elsewhere on the board

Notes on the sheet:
USB switch device/host
PowerOnly USB
Status connector
PCIe
CM4 special IO
Almost 100 ohm


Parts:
J11: Conn_01x22_MountingPin; SFV22R-1STBE1HLF
J12: HDMI_A; HDMI_RAHHD19TR
U1: Compute_Module_4_Functional; Raspberry-Pi-4-Compute-Module

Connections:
3V3bus: J11.22; also elsewhere on the board
/SCL0: J11.20; also elsewhere on the board
/SDA0: J11.21; also elsewhere on the board
/display/DSI1C+: J11.9, U1.189 (DSI1_C_P)
/display/DSI1C-: J11.8, U1.187 (DSI1_C_N)
/display/DSI1D0+: J11.3, U1.177 (DSI1_D0_P)
/display/DSI1D0-: J11.2, U1.175 (DSI1_D0_N)
/display/DSI1D1+: J11.6, U1.183 (DSI1_D1_P)
/display/DSI1D1-: J11.5, U1.181 (DSI1_D1_N)
/display/DSI1D2+: J11.12, U1.195 (DSI1_D2_P)
/display/DSI1D2-: J11.11, U1.193 (DSI1_D2_N)
/display/DSI1D3+: J11.15, U1.196 (DSI1_D3_P)
/display/DSI1D3-: J11.14, U1.194 (DSI1_D3_N)
/display/HDMI_0+: J12.7 (D0+), U1.158 (HDMI1_TX0_P)
/display/HDMI_0-: J12.9 (D0-), U1.160 (HDMI1_TX0_N)
/display/HDMI_1+: J12.4 (D1+), U1.152 (HDMI1_TX1_P)
/display/HDMI_1-: J12.6 (D1-), U1.154 (HDMI1_TX1_N)
/display/HDMI_2+: J12.1 (D2+), U1.146 (HDMI1_TX2_P)
/display/HDMI_2-: J12.3 (D2-), U1.148 (HDMI1_TX2_N)
/display/HDMI_C+: J12.10 (CK+), U1.164 (HDMI1_CLK_P)
/display/HDMI_C-: J12.12 (CK-), U1.166 (HDMI1_CLK_N)
/display/HDMI_CEC: J12.13 (CEC), U1.149 (HDMI1_CEC)
/display/HDMI_HOT: J12.19 (HPD), U1.143 (HDMI1_HOTPLUG)
/display/HDMI_SCL: J12.16 (SDA), U1.147 (HDMI1_SCL)
/display/HDMI_SDA: J12.15 (SCL), U1.145 (HDMI1_SDA)
VBUS: J12.18 (+5V); also elsewhere on the board

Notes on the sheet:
CM4 display connectors
DSI 4 lanes connector
HDMI connector


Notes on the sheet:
AIN11=5Vsb/2
AIN12=5V/2
AIN13=5Vbus/2
AIN13=12V/5

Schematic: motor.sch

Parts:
C5, C7: 1n; C_0402_1005Metric
C8, C9, C11, C13, C14: 100n; C_0402_1005Metric
C10: 22n; C_0402_1005Metric
C12, C15, C16, C55: 10u; C_0805_2012Metric
R43: 10; R_0402_1005Metric
R44, R50: 0R15; R_1206_3216Metric
RN3: 4x10k; R_Array_Concave_4x0402
TP11: Toright; TestPoint_Pad_1.0x1.0mm
U8: TMC5130A-TA; TQFP-48-1EP_7x7mm_P0.5mm_EP5x5mm_ThermalVias

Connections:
+5V: C9.1, C55.1, R43.1, U8.34 (VCC), U8.39 (VSA); also elsewhere on the board
+12V: C11.2, C13.1, C14.1, C15.1, C16.1, U8.21 (VS), U8.40 (VS); also elsewhere on the board
/GPIO/MOSI: U8.5 (SDI_NAI_CFG1); also elsewhere on the board
/GPIO/MOTOR_SELECT: U8.3 (CSN_CFG3); also elsewhere on the board
/GPIO/SCLK: U8.4 (SCK_CFG2); also elsewhere on the board
/powerIO/8A1: U8.46 (OA1)
/powerIO/8A2: U8.42 (OA2)
/powerIO/8B1: U8.15 (OB1)
/powerIO/8B2: U8.19 (OB2)
/powerIO/9LIML: RN3.7 (R2.2), RN3.8 (R1.2)
/powerIO/9LIMR: RN3.5 (R4.2), RN3.6 (R3.2)
/powerIO/motorU8/BRA: R50.1, U8.44 (BRA)
/powerIO/motorU8/BRB: R44.1, U8.17 (BRB)
/powerIO/motorU8/CPI: C10.1, U8.37 (CPI)
/powerIO/motorU8/CPO: C10.2, U8.35 (CPO)
/powerIO/motorU8/FILTERED_5V: C12.2, R43.2, U8.33 (5VOUT)
/powerIO/motorU8/MISO: TP11.1, U8.7 (SDO_NAO_CFG0); also elsewhere on the board
/powerIO/motorU8/VCP: C11.1, U8.38 (VCP)

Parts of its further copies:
C17, C18, C20, C22, C23, C26, C27, C29, C31, C32, C35, C36, C38, C40, C41, C44, C45, C47, C49, C50: 100n; C_0402_1005Metric
C19, C28, C37, C46: 22n; C_0402_1005Metric
C21, C24, C25, C30, C33, C34, C39, C42, C43, C48, C51, C52, C66, C68, C70, C72: 10u; C_0805_2012Metric
C54, C56, C67, C69, C71, C73, C74, C75: 1n; C_0402_1005Metric
R51, R59, R67, R75: 10; R_0402_1005Metric
R52, R58, R60, R66, R68, R74, R76, R82: 0R15; R_1206_3216Metric
RN2, RN4, RN5, RN6: 4x10k; R_Array_Concave_4x0402
TP13, TP15, TP17, TP19: Toright; TestPoint_Pad_1.0x1.0mm
U9, U10, U11, U12: TMC5130A-TA; TQFP-48-1EP_7x7mm_P0.5mm_EP5x5mm_ThermalVias

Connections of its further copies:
+5V: C18.1, C27.1, C36.1, C45.1, C66.1, C68.1, C70.1, C72.1, R51.1, R59.1, R67.1, R75.1, U9.34 (VCC), U9.39 (VSA), U10.34 (VCC), U10.39 (VSA), U11.34 (VCC), U11.39 (VSA), U12.34 (VCC), U12.39 (VSA); also elsewhere on the board
+12V: C20.2, C22.1, C23.1, C24.1, C25.1, C29.2, C31.1, C32.1, C33.1, C34.1, C38.2, C40.1, C41.1, C42.1, C43.1, C47.2, C49.1, C50.1, C51.1, C52.1, U9.21 (VS), U9.40 (VS), U10.21 (VS), U10.40 (VS), U11.21 (VS), U11.40 (VS), U12.21 (VS), U12.40 (VS); also elsewhere on the board
/GPIO/MOTOR_SELECT: U9.3 (CSN_CFG3), U10.3 (CSN_CFG3), U11.3 (CSN_CFG3), U12.3 (CSN_CFG3); also elsewhere on the board
/GPIO/SCLK: U9.4 (SCK_CFG2), U10.4 (SCK_CFG2), U11.4 (SCK_CFG2), U12.4 (SCK_CFG2); also elsewhere on the board
/powerIO/8LIML: RN2.7 (R2.2), RN2.8 (R1.2)
/powerIO/8LIMR: RN2.5 (R4.2), RN2.6 (R3.2)
/powerIO/9A1: U9.46 (OA1)
/powerIO/9A2: U9.42 (OA2)
/powerIO/9B1: U9.15 (OB1)
/powerIO/9B2: U9.19 (OB2)
/powerIO/9ENCA: U9.25 (ENCA_DCIN_CFG5)
/powerIO/9ENCB: U9.24 (ENCB_DCEN_CFG4)
/powerIO/9ENCN: U9.23 (ENCN_DCO)
/powerIO/10A1: U10.46 (OA1)
/powerIO/10A2: U10.42 (OA2)
/powerIO/10B1: U10.15 (OB1)
/powerIO/10B2: U10.19 (OB2)
/powerIO/10ENCA: U10.25 (ENCA_DCIN_CFG5)
/powerIO/10ENCB: U10.24 (ENCB_DCEN_CFG4)
/powerIO/10ENCN: U10.23 (ENCN_DCO)
/powerIO/10LIML: RN4.7 (R2.2), RN4.8 (R1.2)
/powerIO/10LIMR: RN4.5 (R4.2), RN4.6 (R3.2)
/powerIO/11A1: U11.46 (OA1)
/powerIO/11A2: U11.42 (OA2)
/powerIO/11B1: U11.15 (OB1)
/powerIO/11B2: U11.19 (OB2)
/powerIO/11ENCA: U11.25 (ENCA_DCIN_CFG5)
/powerIO/11ENCB: U11.24 (ENCB_DCEN_CFG4)
/powerIO/11ENCN: U11.23 (ENCN_DCO)
/powerIO/11LIML: RN5.7 (R2.2), RN5.8 (R1.2)
/powerIO/11LIMR: RN5.5 (R4.2), RN5.6 (R3.2)
/powerIO/12A1: U12.46 (OA1)
/powerIO/12A2: U12.42 (OA2)
/powerIO/12B1: U12.15 (OB1)
/powerIO/12B2: U12.19 (OB2)
/powerIO/12ENCA: U12.25 (ENCA_DCIN_CFG5)
/powerIO/12ENCB: U12.24 (ENCB_DCEN_CFG4)
/powerIO/12ENCN: U12.23 (ENCN_DCO)
/powerIO/12LIML: RN6.7 (R2.2), RN6.8 (R1.2)
/powerIO/12LIMR: RN6.5 (R4.2), RN6.6 (R3.2)
/powerIO/motorU8/MISO: U9.5 (SDI_NAI_CFG1); also elsewhere on the board
/powerIO/motorU9/BRA: R58.1, U9.44 (BRA)
/powerIO/motorU9/BRB: R52.1, U9.17 (BRB)
/powerIO/motorU9/CPI: C19.1, U9.37 (CPI)
/powerIO/motorU9/CPO: C19.2, U9.35 (CPO)
/powerIO/motorU9/FILTERED_5V: C21.2, R51.2, U9.33 (5VOUT)
/powerIO/motorU9/MISO: TP13.1, U9.7 (SDO_NAO_CFG0), U10.5 (SDI_NAI_CFG1)
/powerIO/motorU9/VCP: C20.1, U9.38 (VCP)
/powerIO/motorU10/BRA: R66.1, U10.44 (BRA)
/powerIO/motorU10/BRB: R60.1, U10.17 (BRB)
/powerIO/motorU10/CPI: C28.1, U10.37 (CPI)
/powerIO/motorU10/CPO: C28.2, U10.35 (CPO)
/powerIO/motorU10/FILTERED_5V: C30.2, R59.2, U10.33 (5VOUT)
/powerIO/motorU10/LIMITL_RAW: C69.1, RN4.2 (R2.1), U10.8 (REFL_STEP)
/powerIO/motorU10/LIMITR_RAW: C67.1, RN4.3 (R3.1), U10.9 (REFR_DIR)
/powerIO/motorU10/MISO: TP15.1, U10.7 (SDO_NAO_CFG0), U11.5 (SDI_NAI_CFG1)
/powerIO/motorU10/VCP: C29.1, U10.38 (VCP)
/powerIO/motorU11/BRA: R74.1, U11.44 (BRA)
/powerIO/motorU11/BRB: R68.1, U11.17 (BRB)
/powerIO/motorU11/CPI: C37.1, U11.37 (CPI)
/powerIO/motorU11/CPO: C37.2, U11.35 (CPO)
/powerIO/motorU11/FILTERED_5V: C39.2, R67.2, U11.33 (5VOUT)
/powerIO/motorU11/LIMITL_RAW: C73.1, RN5.2 (R2.1), U11.8 (REFL_STEP)
/powerIO/motorU11/LIMITR_RAW: C71.1, RN5.3 (R3.1), U11.9 (REFR_DIR)
/powerIO/motorU11/MISO: TP17.1, U11.7 (SDO_NAO_CFG0), U12.5 (SDI_NAI_CFG1)
/powerIO/motorU11/VCP: C38.1, U11.38 (VCP)
/powerIO/motorU12/BRA: R82.1, U12.44 (BRA)
/powerIO/motorU12/BRB: R76.1, U12.17 (BRB)
/powerIO/motorU12/CPI: C46.1, U12.37 (CPI)
/powerIO/motorU12/CPO: C46.2, U12.35 (CPO)
/powerIO/motorU12/FILTERED_5V: C48.2, R75.2, U12.33 (5VOUT)
/powerIO/motorU12/LIMITL_RAW: C75.1, RN6.2 (R2.1), U12.8 (REFL_STEP)
/powerIO/motorU12/LIMITR_RAW: C74.1, RN6.3 (R3.1), U12.9 (REFR_DIR)
/powerIO/motorU12/MISO: TP19.1, U12.7 (SDO_NAO_CFG0); also elsewhere on the board
/powerIO/motorU12/VCP: C47.1, U12.38 (VCP)

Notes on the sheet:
Protection limit switches
Rsense
Driver

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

Board: 4 copper layers, 170.0 x 65.0 mm, 167 parts (0 on the bottom side), 219 nets.

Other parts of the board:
C2, C3: 100n; C_0402_1005Metric
C4: 10u; C_0805_2012Metric
J4: Conn_02x20_Odd_Even; IDC-Header_2x20_P2.54mm_Vertical
R5: 10; R_0402_1005Metric
RN1: 4x10k; R_Array_Concave_4x0402
RN12, RN13, RN14, RN15, RN16, RN17: 4x150; R_Array_Concave_4x0402
TP2: AinSel; TestPoint_Pad_1.0x1.0mm
U2: MCP3008; SOIC-16_3.9x9.9mm_P1.27mm

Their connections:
3V3bus: J4.2, J4.32; also elsewhere on the board
3V3mcu: C2.1, R5.2; also elsewhere on the board
+5V: RN1.1; also elsewhere on the board
+12V: RN1.3, RN1.4; also elsewhere on the board
/GPIO/+3V3a: C3.1, C4.1, R5.1, U2.15, U2.16; also elsewhere on the board
/GPIO/AIN0: RN1.5, RN1.6, U2.1; also elsewhere on the board
/GPIO/AIN1: RN1.7, RN1.8, U2.2
/GPIO/AIN2: RN16.8, U2.3
/GPIO/AIN2P: J4.3, RN16.1
/GPIO/AIN3: RN16.7, U2.4
/GPIO/AIN3P: J4.4, RN16.2
/GPIO/AIN4: RN16.6, U2.5
/GPIO/AIN4P: J4.5, RN16.3
/GPIO/AIN5: RN16.5, U2.6
/GPIO/AIN5P: J4.6, RN16.4
/GPIO/AIN6: RN17.8, U2.7
/GPIO/AIN6P: J4.7, RN17.1
/GPIO/AIN7: RN17.7, U2.8
/GPIO/AIN7P: J4.8, RN17.2
/GPIO/CS6P: J4.19, RN15.2
/GPIO/CS6_5V: RN15.7; also elsewhere on the board
/GPIO/GPIO8: RN13.7; also elsewhere on the board
/GPIO/GPIO8P: J4.37, RN13.2
/GPIO/GPIO9: RN12.5; also elsewhere on the board
/GPIO/GPIO9P: J4.40, RN12.4
/GPIO/GPIO10: RN12.6; also elsewhere on the board
/GPIO/GPIO10P: J4.35, RN12.3
/GPIO/GPIO11: RN12.8; also elsewhere on the board
/GPIO/GPIO11P: J4.34, RN12.1
/GPIO/GPIO16: RN13.8; also elsewhere on the board
/GPIO/GPIO16P: J4.39, RN13.1
/GPIO/GPIO18: RN13.5; also elsewhere on the board
/GPIO/GPIO18P: J4.38, RN13.4
/GPIO/GPIO24: RN13.6; also elsewhere on the board
/GPIO/GPIO24P: J4.36, RN13.3
/GPIO/GPIO25: RN12.7; also elsewhere on the board
/GPIO/GPIO25P: J4.33, RN12.2
/GPIO/MISO6P: J4.17, RN17.3
/GPIO/MISO6_5V: RN17.6; also elsewhere on the board
/GPIO/MOSI: U2.11; also elsewhere on the board
/GPIO/MOSI6P: J4.21, RN15.1
/GPIO/MOSI6_5V: RN15.8; also elsewhere on the board
/GPIO/PWM0P: J4.23, RN14.4
/GPIO/PWM0_5V: RN14.5; also elsewhere on the board
/GPIO/PWM1P: J4.25, RN14.3
/GPIO/PWM1_5V: RN14.6; also elsewhere on the board
/GPIO/RxD0P: J4.13, RN17.4
/GPIO/RxD0_5V: RN17.5; also elsewhere on the board
/GPIO/SCL6: RN14.7; also elsewhere on the board
/GPIO/SCL6P: J4.29, RN14.2
/GPIO/SCLK: U2.13; also elsewhere on the board
/GPIO/SCLK6P: J4.15, RN15.3
/GPIO/SCLK6_5V: RN15.6; also elsewhere on the board
/GPIO/SDA6: RN14.8; also elsewhere on the board
/GPIO/SDA6P: J4.30, RN14.1
/GPIO/TxD0P: J4.11, RN15.4
/GPIO/TxD0_5V: RN15.5; also elsewhere on the board
unnamed 264: U2.12; also elsewhere on the board
VBUS: J4.10, J4.28; also elsewhere on the board

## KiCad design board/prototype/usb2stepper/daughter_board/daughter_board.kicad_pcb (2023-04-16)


Board: 2 copper layers, 25.0 x 25.0 mm, 11 parts (0 on the bottom side), 17 nets.

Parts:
C2, C4, C6, C7: 100n; C_0402
C3: 2u2 16V; C_0402
C5: 22n; C_0402
H1, H2: 2.5mm; MountingHole_2.2mm_M2_ISO7380_Pad
IC1: TMC2209-LA; QFN-28-1EP_5x5mm_Pitch0.5mm_EP3.7x3.7
J1, J2: Conn_01x09_Male; Pin_Header_Straight_1x09_Pitch2.54mm_SMD_Pin1Left

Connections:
+3V3: C2.2, IC1.15, J2.6
/DIR: IC1.19, J2.1
/MS1: IC1.9, J2.7
/MS2: IC1.10, J2.8
/OA1: IC1.24, J1.4
/OA2: IC1.21, J1.2
/OB1: IC1.26, J1.6
/OB2: IC1.1, J1.8
/STEP: IC1.16, J2.4
/UART: IC1.14, J2.5
/VREF: IC1.17, J2.3
GND: C2.1, C3.2, C6.1, C7.1, H1.1, H2.1, IC1.2, IC1.3, IC1.7, IC1.13, IC1.18, IC1.20, IC1.23, IC1.25, IC1.27, IC1.29, J1.1, J1.5, J1.9, J2.2, J2.9
unnamed: C3.1, IC1.8
unnamed: C4.1, IC1.6
unnamed: C5.1, IC1.5
unnamed: C5.2, IC1.4
Vdrive: C4.2, C6.2, C7.2, IC1.22, IC1.28, J1.3, J1.7

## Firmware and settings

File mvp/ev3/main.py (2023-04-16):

import socket, ujson, sys
import unicodedata
from time import sleep, time

from pybricks.ev3devices import (Motor, TouchSensor, ColorSensor,
                                 InfraredSensor, UltrasonicSensor, GyroSensor)
from pybricks.parameters import (Port, Stop, Direction, Button, Color,
                                 SoundFile, ImageFile, Align)

# print("gyro")
# gyro = GyroSensor(Port.S2)
print("US")
us = UltrasonicSensor(Port.S2)
# if len(sys.argv) != 2:
#     sys.exit("Port?")

motor = {}
for key, port in (("inertia", Port.C), ("length", Port.B)):
    try:
        motor[key] = Motor(port)
        print(key, "initialized")
    except OSError:
        print(key, "uninitialized")
        motor[key] = None

torque_sensing = {"inertia" : 50,
         "length" : 40,
         "lock" : 30}

decode_instruction = {
    'epaule' : (-90*70, Stop.COAST),
    'pince' : (180*11, Stop.COAST),
    'bassin' : (30*47, Stop.COAST),
    'coude' : (-180*23, Stop.COAST),
}

def wait_until_finished(channel, stop_type=Stop.COAST, stop_when_pressed=False):
    global motor
    print("waiting for completion")
    if not motor[channel]:
        print("wait_until_finished:", channel, "desactivé")
        return
    local_motor = motor[channel]

    sleep(1)

    pressed = False
    while True:
        if abs(local_motor.speed()) <= 1.:
            break
        if stop_button.pressed():
            if stop_when_pressed:
                break
            else:
                pressed = True
        elif pressed:
            break
    if stop_type == Stop.COAST:
        local_motor.stop()
    elif stop_type == Stop.HOLD:
        local_motor.hold()
    elif stop_type == Stop.BRAKE:
        local_motor.brake()
    print("completion")

def init_motor(channel):
    global motor, torque_sensing, decode_instruction
    if not motor[channel]:
        print("init:", channel, "desactivé")
        return
    torque = torque_sensing[channel]
    local_motor = motor[channel]

    amplitude = decode_instruction[channel][0]
    if amplitude > 0:
        local_motor.dc(torque)
    else:
        local_motor.dc(-torque)
    wait_until_finished(channel, Stop.COAST, True)
    local_motor.reset_angle(0)
    print("init:", channel)
    local_motor.run_target(500, -amplitude * 10. / 100., Stop.COAST, False)
    wait_until_finished(channel)
    print("init:", channel)

def init_socket():
    global server
    global bot, bot_addr
    print("Creating socket")
    server = socket.socket(socket.AF_INET, socket.SOCK_STREAM)
    print("Opening port")
    host = "ev3dev.local"
    port = int(sys.argv[1])
    server.bind((host, port))
    print("Waiting for connection...")
    server.listen(5)
    bot, bot_addr = server.accept()
    print("Connected")

#for channel in ("lift",):
#    init(channel)
#    set_angle(channel, 0., 1000.)

def receive():
    buffer = bot.recv(4096)
    try:
        return ujson.loads(buffer.decode())
    except ValueError:
        raise ValueError("Impossible to decode '" + buffer.decode() + "'")

def send(data):
    global bot
    bot.send(ujson.dumps(data).encode())

def parse_int(string):
    try:
        return int(string)
    except ValueError:
        raise ValueError("'" + string + "' n'est pas un nombre")

def strip_accents(s):
    return s.replace('é', 'e').replace('è', 'e').replace('à', 'a')

def main_loop_emojis():
    global motor
    try:
        executed = []
        received = receive()
        for length, channel in received:
            if channel in decode_instruction:
                angle, stop_type = decode_instruction[channel]
                if motor[channel]:
                    executed.append(channel + ' : ' + str(length))
                    motor[channel].run_target(500, angle * float(-length) / 100., stop_type, False)
                    wait_until_finished(channel, stop_type)
                else:
                    executed.append("moteur de " + channel + " deconnecté")
        if not executed:
            send("@Elie : Je n'ai pas compris '" + ':'.join(received) + "'")
        else:
            send("J'ai exécuté : " + ', '.join(executed))
    except ValueError as e:
        send("@Elie : Je n'ai pas compris '" + str(e) + "'")

bot = None
server = None
try:
    while True:
        print(us.distance())


    motor['length'].set_dc_settings(30, 0)
    motor['length'].run_until_stalled(-100)
    motor['length'].reset_angle(-30)
    motor['length'].set_dc_settings(100, 0)
    motor['length'].run_angle(100, 360*13)
    motor['length'].run_angle(100, 0)
    raise Exception("fini")
    # motor['bassin'].set_run_settings(800, 100)
    # motor['coude'].set_run_settings(800, 400)
    # motor['epaule'].set_run_settings(800, 300)
    # init_motor('epaule')
    # init_motor('coude')
    # init_motor('pince')
    # init_motor('bassin')
    # motor['pince'].run_target(500, -decode_instruction['pince'][0] * 20. / 100., Stop.COAST, False)
    # wait_until_finished('pince')
    # motor['pince'].reset_angle(0)
    # init_socket()
    # while True:
    #     main_loop_emojis()


    # start_time = time()
    # previous_time = start_time
    # current_time = previous_time
    # drift = 0
    # print("measuring drift")
    # while current_time < start_time + 10:
    #     current_time = time()
    #     elapsed = current_time - previous_time
    #     drift += gyro.speed() * elapsed
    #     previous_time = current_time
    # print("drift", drift)
    # drift /= current_time - start_time

    start_time = time()
    previous_time = start_time
    current_time = previous_time
    center_us = 0
    print("measuring center_us")
    while current_time < start_time + 10:
        current_time = time()
        elapsed = current_time - previous_time
        center_us += us.distance() * elapsed
        previous_time = current_time
    print("center_us", center_us)
    center_us /= current_time - start_time

    for i in range(8):
        motor['inertia'].run_target(1000, 300)
        motor['inertia'].run_target(1000, 0)

    previous_speed = 1
    previous_accel = 1
    max_distance = 0
    min_distance = 0
    previous_distance = 0
    previous_direction = 1
    while True:
        distance = us.distance() - center_us
        if distance > max_distance:
            max_distance = distance
        if distance < min_distance:
            min_distance = distance

        direction = distance - previous_distance
        if direction == 0:
            continue

        if direction > 0 and previous_direction < 0:
            print(direction, previous_direction, "left")
            motor['inertia'].run(-700)
        if direction < 0 and previous_direction > 0:
            motor['inertia'].run(700)
            print(direction, previous_direction, "right")

        # speed = gyro.speed() - drift
        # if speed == previous_speed:
        #     continue

        # current_time = time()

        # accel = (speed - previous_speed) / (current_time - previous_time)
        # print(accel)
        # # if accel > 0 and previous_accel < 0:
        # #     motor['inertia'].run_target(1000, -180)
        # # elif accel < 0 and previous_accel > 0:
        # #     motor['inertia'].run_target(1000, 0)

        # # print(angle, avg_angle, angle - avg_angle)
        # previous_speed = speed
        # previous_time = current_time
        # previous_accel = accel
        # print(distance, direction)
        previous_distance = distance
        previous_direction = direction

finally:
    # print("Closing")
    # if bot is not None:
    #     bot.close()
    # if server is not None:
    #     server.close()
    pass

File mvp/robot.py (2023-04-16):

import socket, ujson, sys
import math
import time
#import socket, ujson, sys
from collections import deque
from pybricks.ev3devices import (Motor, TouchSensor, ColorSensor,
                                 InfraredSensor, UltrasonicSensor, GyroSensor)
from pybricks.parameters import (Port, Stop, Direction, Button, Color,
                                 SoundFile, ImageFile, Align)
from threading import Thread

def sendToRapaas(data):
    print("out:" + ujson.dumps(data))

def logToRapaas(msg):
    print(msg)

sendToRapaas("online")

logToRapaas("US")
us = UltrasonicSensor(Port.S2)

motor = {}
for key, port in (("inertia", Port.C), ("length", Port.B)):
    try:
        motor[key] = Motor(port)
        logToRapaas(key + " initialized")
    except OSError:
        logToRapaas(key + " uninitialized")
        motor[key] = None

last_telemetry = time.time()
last_distance = us.distance()
def telemetry():
    global last_telemetry
    global last_distance
    current_time = time.time()
    elapsed_time = current_time - last_telemetry
    if elapsed_time > 0.1:
        distance = us.distance()
        speed = (distance - last_distance) / elapsed_time
        last_distance = distance
        sendToRapaas(['telem', current_time, motor['inertia'].speed(), distance, speed])
        last_telemetry = current_time

def waitForTimeout(timeout):
    start_time = time.time()
    while time.time() < start_time + timeout:
        telemetry()

def waitUntilPeriodStop(period, phase_start, length):
    current_time = time.time()
    start_time = (math.floor(current_time / period - phase_start) + phase_start) * period
    end_time = start_time + length * period
    waitForTimeout(end_time - current_time)

def waitForMotorToStop(motor):
    is_moving = motor.speed() != 0
    while not is_moving:
        telemetry()
        is_moving = motor.speed() != 0
    while is_moving:
        telemetry()
        is_moving = motor.speed() != 0

def waitForOneTick():
    telemetry()

to_execute = deque()
def recvLoop():
    for msg in sys.stdin:
        try:
            to_execute.append(ujson.loads(msg))
        except ValueError:
            logToRapaas("Impossible to decode '" + msg + "'")

recv_loop = Thread(target = recvLoop)
recv_loop.start()

def loop():
    is_moving = False
    period = 5
    offset = motor['inertia'].angle()
    previous_time = time.time()

    current_frequency = 0
    current_amplitude = 0
    next_amplitude = 0
    next_frequency = 0
    transfer_amplitude = 100
    transfer_frequency = 0.5

    previous_is_moving = is_moving
    phase = 0
    while True:
        has_changed = False
        while True:
            try:
                key, value = to_execute.popleft()
            except IndexError:
                break

            has_changed = True
            if key == "oscmod":
                if value == "free":
                    is_moving = False
                    next_frequency = 0
                if value == "fixed":
                    is_moving = True
                    next_frequency = 1/period
            if key == "period":
                period = min(max(float(value), 0.5), 5)
                next_frequency = 1/period
            if key == "kill":
                return

        if has_changed:
            if is_moving:
                next_amplitude = 540 * ((period / 5) ** 1.5)
            else:
                next_amplitude = 0
                current_amplitude = 0
                phase = 0

        current_time = time.time()
        elapsed = current_time - previous_time
        previous_time = current_time

        if is_moving:
            deltaf = elapsed * transfer_frequency
            deltaa = elapsed * transfer_amplitude

            if abs(current_amplitude - next_amplitude) < 2 * deltaa :
                current_amplitude = next_amplitude
            elif current_amplitude < next_amplitude:
                current_amplitude += deltaa
            else:
                current_amplitude -= deltaa

            if abs(current_frequency - next_frequency) < 2 * deltaf :
                current_frequency = next_frequency
            elif current_frequency < next_frequency:
                current_frequency += deltaf
            else:
                current_frequency -= deltaf

            phase += elapsed * current_frequency * 6.28
            internal_angle = current_amplitude * math.sin(phase)

            if not previous_is_moving:
                offset = motor['inertia'].angle() - internal_angle

            motor['inertia'].track_target(internal_angle + offset)
        else:
            motor['inertia'].stop(Stop.COAST)
        previous_is_moving = is_moving
        waitForOneTick()

loop()
